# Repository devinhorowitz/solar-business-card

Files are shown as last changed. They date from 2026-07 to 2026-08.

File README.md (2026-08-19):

# SOLAR-GLOW · DRH

A business card that runs on light. An AVR microcontroller breathes four amber LEDs
*through* the board — a monogram cut into the front copper that glows when the rear LEDs
backlight it through the bare fiberglass — while a pair of indoor solar cells trickle-charge
a supercapacitor bank that holds the charge.

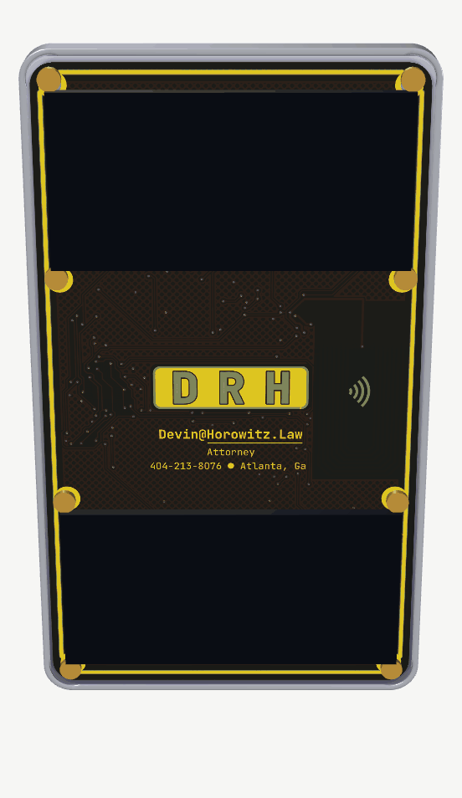
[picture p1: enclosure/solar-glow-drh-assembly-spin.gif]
SOLAR-GLOW · DRH — the assembled card turned over: titanium back-shell, resin brace, PCB, 8× M2 brass


<sub>The assembled card — Ti back-shell, resin diffuser brace, 0.60 mm PCB and eight M2 brass screws.
Not an artist's impression: every surface is the committed STEP-derived STL, the outline and the
eight mount positions come straight out of the `.kicad_pcb`, the Z stack is the one
`enclosure/fit_rules.py` enforces, and the show face is the **raytraced board itself** — the
monogram window, the ENIG, the contactless mark and the contact line are the real artwork, not a stand-in.
Re-route the front and this picture follows. Stills, the exploded and reverse views, and the full
respin are in [`enclosure/README.md`](enclosure/README.md).</sub>

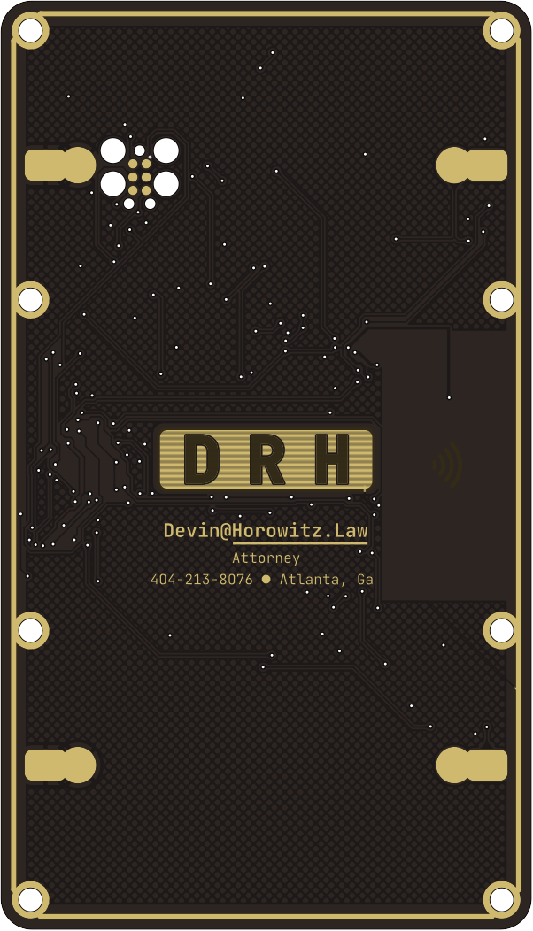
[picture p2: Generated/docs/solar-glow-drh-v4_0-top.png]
SOLAR-GLOW · DRH — front and back, gold ENIG on black soldermask


> **Status: v4.0 (managed-solar redesign) in progress** -- working files are `v4_0`, currently the v3.0
> baseline being reworked to the AEM10300 active-harvest architecture (see the design-notes v4 addendum +
> `v4-aem10300-prewiring.md`). **v3.0 -- fully routed, audit-clean, not yet fabbed -- is frozen as the final
> unmanaged-solar revision.**
> Two-layer, 0.6 mm FR4, bound for PCBWay; the 4-layer **v2.3** is the fallback design, kept in git history (not the working tree).
> The one thing standing between here and a build is the **energy budget** — harvest vs. draw under
> real indoor light has never been measured. See *“The open question.”*

### Current revision — the one canonical summary

| What | Current | Notes / fallback |
|---|---|---|
| **PCB** | **v4.0 - 2-layer** (F / B) | GND = full-board B.Cu pour; VS = routed B mesh. **v2.3 (4-layer: F / In1 GND / In2 VS / B) is the fallback design, in git history.** v2.1 was 6-layer (history). |
| Board | 50.80 × 88.90 mm, r3.0 corners, **0.60 mm** FR4, ENIG, matte-black mask | 0.6 mm — committed in the board stackup (frees the shell floor to 1.0 mm) |
| Mounting holes | **8× M2, GND** -- 4 corner (MH1-4) at **(2.87, 2.87) / (47.93, 2.87) / (2.87, 86.03) / (47.93, 86.03)** (pitch **45.06 × 83.16 mm**) + 4 panel-corner (MP1-4) at **(2.87, 28.63) / (47.93, 28.63) / (2.87, 60.27) / (47.93, 60.27)** | corners concentric with the r3.0 fillets; MP1-4 at the E/W mid-edges for the shell clamp |
| **Enclosure** | **Ti back-shell** - 1.00 floor, 1.80 cavity, overall **3.55 mm**; center support via the single-piece resin diffuser brace. **Respun 2026-07-29 against the real board** — the brace had 593 mm³ of resin inside three supercaps and the shell lip sat on 4.17 mm² of live pad; both geometries are now computed from the board and gated by `check_consistency` **[8]**. | 8-hole pattern (4 corner + 4 panel-corner); see [`enclosure/README.md`](enclosure/README.md) |
| BOM | **generated from the design** — there is no hand-authored master; most passives 0402 with the precision/bulk set on **0603** (C4/C13/C25/C22/C23/R5/R6/R15/R16) and **0805** (C26/C27); **SJ1 removed outright 2026-07-30** (lineage row only); Q2 + R18 added by the cold-start-deadlock fix | line items come from `scripts/bom_split.py` (schematic + the board's own `exclude_from_bom`/`dnp` flags); the buy documents are written into `Generated/fabdocs/` every CI run; live availability + pricing in `BOM/README.md` (`python3 BOM/check_stock.py`). Both `*-BOM.xlsx` masters were culled 2026-08-02 and live in git history |
| Firmware | AVR64EA28 C, register-verified **and compile-verified in CI**; not yet on hardware | LED pin map re-mapped in v3.0 (see `firmware/README.md`) |

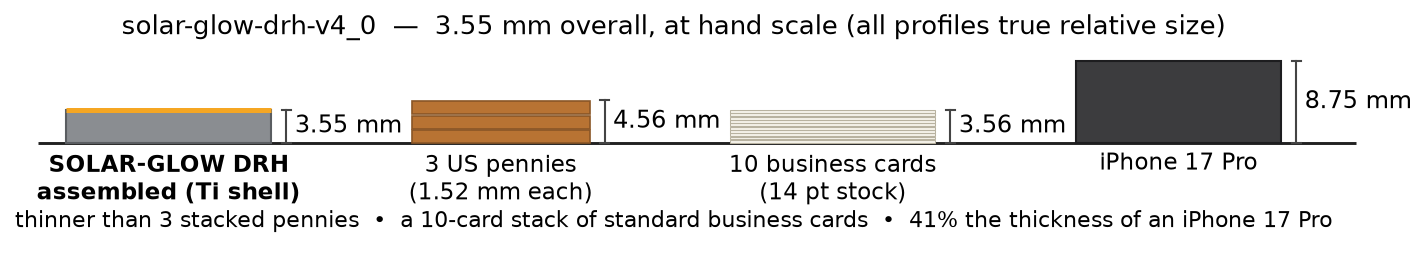
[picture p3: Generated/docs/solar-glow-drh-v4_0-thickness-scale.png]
3.55 mm at hand scale: thinner than 3 stacked pennies, a 10-card stack of business cards, 41% of an iPhone 17 Pro


*How thin 3.55 mm is, in things a hand already knows — thinner than three stacked pennies, almost exactly a ten-card stack of standard business cards, 41% of an iPhone 17 Pro. True relative scale; the card's number is measured from the committed back-shell STL by `scripts/ref_figures.py`, so the figure follows the artifact.*

### Where the truth lives — how these docs stay from drifting

Each fact has exactly one home; everything else points at it rather than restating it.

| Domain | Source of truth |
|---|---|
| Board copper / geometry / holes | `PCB/solar-glow-drh-v4_0.kicad_pcb` + `.kicad_sch` |
| Back-shell medallion (ring text, monogram, serial №) | `enclosure/medallion.py` — the shell generator and its drawing both import it; bump `SERIAL` there and CI regenerates the STEP/STL/drawing (a kibot trigger since 2026-07-31) |
| Fabrication panel (PCBWay) | `scripts/panelize.py` — derived from the board on every CI run into `Generated/panel/`; never hand-maintained |
| README renders | `scripts/render.py` — raytraced from the board/panel on every CI run into `Generated/docs/`; add a target there rather than committing a hand-made image |
| Enclosure **fit rules** | `enclosure/fit_rules.py` — one home for the brace footprint, the lip bands and the boss scallops; both generators import it and check [8] asserts it |
| Enclosure part positions | `enclosure/board_parts.py` — true body ∪ pads, read from the committed `.kicad_pcb` |
| Enclosure geometry | `enclosure/solar-glow-drh-v4_0-backshell-0p6b-brace-cad.py` (prints the Z-stack; regenerates the STEP) |
| Assembly views | `enclosure/assembly_render.py` — regenerated from the STLs + the board; not hand-made |
| Firmware pin map + knobs | `firmware/board.h` (+ `firmware/README.md`; both match the schematic) |
| BOM | **the design itself** — `scripts/bom_split.py` derives every line from the schematic plus the board's `exclude_from_bom`/`dnp` flags, and writes the two buy documents into `Generated/fabdocs/` on each CI run. `BOM/README.md` is **derived too**: a live stock/lifecycle/price table regenerated by `BOM/check_stock.py` (needs distributor API keys, so manual-apply like the mask art). _(There is no spreadsheet master; both `*-BOM.xlsx` files were culled 2026-08-02 — git history only.)_ |
| Design *reasoning* / lineage | `solar-glow-drh-design-notes.md` |
| Open work / cross-domain to-dos | `TODO.md` (an index of what's left; each item points back at the files above) |

When a number here disagrees with a source-of-truth file, the source file wins and this table is the
thing to correct. The `solar-glow-drh-v2-*` docs are v2-era history (banner-marked at the top of
each); read them for lineage, not for current values.

---

## What it is

A business-card-sized PCB — **50.8 × 88.9 mm, 0.6 mm FR4, ENIG, rounded corners** — that:

- **Harvests** indoor light with **two** ANYSOLAR solar cells merged into a single solar node (SRC) that feeds the AEM10300 harvester (U8),
  which runs the MPPT and handles reverse-blocking so neither panel back-feeds the
  other - the v3 per-panel blocking diodes are removed.
- **Stores** energy in **four** series-parallel supercapacitors -- a **hybrid tank** (two larger
  SS17 cells + two WS17), **1.40 F at 5.5 V** — two EQUAL 2.8 F stages (SC1∥SC2 above MID, SC3∥SC4
  below), **≈ 21 J nameplate but 15.1 J stored and 9.8 J spendable** once the AEM's strapped 4.65 V
  `VOVCH` ceiling and the 2.75 V glow floor are applied — with the AEM10300 harvester (U8) balancing
  the series midpoint (MID) against leakage mismatch between those two identical stages; the safe 3.3 V VS rail
  is set by the U9 TPS7A0233 LDO, not a shunt clamp.
- **Glows** by back-lighting a **“DRH” monogram** that’s cut into the front copper: a gold
  ENIG field with the three letters opened to bare FR4. Four reverse-mounted amber LEDs on the
  back fire up through the translucent substrate, so the letters themselves light up — and PWM
  on the LED drives makes them breathe.
- **Wakes** to a **tap.** A 3-axis accelerometer feels you pick the card up (or the enclosure
  being tapped) and interrupts the MCU out of sleep — no button, no moving parts.

The front face stays naked — solar cells and the glowing monogram exposed — and the dense work
all lives on the back, ready for an optional machined-metal back-shell.

> **A note on lineage:** earlier revisions (REV J and before) were *generated from Python* —
> geometry and Gerbers emitted by script, no layout tool in the loop. **v2.1 is a full KiCad
> design** (schematic + board), continued through v4.0. The old generators are kept only as
> history; the KiCad files are the source of truth.

---

## How it works

| Block | Part | Notes |
|---|---|---|
| MCU | **AVR64EA28** (28-VQFN) | TCA0 hardware PWM, I²C to the accel, charge/sleep logic; 2026-07 family swap from the AVR64DD28 (12-bit diff ADC + PGA; no MVIO on the EA, so the DD-era SJ1 strap was deleted outright, 2026-07-30) |
| Solar | **2× ANYSOLAR SM141K06TF** | monocrystalline indoor cells (Voc 4.15 V), in parallel — two panels ≈ 2× the harvest |
| Harvest PMIC | **e-peas AEM10300** (U8, QFN-28 4×4) | MPPT buck-boost that merges both panels at SRC and charges the supercap tank (STO) - replaces the v3 per-panel blocking diodes |
| Storage | **2× SCHURTER 3-153-440** (SS17, 1.8 F) + **2× 3-153-438** (WS17, 1.0 F) | hybrid tank, 2.75 V/cell, wired 2S2P as **two EQUAL 2.8 F stages** (SC1∥SC2 `STO`→`MID`, SC3∥SC4 `MID`→`GND`) → **1.40 F @ 5.5 V**; ≈ 21 J nameplate, **15.1 J stored** at the AEM's strapped 4.65 V ceiling, **9.8 J spendable** above the 2.75 V glow floor. AEM holds MID against *leakage* mismatch between the two identical stages — not a capacitance imbalance; there isn't one |
| Midpoint balance | **AEM10300 (U8) BAL** | the harvester balances the 2S supercap midpoint (MID net) - replaces the v3 ALD910025 dual SAB MOSFET |
| Rail regulator | **TI TPS7A0233PDQNR** (U9, X2SON-4 since 2026-08-05) | nanopower LDO (~25 nA Iq) regulates STO down to the fixed **3.3 V VS rail** the MCU + accel run on - replaces the v3 TLV3011 + PNP shunt clamp |
| LEDs | **4× ams OSRAM LA P47F** (amber) | reverse-mount; glow through the FR4 window, **150 Ω** ballast each |
| LED master switch | **SW2** (solder-bridge) | OFF / ON — bridged feeds `ANODE` straight from `STO`, open is a true hardware off _(the TINY dim position and its R12 shared ballast were deleted 2026-08-05; PWM duty owns dimming)_ |
| Motion | **ADI ADXL367** | 3-axis accel; tap / double-tap wakes the MCU via interrupts; 0.89 µA (swapped from LIS2DH12 on backorder) |
| Light sense | **R5 / R6 divider → PD2** | SRC ÷ 2 off the *merged solar input* (not the rail) - tracks light directly; doubles as wake-on-light |
| NFC | **NXP NT3H2211** (NTAG I²C plus 2K) | present from v3.0 - a contact **vCard** a phone taps to save; field-detect (FD, PA6) also wakes the glow - I²C `0x55`, shares the accel's bus; VCC **power-gated by `U6`** (`NFC_EN`/PA7, off by default); the **U7 MB85RC512TY FRAM** (I²C 0x50, C28) rides always-on VS parked in its 0.2 µA I²C Sleep mode (the 2026-07-23 back-power fix - see design notes) |

**Breakouts and features:** a **TC2030** Tag-Connect pad (`TC1`) for hands-free UPDI
programming, a backup UPDI header (`J1`), a **5-pad bench strip** on the back east edge
(`TP1` SRC + `JP1` GND/STO/SCL/SDA - bare SMD probe pads for bench power injection and an I²C
tap; pinout in `solar-glow-drh-v2-hardware.md`), and **eight grounded M2 mounting holes** (four corners + four panel-corner at the E/W mid-edges). (The `SB1–4`
bridges — per-LED **force-on**, not "disable" as this line long said — were deleted with TINY mode on 2026-08-05. The DD-era
VDDIO2 tie jumper `SJ1` is gone — DNP'd at the AVR-EA swap, deleted from the schematic and board outright on 2026-07-30. The v2-era
`JP1`/`JP2` 2.54 mm breakout headers are gone; the `JP1` name is reused for the strip.)

Full part numbers, pricing, and per-part datasheet links are in
**[`BOM/README.md`](BOM/README.md)** - the live availability table (generated; there is no spreadsheet
master, both `*-BOM.xlsx` files were culled 2026-08-02 into git history): every orderable line carries a
live-verified distributor P/N, stock and price, re-checked by `BOM/check_stock.py` rather than typed. **U6 is moving to
TPS22916CYFPR** (DSBGA-4 YFP, 0.5 mm max — the 2026-08-06 ultrathin swap; schematic done, board sync pending — see
`PCB/README.md`'s BOM table. It succeeds the TPS22919 SC-70 that landed 2026-08-05 — itself the leakage upgrade over
the `TPS22917DBVT` — trading +8 nA typical OFF-state leakage for 0.6 mm of height and a 16× better ON-state IQ,
so every component clears 1.1 mm for the ultrathin-card option) with **R14 (1 M `NFC_EN` pulldown)**; the stale
JP1/JP2 rows are dropped (the `JP1` designator is reused in v3.0 for the bench pad strip - bare pads,
no BOM part). Passives are X7R / AEC-Q200 / precision grade: most on **0402** lands, with the
stability upsizes on 0603 (C22/C23, R5/R6, R15/R16, plus the bulk caps C4/C13/C25) and 0805
(C26/C27, and C9's NFC tank cap — fitted 47 pF, derived not trimmed). SJ1 is culled. Lineage: v2.2 added the NFC parts (U5 / C8 / C9 / R13); the `v2 2` and older
BOM files stay in the repo as history.

---

## The board

- **Two copper layers** on 0.6 mm FR4 (v3.0): **F.Cu** signal/parts and **B.Cu**. **GND is a
  full-board B.Cu pour** (`GND_B` zone) with stitch straps, and **VS is a routed mesh on B** — the
  4→2-layer conversion of v2.3, whose internal GND/VS *planes* moved onto the back copper. The
  4-layer **v2.3** (F · In1 GND · In2 VS · B) is the fallback (recoverable from git history) if the
  back-side trace texture showing faintly on the naked front reads wrong.
- **The glow window is a keepout on every layer.** The monogram cutout and the four LED
  light-paths are voided through both layers so nothing — copper pour, trace, or via —
  shadows the light between the rear LEDs and the front face. The rear soldermask is left
  *open* over the window on purpose: bare ENIG reflects the LEDs’ light forward instead of
  absorbing it.
- **Rail discipline.** The supercap stack can sit near 5.5 V, but the accelerometer tops out at
  3.6 V - so the **U9 TPS7A0233 LDO** regulates the supercap tank (STO) down to the fixed
  **3.3 V VS rail**, directly bounding what the accelerometer sees. Its ~25 nA quiescent
  draw is negligible against the other always-on loads, and it regulates VS itself rather
  than the solar input. (v3's TLV3011 + PNP shunt clamp and the per-panel blocking diodes
  are gone - the AEM10300 now owns the harvest path.)
- **Power planes** carry the supercap charge/discharge currents; the four cells eat the better
  part of the back, so the layout is geometry-bound and the planes earn their layers.

---

## The open question — read this before building a batch

The board is well-verified; the **energy budget is not.** A solar cell’s headline rating is a
full-sun number, and indoor light delivers a small fraction of it, while four breathing LEDs
average several milliamps. The two-panel harvest and the tank — **9.8 J spendable**, not the 21 J
nameplate — are sized to **harvest
slowly and glow in bursts** — but that bet has never been put on a meter.

What changed the math since the early notes: the LED string is fed from the **STO supercap tank** (through the
SW2 anode switch), which the AEM10300 holds at up to **4.65 V** (VOVCH), and the ballasts are **150 Ω** -- so each
LED peaks near **~16 mA** at a full tank ((4.65 V - amber Vf ≈ 2.25 V)/150 Ω, the figure `firmware/README.md`
quotes), sagging toward zero as STO discharges. (VS, the regulated 3.3 V LDO output, powers the MCU and accel,
not the LEDs.) Four on at once is a real load against an indoor harvest measured in fractions of a milliamp.

**First move when boards arrive:** put the cells under your actual target lighting and measure
**harvest current against LED draw** before you populate a full stack. That single number sizes
the duty cycle, the feature set, and whether the always-on accelerometer earns its microamps.

---

## Repository layout

```
solar-business-card/
├── README.md                       # this file (canonical current-revision summary)
├── PCB/                            # KiCad projects
│   ├── solar-glow-drh-v4_0.kicad_pcb   # the board: v4.0 managed-solar rework (AEM10300), 2-layer (source of truth)
│   ├── solar-glow-drh-v4_0.kicad_sch   # schematic: synced to the v4.0 board netlist
│   └── README.md                       # order & build guide
├── BOM/                            # bill of materials (moved from PCB/ 2026-08-01)
│   ├── README.md                       # GENERATED live availability/price table (check_stock.py)
│   ├── check_stock.py                  # live DigiKey/Mouser availability check -> README.md
│   └── README.md                       # DERIVED: stock/lifecycle/price table with red-X dead lines (regenerate, don't edit)
├── solar-glow-drh-design-notes.md  # design rationale, energy model, lineage (incl. the v3.0 chapter) — the one prose file that stays at root, beside this README
├── docs/                           # project notes & records (moved from root 2026-08-01) + the LED sweep tuner
│   ├── solar-glow-drh-v2-hardware.md    # as-built wiring & pin map (v2-era lineage; banner at top)
│   ├── solar-glow-drh-v2-mechanical.md  # board mechanics, keepouts, access (v2-era lineage; banner at top)
│   ├── v4-aem10300-prewiring.md         # the v4 net/pin plan — applied 2026-07-30, kept as the record
│   ├── v4-schematic-sync-checklist.md   # the sch→board sync procedure — DONE, kept as the record
│   ├── harvest-bench-fixture-handoff.md # the energy-budget bench fixture (the #1 open gate's rig)
│   ├── harvest-budget-test-board.md     # the harvest test-board concept
│   ├── eink-display-variant-notes.md    # e-ink variant study (concept, not adopted)
│   ├── firmware-to-pcb-open-items.md    # v3-era cross-team memo (SUPERSEDED; record only)
│   ├── mcp-setup.md                     # sourcing MCP servers setup (DigiKey/Mouser)
│   ├── kicad-happy.md                   # the external second-opinion analyzer: pinned run recipe + the 2026-08-01 baseline triage
│   ├── thomsonlint.md                   # the ontology-guided second reviewer: pinned run recipe + the 2026-08-01 review record
│   └── led-sweep-tuner.html             # interactive LED-constant sandbox (firmware/README links it)
├── firmware/                       # bare-metal C (AVR64EA28); compile-verified, see firmware/README.md
├── bench/                          # pogo-plate bench monitor: Pico firmware + host dashboard (see bench/monitor)
├── datasheets/                     # fitted parts + documented substitutes, named "REF  MPN  $price.pdf"
│                                   #   (survey sheets and replaced-part docs culled 2026-08-01 — git history)
├── enclosure/                      # Ti back-shell + resin brace: CAD / STEP / STL / drawings / assembly views
│                                   #   fit_rules.py + board_parts.py = the geometry both generators derive from
└── (v0-prototype/ and enclosure/engraving-studies/ culled 2026-08-02 — concluded history, kept in git history; the medallion the studies produced ships in enclosure/medallion.py)
```

---

## Building the board

The board is a KiCad project — open it, run DRC, and export the fab set:

1. Open `solar-glow-drh-v4_0.kicad_pro` in **KiCad** (2026 file format).
2. **Run DRC.** It comes back clean apart from the intentional exceptions catalogued in
   `PCB/README.md` and `solar-glow-drh-design-notes.md` (the NFC coil `LA`↔`LB` short, the eight
   GND-tie mounting-hole/gold-frame contacts, the two plating-bus stubs crossing Edge.Cuts at
   x=25.4, the illumination copper inside the glow window, and the benign `lib_footprint_issues`
   plus the **intentional** `BTN` global label on PA5 — the documented future-button pin
   (a deliberate no-fit; recipe in `firmware/README.md`), not a loose end). Fill zones (press **B**) before checking.
3. **Plot Gerbers + drill** from KiCad's own Fabrication Outputs and order from **PCBWay**
   (**2-layer**, 0.6 mm; selective hard gold + plating bus + resin-fill/cap per `PCB/README.md`).

> The supercap land is the one thing to never get wrong. **Both** SCPC cells — the 39 mm
> **SS17** (SC1/SC3) and the 28.5 mm **WS17** (SC2/SC4) — solder to **flat pads under the body**
> (the asymmetric P/N widths are the polarity key), **not** to the folded end tabs, which are
> non-solderable mechanical locators. The footprints here are built to the correct under-body
> land; don't substitute an end-tab land.
>
> Mind the two lengths. Assuming every cell was the 28.5 mm WS17 is exactly what put 593 mm³ of
> brace inside SC1 and SC3 — see [`enclosure/README.md`](enclosure/README.md).

---

## Assembly order (when boards arrive)

1. **Validate the energy budget first** — harvest vs. LED draw under real lighting (above).
2. **Reflow the SMD parts** — the QFN MCU and the LGA accelerometer need hot air / a hotplate;
   the EP and the accel pad reflow to their planes.
3. **Flash firmware** over UPDI — the Tag-Connect pad (`TC1`) is the no-header path; `J1` is the
   backup header. **This step moved ahead of the cells on 2026-07-30**, when TC1 was deliberately
   moved to `F.Cu`: PV1's body covers the pad cluster, so a pogo cable cannot reach it once the
   cell is on. The trade is a good one — the old position was under `SC1`, which is *reflowed*, so
   the window used to close before the board was even finished. See the warning box in
   [`PCB/README.md`](PCB/README.md).
4. **Hand-solder last** — the solar cells (heat-sensitive: ≤ 260 °C / 2 s, no IPA), and set the
   **SW2** bridge: bridged = ON, open = OFF.

---

## Firmware

A first implementation now lives in **`firmware/`** — bare-metal C, **verified at the register
level** against the AVR64EA28 and ADXL367 datasheets and **compile-verified in CI** (warning-free
against the AVR-Ex DFP; not yet run on hardware). Its knobs, wake model, and power notes are in
**`firmware/README.md`** (authoritative); the wiring it targets is **`firmware/board.h`**, which
`check_consistency` **[1]** holds against the schematic netlist pin by pin. (The complete v2-era
pin map in **`solar-glow-drh-v2-hardware.md`** is lineage, not a current source — see the truth
table above.) Final
duty-cycle and feature tuning stay **gated on the energy-budget measurement** below. In short,
the board gives it:

- **LED breathing** — the four LEDs sink into **PA0–PA3 = TCA0 WO0–WO3**, so split-mode PWM
  drives all four as independent 8-bit channels (the 150 Ω ballast sets the peak; PWM sets the
  average, so you trim brightness *below* that ceiling).
- **Tap-to-wake** — the accelerometer’s two interrupts land on **PF1 / PF0**; configure
  tap / double-tap and let it pull the MCU out of sleep.
- **NFC contact tag** — `U5` (NXP NT3H2211, on the board from v3.0) carries a **vCard** a phone reads on a
  tap to save the contact (RF-powered, so it reads with the cap flat), and its **field-detect**
  line wakes the same glow. The tag has no sleep state and would draw **~195 µA** continuously — the
  card's largest idle load — so firmware **power-gates** its VCC through a load switch (`U6`) on
  **NFC_EN (PA7)**, held **off by default** and raised only around an I²C access; the vCard read and
  the FD-wake both run on the phone's field power, so they still work with the tag's VCC off. Shares
  the I²C bus with the accel (`0x55` vs `0x1D`). See `firmware/README.md` → *NFC contact card*.
- **Light sensing** - the divider taps the **merged solar node SRC** (SRC ÷ 2) into **PD2** (AIN2), so it
  reads light directly — ~0 V dark, rising under light; firmware adapts the glow to available
  light and can also read **VDD/10** and the internal temp sensor.
- **Wake-on-light** — the card can also wake when light appears, with no tap. The implemented
  path is an **RTC-timed ADC poll** in deep Power-Down (sample PD2/AIN2 every ~1–2 s, glow on a
  dark→light rise). The tempting *instant* AC0-comparator version was checked against the
  datasheet and found **non-viable on this part** — the AC interrupt doesn't update with the
  peripheral clock stopped, and the AC isn't a Standby/Power-Down wake source, so it would never
  fire. Instant response isn't lost: the accelerometer interrupt wakes from Power-Down, and
  picking the card up to carry it into the light *is* that motion. (Standing current: **≥ ~2.7 µA — a
  2.0 V-referenced lower bound, not a measurement** (the 2026-08-01 pressure test found the NFC tag's
  FD-pin leakage, 1.5 µA typ / 10 µA max, unbudgeted in that sum) — the always-on accelerometer
  (ADXL367, 0.89 µA typ *at 2.0 V*) no longer dominates it, and neither the poll nor the NFC tag do,
  the latter being power-gated off by default — see `firmware/README.md` "Power notes" for the honest
  ledger and the bench item.)
- **Low-power housekeeping** — `VREGCTRL.PMODE = AUTO` for sub-µA power-down; RTC/PIT off the
  internal ULP oscillator (no crystal); an EEPROM “times-activated” counter that survives a
  full supercap drain; and the core **IDLE-sleeps through the breathing glow** while TCA0 keeps
  the PWM running, rather than busy-waiting. (An autonomous CCL + EVSYS light-wake is a possible
  v-next, but isn't what the current firmware does.)

Still open (what the bench measurement unlocks): final breathing-curve and tap-gesture tuning,
charge / brown-out management around the supercap bank, and the duty-cycle adaptation the
harvest number sizes.

---

## Enclosure

A back-only **machined-titanium** shell hugs the populated rear; the front stays naked. A
single-piece **resin diffuser brace** fills the cavity, carries centre support, backs the
monogram window and holds the ferrite over the NFC coil. CAD, STEP, STL, fab notes and
dimensioned drawings are in `enclosure/` — full detail in
[`enclosure/README.md`](enclosure/README.md).

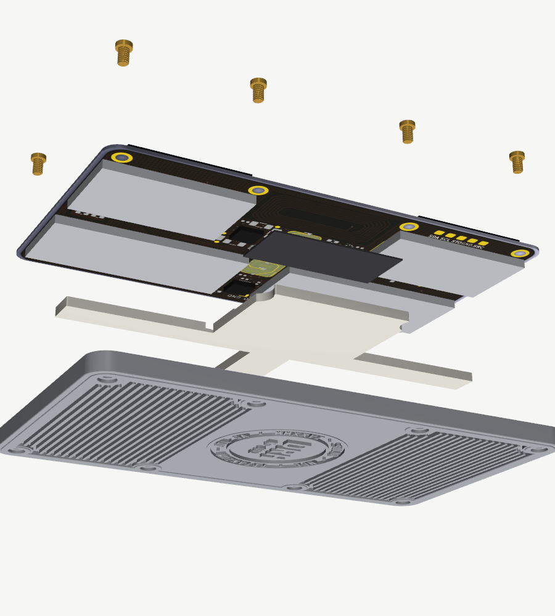
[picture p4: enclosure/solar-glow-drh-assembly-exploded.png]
Exploded: titanium shell, resin brace, PCB, 8× M2 brass


**Respun 2026-07-29 against the real board, because neither part would have assembled.** The
brace's middle band was sized for supercap bays ending at y31.15 / y57.75 — the 28.5 mm WS17
length — while SC1/SC3 are 39 mm SS17 cells, so it put **593 mm³ of solid resin inside three
1.70 mm cans**. The shell's support lip landed on nine B-side parts including **4.17 mm² of
live pad** (`STO`, `STO_LDO`, `VS`, `NFC_EN`) under grounded titanium — fitting it shorted the
storage rail — and five of the eight M2 bosses fouled a part, two on live nets.

Both geometries are now **computed from the board** (`enclosure/fit_rules.py`, reading part
positions from `enclosure/board_parts.py`) rather than hand-placed, and gated by
`check_consistency` **[8]**. Interference is structurally impossible: a part the brace cannot
span is *subtracted* from its footprint rather than pocketed. No board change was required.

The decisions that matter once it's cut: **titanium (Ti-6Al-4V Grade 5)**, **3-axis CNC-milled**
by PCBWay, **bead-blast** finish. The cavity is **cap-limited to 1.80 mm** by the four 1.70 mm
supercaps; the floor is a **true uniform 1.00 mm** (the old 0.05 mm U7 relief pocket was deleted
2026-07-28 — U7 is the 0.90 mm DFN-8, not the 1.75 mm SOIC it was sized for); overall height
**3.55 mm**. **Eight** bosses on the v4 8-hole pattern (four corner, concentric with the r3.0
fillets, plus four panel-corner), each **scalloped** clear of whatever fouls it while keeping
≥ 92.3 % of its M2 thread annulus. Retention is **eight M2×3 slotted brass screws**, not a press
fit; the head is Ø3.0 and the tip lands **flush** in a Ø3.0 back spotface.

The electrical gotchas: the screws tie the metal body to board GND, so the enclosed variant
**drops the edge castellations** (or adds a die-cut Kapton layer) so nothing shorts to the
grounded shell; the **accelerometer tap is the actuator** (cap-touch dies behind a grounded
plate); and the east lip is held **1.00 mm clear of NFC coil copper measured at x48.550** — a
grounded feature over the antenna detunes it, and the constant it used to be sized against
(48.40) was optimistic enough to overhang.

---

## Cost

- **Per-board parts cost: see [`BOM/README.md`](BOM/README.md)**, the live table — and the **four supercaps are the dominant line** —
  well over half the BOM. This is a showpiece, not a hand-out-by-the-hundred card.
- The energy tank is where the money goes; everything else is comparatively cheap.

---

*© 2026 Devin R. Horowitz. Released under the [MIT License](LICENSE).*

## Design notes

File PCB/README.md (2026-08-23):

# SOLAR-GLOW · DRH - PCB (v4.0): Order & Build Guide

<table>
<tr>
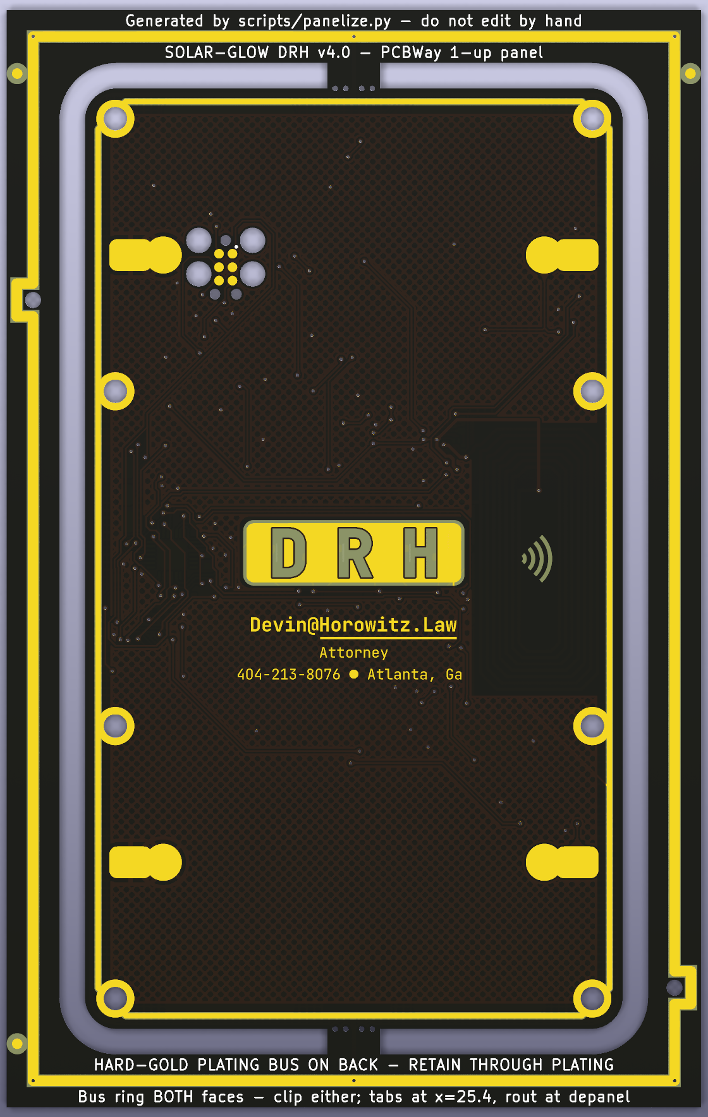
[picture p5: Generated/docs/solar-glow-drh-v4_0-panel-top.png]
Panel, front — the card face, gold monogram on matte black, still in its frame
<td width="50%"></td>
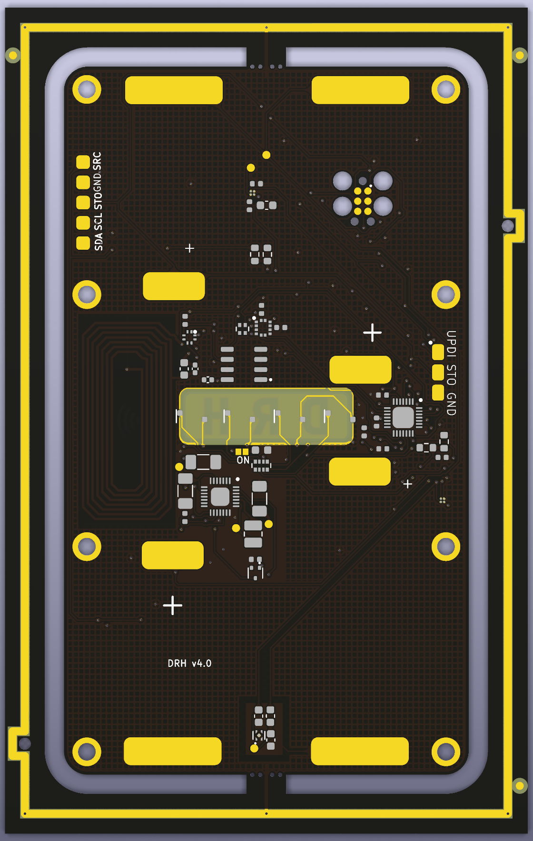
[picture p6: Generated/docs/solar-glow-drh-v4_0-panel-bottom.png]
Panel, back — the component side, NFC coil and LED window, still in its frame
<td width="50%"></td>
</tr>
<tr>
<td align="center"><b>Front</b> — the card face</td>
<td align="center"><b>Back</b> — the component side</td>
</tr>
</table>

**This is what PCBWay ships**: the 1-up card still attached to its 65.6 × 103.7 mm frame, before
you snap the two tabs. The gold ring inset in the frame is the hard-gold plating bus, mask-opened
so the plating rack has bare copper to clip, with a spur crossing each break tab into the card at
x = 25.4. Both faces are raytraced from the panel CI actually generates — see
`scripts/render.py`, and "The PCBWay panel" below. No components are shown because none are
fitted at this stage; that is the fab's deliverable, not an omission.

## Assembled

<table>
<tr>
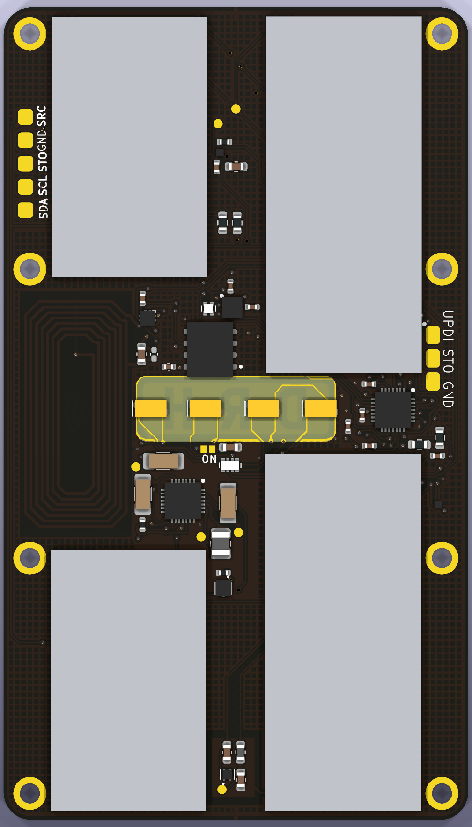
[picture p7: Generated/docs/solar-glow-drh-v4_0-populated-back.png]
Assembled card, back — supercaps, MCU, harvest PMIC, NFC coil and passives fitted
<td width="50%"></td>
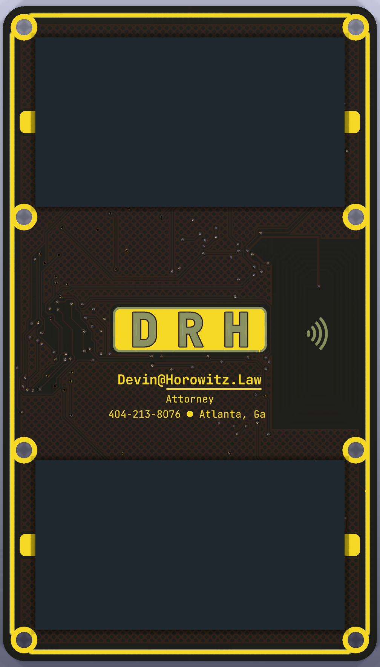
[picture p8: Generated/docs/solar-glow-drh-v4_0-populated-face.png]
Assembled card, front — the two indoor solar cells over the monogram window
<td width="50%"></td>
</tr>
<tr>
<td align="center"><b>Back</b> — 53 fitted parts</td>
<td align="center"><b>Front</b> — the two solar cells</td>
</tr>
</table>

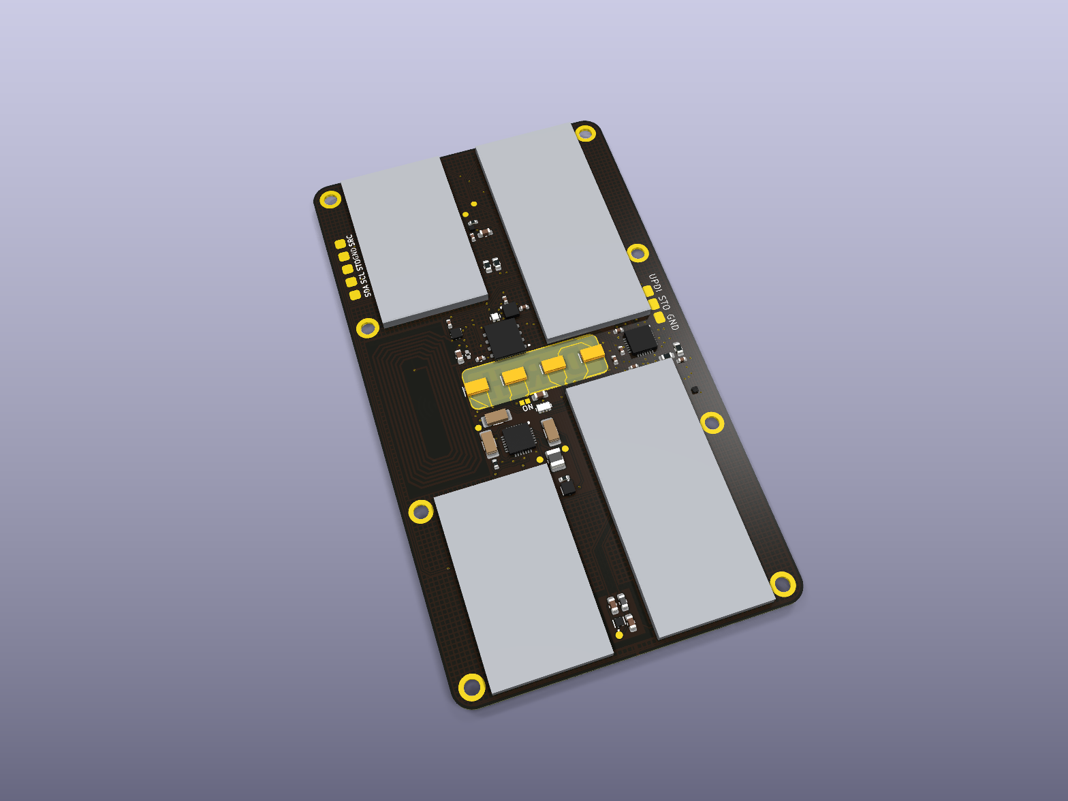
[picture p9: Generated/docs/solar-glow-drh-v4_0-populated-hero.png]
Assembled card, hero angle


The same board with its components on: 52 of the 73 footprints carry a 3D body, which is every part
that actually gets populated (recounted 2026-08-05 after SB1–4 and R12 left with TINY mode; the
2026-08-01 count was "53 of 78"). The other 21 are the drill/mount set (MH1–4, MP1–4, `NPTH_mech`),
the SW2 solder bridge, the bare programming and probe lands (TC1, `TC1/b`, TP1–TP7, JP1),
and **J1**, which is DNP.

> **Read the big grey slabs as ENVELOPES, not as photographs.** The four supercaps, the two solar
> cells, the LEDs, both QFNs, the FRAM, the accelerometer and the NFC tag are **clearance solids**
> generated by `scripts/make_3d_models.py` — each is its part's maximum outline at its **maximum**
> height, because the question they exist to answer is "does the brace clear it?" and a pretty model
> at the wrong height would be worse than useless. They are not appearance references. The chip
> passives and SOT-23s are stock KiCad models and do look roughly like the real parts.
>
> The supercap **locator tabs are deliberately absent** — see `TODO.md`; their real folded geometry
> has never been measured, so the envelope near the two short edges is unverified.
>
> **Every body you see is rendered from this repo, not from a KiCad install.** The nine stock models
> live in `PCB/kicad-3dmodels/` because the image CI renders in carries no 3D library at all — that
> was measured, not assumed (`models: 15/53 resolve ... NO stock 3D library found`), and it is why an
> earlier version of this render was missing every chip passive and both SOT-23s. `render.py` points
> `${KICAD10_3DMODEL_DIR}` at the vendored copy when the host has none, and consistency check [5]
> fails if a new part references a stock model nobody vendored.

---

This folder holds the **board** for SOLAR-GLOW · DRH — the KiCad project, the bill of
materials, and the artwork reference for the SW2 selector. It is the thing you fab and
populate. This README is the procedure: **how to order the bare PCB, how to order the
parts, and how to build the assembly.**

> **One revision lives here.** As of 2026-07-28 that is **v4.0**; the seven `*-v3_0.*` files
> (board, schematic, project, prl, dru, and both BOMs) were removed, the same way v2_1–v2_3 were
> before them. Superseded revisions are kept by git, not by this folder — carrying a second 1.6 MB
> board around only invites someone to open the wrong one. To get one back:
> ```sh
> git log --diff-filter=D -- PCB/solar-glow-drh-v3_0.kicad_pcb   # the commit that removed it
> git show <sha>^:PCB/solar-glow-drh-v3_0.kicad_pcb > /tmp/v3.kicad_pcb
> ```
> **`enclosure/solar-glow-drh-v4_0-backshell-*` is unaffected.** Those files are current and
> fab-ready. _(They carried `v3_0` names until 2026-08-19 — the revision the shell was first cut
> against — and this note used to explain why that was fine. It stopped being fine when the
> DRAWING generator was found stamping **`REV v3.0`** into the title block of the sheet a
> machinist cuts to; a stale revision on a fab document is not a naming preference. Renamed and
> re-stamped to v4.0 in one commit. The v4 board carries the identical 8-hole pattern, so the
> geometry never moved.)_

```
PCB/
├── solar-glow-drh-v4_0.kicad_pro     # KiCad project (open this)
├── solar-glow-drh-v4_0.kicad_sch     # schematic
├── solar-glow-drh-v4_0.kicad_pcb     # board — 2-layer, routed, teardropped (source of truth)
├── solar-glow-drh-v4_0.kicad_prl     # local project state — versioned DELIBERATELY (the GUI layer setup travels with the project; unlike Generated/'s prl side-effect, which was culled 2026-08-01)
├── solar-glow-drh-v4_0.kicad_dru     # two-tier design rules (PCBWay floor + marginal band)
├── solar-glow-drh.kibot.yaml         # CI recipe — regenerates ../Generated/ on every push
│                                     # (the BOM masters moved to ../BOM/ on 2026-08-01, beside the live
│                                     #   stock checker; the tree line here that called the assembly xlsx
│                                     #   "stale at its 36-row era" was itself stale — the file was rebuilt
│                                     #   2026-07-30 at the 47-part placed set, see ../BOM/)
├── kicad-3dmodels/                   # the 9 stock KiCad .step bodies this board uses, mirroring the
│                                     #   library layout (CC-BY-SA 4.0, licence bundled). CI's render
│                                     #   image ships NO 3D library, so without these the assembled
│                                     #   render silently loses 38 of 53 component bodies.
└── DRC.rpt                           # last GUI DRC export (user-refreshed at board edits; CI keeps the live
                                      #   reports in ../Generated/. ERC.rpt was culled 2026-08-01 — its 07-27
                                      #   export had outlived two schematic generations; read Generated/…-erc.html)
                                      # (v2_1 / v2_2 / v2_3 / v3_0 revisions live in git history, not this folder)
```

> **The board is the source of truth.** `solar-glow-drh-v4_0.kicad_pcb` / `.kicad_sch`
> govern. The design *reasoning* lives one level up:
> - `../firmware/board.h` + `../firmware/README.md` - as-built pin map and net list (the firmware target); `../docs/solar-glow-drh-v2-hardware.md` is frozen v2 lineage only.
> - `../docs/solar-glow-drh-v2-mechanical.md` — board envelope, heights, mount holes, keepouts.
> - `../solar-glow-drh-design-notes.md` — why each decision was made; the landmines.
> - `../README.md` — the project overview and the standing open question (energy budget).
>
> Where a number here and a number in those files ever disagree, re-read the `.kicad_pcb`.

> **Read this before committing money: the energy budget has never been measured.** Harvest
> under real indoor light versus four breathing LEDs at the current 150 Ω ballast is an
> unproven bet. It does not stop you fabbing one board — it stops you populating a *batch*.
> See **First power & bring-up** below and `../solar-glow-drh-design-notes.md` §2.

---

## Board at a glance

| Parameter | Value |
|---|---|
| Outline | 50.80 × 88.90 mm rounded rectangle, **3.0 mm corner radius** |
| Layers | **2 copper**: F.Cu (cells, plating ties, monogram art) · B.Cu (everything else) |
| Power architecture | **GND = full-board B.Cu pour** (~3000 mm²); **VS = routed B.Cu mesh** |
| Finished thickness | **0.6 mm** FR4 |
| Surface finish | **ENIG** + **selective hard (electrolytic) gold** on the F.Cu gold set — the plating bus exists to feed it (see the order special request; the area itself is drawn on `User.1` by `scripts/mask_art.py` and plots into both fab sets) |
| Soldermask | **Matte black**, both sides |
| Silkscreen | White (back-side identifiers / logos); front face is intentionally bare |
| Components | **52 on the back**; the front carries only the two solar cells (PV1/PV2) |
| Teardrops | **Enabled** — **280** curved teardrop zones (pads, vias, and track-ends). _(Was documented as 243, then 298; recounted 2026-08-06 after DRH's Q2/C9/TC1 rework and the U6 DSBGA round — redrawn tracks shed their teardrops, and the U6 VNFC reroute retired a via and its pair.)_ R14 has none, and **the U6 DSBGA has none BY DESIGN — never add them there**: the 0.23 mm balls' pad-to-pad air gap is 0.17 against the 0.152 floor, and a teardrop's flare spends exactly that margin. **Run Tools → Add Teardrops before plotting** to regenerate the rest (the tool's own scope settings leave the BGA alone at its defaults; check it did). |
| NFC | NT3H2211 tag (U5) + **PCB-etched 7-turn coil** on B.Cu, power-gated by U6. Coil stays **under soldermask** — see the note below. A contactless mark on F.Mask over the antenna says the card is NFC-enabled |
| Front ornament | **Generated, not drawn** — `scripts/mask_art.py` opens F.Mask only where the copper beneath is GND, so the routing itself becomes the pattern (gold mesh, dark rivers). 216 mm², narrowest gold aperture 0.122 mm. Re-run `--apply` after any front re-route; consistency check [6] fails if you don't |
| Indicative parts cost | **see `../BOM/README.md`** — the live table, regenerated by `BOM/check_stock.py`, is the only current figure; supercaps + solar cells are ~60 % of it. _(This cell said "≈ $93/board" until 2026-08-04; the generated table summed to $136.60/board, so the prose was 32 % low. A hand-typed price goes stale the moment a distributor moves, which is exactly why the table is generated — do not put a number back here.)_ |

**Glow window — the one feature a fab must not "clean up."** A rectangle at
**x 14.95–35.85, y 40.8–47.0** (≈ 20.9 × 6.2 mm, board center) is a **keepout on both
copper layers** and has the **soldermask opened over it on both faces**. The rear LEDs fire
*through* the bare FR4 to light the front monogram; the open rear mask lets the gold ENIG
reflect that light forward instead of absorbing it. Tracks are allowed inside the window;
**vias, copper pour, and footprints are not.** Do not let a DFM auto-edit flood mask back
over it.

**NFC coil region — the second feature a fab must not "improve."** The east band at
**x 36.8–49.0, y 31.6–57.4** carries the etched antenna: the B.Cu GND pour is kept out of
it, and F.Cu is a keepout over it. The **LA↔LB track crossing at (41.0, 38.0) is the coil's
electrical junction — intentional, not a short.** Any DFM note offering to "fix" the
crossing or to flood the region gets declined.

---

## Step 1 — Open the project and run DRC

1. Open `solar-glow-drh-v4_0.kicad_pro` in **KiCad** (designed in the 2026 file format).
2. Register the footprint library: the board uses a local `solarglow` library that is not
   registered on a fresh machine. Add it under **Preferences → Manage Footprint Libraries**
   (or accept KiCad's prompt) so the footprints resolve.
3. **Run DRC.** The project carries a two-tier rule file (`solar-glow-drh-v4_0.kicad_dru`):
   - **error tier** = the do-not-ship floor (clearance/track ≥ 0.126 mm, annular ≥ 0.125,
     drill ≥ 0.2) — sized against PCBWay's stated 2-layer capability;
   - **warning tier** = the *marginal band* [0.126, 0.1524): PCBWay-legal geometry that is
     tighter than 6 mil, flagged on purpose so the ledger stays visible.

   **Expected result: 0 errors, 11 exclusions** (verify the exclusion count against
   `Generated/solar-glow-drh-v4_0-drc.html`, which CI writes — the catalogue's history lives in
   `CLAUDE.md`). The warning count depends on which severities the run reports: the fresh GUI
   export (`DRC.rpt`, 2026-08-01) reads **3** (the silk-over-copper trio), while CI's
   severity-all html carries the full marginal-band ledger (~61 at last count — the 0.127 mm
   west-bus corridors plus fourteen 0.15 mm track notes). This line used to promise "~61
   warnings" flatly, which only a severity-all run reproduces. The excluded set is the two gold-plating tie stubs crossing the outline, the
   LA↔LB coil junction, the seven supercap NPTHs inside courtyards, and the `TC1/b`↔SC1 courtyard
   overlap — all intentional.
   The footprints that shipped without a courtyard (U1, U8, U5, U3, D2-D5, J1, TC1) now carry
   courtyards + pin-1/cathode markers. The one accepted courtyard overlap is the **`TC1/b`
   Tag-Connect mirror under the SC1 supercap** (its ancestor — the pre-2026-07-30 B-side TC1 over
   the same can — died with the side flip and KiCad pruned the exclusion; the 2026-08-01 mirror
   recreates it deliberately: bare pads under a part body, used only before SC1 is fitted);
   courtyard-overlap is otherwise a hard CI gate. The two proximities this exposed (U8/L2, U1/J1) were resolved in the layout.
   The warnings are the marginal-band ledger (mostly the 0.127 mm parallel corridors of the
   west-side bus) plus fourteen 0.15 mm track-width notes. **Do not "fix" warnings blindly**,
   and do not be alarmed if the warning *count* differs slightly between runs — KiCad's
   row enumeration jitters on long parallel runs (see the design notes, "row-count jitter"). After any board edit — including the R14 patch — **refill zones (B.Cu) before running DRC**; the committed fills predate the patch.
4. CI runs the same DRC (plus ERC and the full fab plot) on every push and commits the
   results to `../Generated/`. If your local run and `Generated/` disagree on *substance*
   (not row counts), stop and investigate.

---

## Step 2 — Generate the fab outputs (do this in KiCad, not from a script)

There are **no Gerbers committed in this folder** — generate them fresh (or take the
CI-built set from `../Generated/gerbers/`, which comes from the same exporter).

> **Use KiCad's own Fabrication Outputs exporter.** Older revisions of this project emitted
> geometry-derived Gerbers from a Python preview script; **do not fab from those.** A preview
> emitter lacks real thermal-relief spokes, exact mask expansion, and teardrop fills. Plot
> from **File → Fabrication Outputs → Gerbers…** so the production set carries what the
> board actually specifies.

**Plot (Gerbers):**
- Layers: **F.Cu, B.Cu**, **F.Mask, B.Mask**, **F.SilkS, B.SilkS**, **Edge.Cuts**, and
  **F.Paste / B.Paste** (for the stencil — Step 5).
- Format **Gerber X2** (or whatever PCBWay's order page asks for), millimeters, 4.6 resolution.
- Leave KiCad's mask and via-tenting settings as-is. **Vias are tented** on this board (clean
  card face); confirm the plot keeps them tented and keeps the glow-window mask openings.

**Drill (Excellon):**
- **File → Fabrication Outputs → Drill Files…** Generate Excellon + a drill map.
- Plated holes: the **109** vias (uniform 0.30 mm) and the eight M2 mount holes (Ø 2.2 mm; 4 corner MH1-4 + 4 panel-corner MP1-4).
  _(Said 79 until 2026-07-30; the board had 108 and now has 109. Count it, don't quote it: `grep -c '^\t(via$'`.)_
  Non-plated: the TC2030 latch/alignment holes. Export PTH and NPTH per PCBWay's preference.

**Bundle** the Gerbers + drill into one zip for upload.

---

## Step 3 — Order the bare board (PCBWay)

Order parameters, from the committed board:

| PCBWay field | Set to |
|---|---|
| Layers | **2** |
| Material / thickness | FR4, **0.6 mm** finished |
| Surface finish | **ENIG** (**ENEPIG accepted alternate** — decide at quote; either satisfies the rule below), plus **selective hard gold** per the special request below |
| Soldermask color | **Matte black** |
| Silkscreen | White |
| Min track / spacing used | **0.15 mm track / 0.127 mm spacing** (the marginal-band corridors) |
| Vias | **Uniform: 0.30 mm drill / 0.60 mm pad** (0.15 mm annular), 79 total, tented (resin-fill + cap ordered board-wide) |
| Non-plated holes | TC2030: Ø **2.3749 mm** (4× leg-latch) and Ø **0.9906 mm** (3× alignment) |
| Plated mount holes | Ø **2.2 mm** ×8 (M2 — 4 corner MH1–4 + 4 panel-corner MP1–4, tied to GND) |
| Castellations | **None** (verified — only the corner mount holes sit within 1.5 mm of the rim) |

**Run PCBWay's DFM check against these.** The binding features are the **0.152 mm clearance
and track floors** (the OSH-governed envelope minimum, which the routing reaches in hundreds
of places) — inside PCBWay's stated 0.1 mm/4 mil 2-layer capability, but worth a glance at
their sheet. There are no fine vias on this board (the whole board runs the one **0.254/0.554**
via — since 2026-08-08 the smallest the three-fab envelope permits, OSH Park's drill floor
wearing PCBWay's 0.150 ring), and no controlled-impedance nets to declare.

> ### Three fabs, one board file (2026-07-27; JLCPCB added 2026-08-08)
>
> The design rules in `solar-glow-drh-v4_0.kicad_dru` are the **per-parameter intersection of
> PCBWay, OSH Park and JLCPCB**, so this board can be ordered from any of the three without
> re-checking anything: PCBWay for fast local prototypes and the hard-gold production panel,
> OSH Park **After Dark** (black FR4 + clear soldermask, ENIG, 1.6 mm) for the naked "midnight"
> variant, and JLCPCB as the volume alternate — the one ENIG-only fab that stocks the
> **production 0.6 mm thickness**, so it is the cheapest way to prototype the real stack
> (After Dark is 1.6 mm only).
>
> | | PCBWay | OSH Park | JLCPCB | governs |
> |---|---|---|---|---|
> | trace / space | 0.100 mm | **0.1524 mm** | 0.100 mm | OSH Park |
> | drill (plated) | 0.200 mm | **0.254 mm** | 0.150 mm | OSH Park |
> | via annular ring | **0.150 mm** | 0.127 mm | 0.050 mm | **PCBWay** |
> | copper → board edge | not stated | **0.381 mm** | 0.200 mm | OSH Park |
> | PTH pad annular ring | 0.150 mm | 0.127 mm | **0.180 mm** | **JLCPCB** |
> | PTH hole → other copper | not stated | not stated | **0.280 mm** | **JLCPCB** |
> | hole → hole, pad involved | not stated | not stated | **0.450 mm** | **JLCPCB** |
> | NPTH drill | not stated | not stated | **0.500 mm** | **JLCPCB** |
>
> Two inversions now, not one. OSH Park is the *looser* fab on via annular ring (do not relax it
> to 0.127 on the strength of their spec page; that breaks PCBWay), and JLCPCB — looser than
> everyone on trace/space/drill — is the *tightest* on every hole-adjacency number: 1 oz PTH pads
> need 0.18 mm of ring where its vias need only 0.05, plated holes want 0.28 mm to foreign copper,
> any hole pair involving a pad wants 0.45 mm wall-to-wall, and it drills no NPTH under 0.50 mm.
> Those four axes had no gate before because neither earlier fab published a limit the board could
> get near; they are now **conditioned rules** in the `.kicad_dru` (the via fleet keeps its
> PCBWay-governed 0.1499 ring, untouched by the pad rule). The board clears all four with room —
> measured 2026-08-08: mount-pad annular 0.700, worst PTH-hole-to-copper 0.894 (MP4), worst
> pad-involved hole pair 0.530 (NPTH↔via), smallest NPTH 0.991 — so the rules are insurance
> against future edits, not corrections.
>
> **The single thing that cannot satisfy all three fabs** is the pair of 0.4 mm plating-bus stubs
> crossing the outline at x = 25.4. They are *required* at PCBWay to feed electrolytic hard gold
> and *prohibited* at both ENIG-only fabs — OSH Park by its 0.381 mm edge pullback, JLCPCB by its
> 0.2 mm one, and neither offers selective hard gold at all (JLCPCB finishes are HASL/ENIG/OSP),
> so the monogram table is ENIG there and the bus has no job regardless. **The OSH Park and JLCPCB
> uploads are the SAME artifact: the plain 1-up set with the two stubs deleted, and nothing else**
> — one deletion procedure covers both ENIG fabs, and everything else in the board is common to
> all three.
>
> Since 2026-07-28 that difference is a **build step, not an edit**: PCBWay gets the panel
> (`Generated/panel/`, see below), whose frame carries the bus the stubs were always drawn for;
> the ENIG fabs get the plain 1-up set from `Generated/gerbers/` with the two stubs deleted. All
> orders come out of the same committed board.
>
> Two JLC-specific soft notes, neither of which gates. **Silk text height:** six back-silk labels
> (`ON`, `DRH v4.0`, `SDA`, `SCL`, `STO`, `SRC`) are set at 0.8 mm against JLCPCB's recommended
> 1.0 mm minimum — they will print, but JLC's DFM will flag legibility; cosmetic, and the labels
> live under the shell anyway. **PTH drill tolerance:** JLC's finished-hole tolerance is
> +0.13/−0.08 mm, so a Ø2.20 mount hole can finish at 2.12 and the radial slack against the M2
> screw drops from 0.100 to 0.060 mm — the screws still fit, but a JLC batch has less of the slack
> the 2026-08-03 mount-shift story was measured against. (JLC's V-cut minimum of 0.6 mm sits
> exactly at the production thickness, but it is moot: JLC gets the 1-up, not the panel.)
>
> Variant differences are otherwise fab *order options*, not artwork: soldermask colour, substrate
> colour, board thickness, and whether the Ti back-shell is fitted.

#### The midnight variant, rendered

<table>
<tr>
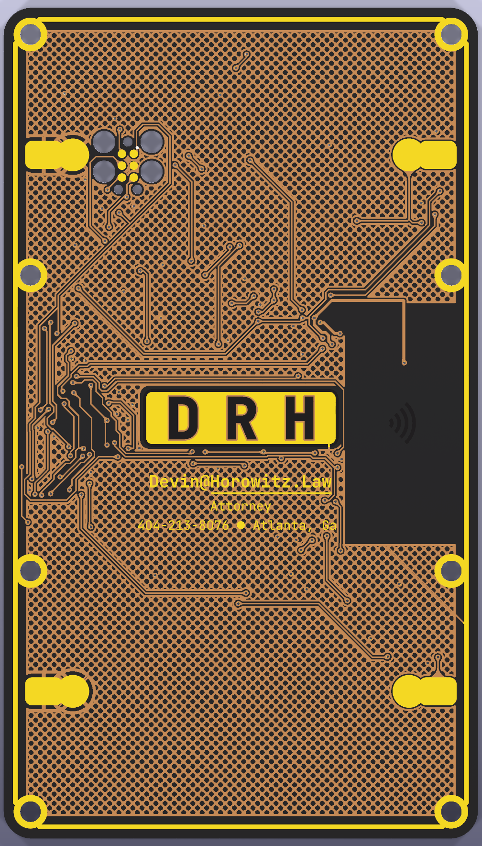
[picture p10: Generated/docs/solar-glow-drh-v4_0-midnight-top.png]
Midnight variant, front — clear mask over black substrate, copper crosshatch fully visible
<td width="50%"></td>
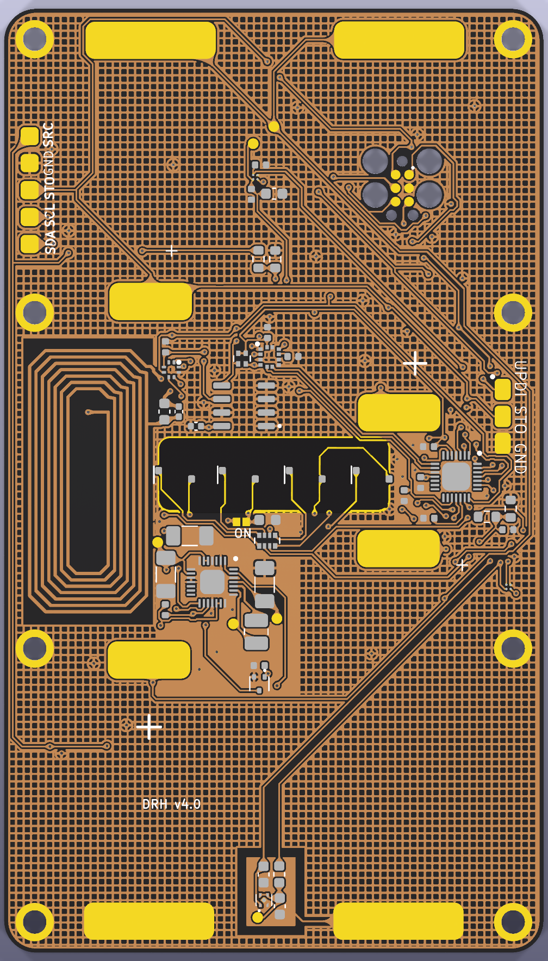
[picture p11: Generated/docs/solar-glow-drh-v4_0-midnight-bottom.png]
Midnight variant, back — clear mask over black substrate, NFC coil and routing visible
<td width="50%"></td>
</tr>
<tr>
<td align="center"><b>Front</b></td>
<td align="center"><b>Back</b></td>
</tr>
</table>

**OSH Park After Dark: black substrate, clear soldermask, ENIG, 1.6 mm, no components.** Not
panelised — OSH Park panelises for you, and the plating bus has no job there, so the render drops
the two stubs exactly as the upload does.

The important thing this render shows is that **midnight is not just production-in-a-different-colour.**
Under a clear mask you see *all* the copper, so the crosshatch stops being a sub-mask texture and
becomes the dominant graphic — a copper field with the black core showing through its gaps. And
because surface finish only lands on mask-opened copper, the hatch stays bare copper while the
monogram table, frame and ornaments come back gold. Production hides the hatch and shows the gold;
midnight shows both, and the contrast between them *is* the design.

### The PCBWay panel (`scripts/panelize.py` → `Generated/panel/`)

**Order the panel, not the bare board.** The plating stubs are only half a circuit on a 1-up
board — they end 0.4 mm outside the outline and connect to nothing, so an ENIG-only run would
leave them as dead copper and the face with no wear surface. The panel is the other half: a
frame the plating rack can clip, with a copper bus ring joined to both stubs across the break
tabs.

| | |
|---|---|
| Panel | **65.6 × 103.7 mm**, 1-up, card at (0, 0)–(50.8, 88.9) |
| Routed slot (moat) | **2.4 mm**, follows the card's rounded outline |
| Frame rail | **5.0 mm** all four sides |
| Break tabs | **2**, one per short edge, 5.0 mm wide, centred on **x = 25.4** |
| Mouse bites | **8** total: Ø0.5 mm NPTH, 4 per tab, on the card outline (y = 0 / 88.9) |
| Plating bus | 0.4 mm spur across each tab → 1.0 mm ring inset 2.5 mm from the panel edge, GND. **Ring on BOTH faces**; spur on whichever face the board's own stubs use |
| Bus mask | Ring is **mask-opened along its whole length, on both faces** — a plating rack needs bare copper to clip |
| Ring stitching | **6 × Ø0.6/0.3 vias** — 2 at the spur junctions, 4 at the ring corners |

The mask opening matters more than it looks: a bus ring buried under soldermask is decoration, not
a plating path, because the rack has nothing bare to grip. Exposing the whole ring does put ~319 mm²
of copper per face in reach of the gold bath — **~638 mm² now that the ring is double-sided, so
~12 mg of gold rather than ~6.** Still well under a dollar, on material that gets routed away, so
it stays priced in rather than engineered around. The special request above tells the fab the rail
is hardware and not artwork.

**The ring runs on both faces (2026-08-04), and the spur follows the board.** Two reasons. The
first is operational: with a single-sided ring the rack has to be clipped to the *right* face, and
a clip on the blank one plates nothing — a failure that shows up as a card with no gold on it,
after the bath. The second is what the double ring is *for*: it lets the **stubs move to B.Cu**, so
the 0.4 mm nub left at each short-edge midpoint after depanel lands on the back, under the titanium
shell, instead of on the card face. The two rings are one node only because of the six stitching
vias — the spur lands on **one** face, so without them a rack clipped to the other is connected to
nothing at all.

**The spur's layer is read from the board, never set here.** `stub_layer()` in
`scripts/panelize.py` finds the two net-GND copper `gr_line`s that cross the outline at x = 25.4
and emits the tab spur on *their* layer, failing loudly if there are not exactly two, if they
disagree on layer, or if their width is not `BUS_W_SPUR`. That is deliberate: the stubs live in
the board file and the spur is a constant in a script, they get edited months apart in different
tools, and a bus in two disconnected pieces is invisible until the gold does not take. It also
means there is no flag day — the panel is correct before *and* after the board-side move.

The tab sits at x = 25.4 because that is where the stubs already crossed the outline — the
board was drawn expecting this panel long before it existed. Each tab keeps a **1.0 mm
hole-free web** at its centre so the bus crosses without a mouse bite eating into it
(0.30 mm drill-to-copper either side); the remaining 4.0 mm of tab is perforated.

**Getting it:** CI rebuilds the panel on every `PCB/**` push and plots its fab set. As with the rest
of `Generated/`, the result is **committed only on `main`** — on a feature branch the panel build is
a gate, not a commit. The panel `.kicad_pcb` itself is gitignored everywhere (a ~9.7 MB regenerated
blob), so rebuild it locally if you want to look at it:

```sh
python3 -m pip install shapely
python3 scripts/panelize.py          # -> Generated/panel/solar-glow-drh-v4_0-panel.kicad_pcb
python3 scripts/panelize.py --check  # geometry report only, writes nothing
```

The panel is **derived, never hand-maintained** — it is the committed board plus a frame, and the
script asserts that (it re-reads Edge.Cuts and fails loudly if the outline stops being one closed
region). Change the board; the panel follows. Never edit the panel and expect it to survive.

**On the order form:** upload `Generated/panel/solar-glow-drh-v4_0-panel-fab_zip.zip` and set
**panel = "panel by customer"**. Quantity is counted in *panels*, so 5 cards = 5 panels. Everything else (2-layer,
0.6 mm, ENIG + the hard-gold special request above, matte black, white silk) is unchanged.

**Depanel:** snap the two tabs, then file the edge flat at x ≈ 25.4 on both short edges. The
filing is not optional and not a defect — a gold-plated bus nub is left behind by design, and
dressing it flush is the last step of the plating scheme. Expect to touch up the mask/edge there.
**The nub is on whichever face the stubs run on** — **B.Cu since 2026-08-05** (DRH moved both
stubs in KiCad), which puts it on the back, under the titanium shell, at both short-edge
midpoints. Check [19] holds the fab request's stated side to the board so the two cannot drift
apart; its every-run warning retired with the move.

**Why 1-up and not 2-up (costed 2026-08-04, for a 10-card / 2-assembled order).** Two cards
side by side — sharing a moat, long edges adjacent — would be **118.8 × 103.7 mm**: half the
pieces (5 instead of 10) and **9.5% less laminate** (616.0 vs 680.3 cm² for ten cards), and
5 panels lands exactly on PCBWay's 5-piece minimum. It still lost. **PCBWay quoted the 2-up
about $3 MORE**, which ends the fab argument, and assembly cannot rescue it: setup, stencil,
**25 feeder lines and 94 placements** (47 × 2) are identical whether the two assembled cards
arrive on one panel or two. Only per-panel handling could differ, and it would have to beat $3
*and* pay for the rework — the panel is built by *appending* a frame to the board's own
s-expressions, so a second card means cloning every coordinate-bearing item in a ~9.7 MB file
(footprints, tracks, zones **and their stored fills**, 605 mask-art polys) with fresh UUIDs and
an x-offset. Mechanical, but one missed nested `(xy …)` corrupts artwork silently instead of
failing. Revisit only if a future order is large enough for the per-card area saving to compound.
_(Stacking short-edge-to-short-edge is worse on both counts: 6.0% area, and it points each
card's bus tabs at the other card across the moat instead of at a rail.)_

**Deliberately not on this panel:** fiducials, tooling holes and copper thieving. The first two
want a wider rail than the bus leaves room for, and this board is hand-finished rather than
machine-placed (see the hand-assembly notes below), so none of them buy anything today. Say so if
a PCBWay DFM reviewer asks — their absence is a decision, not an oversight.

**Add to the order notes / gerber review:**
- "**Leave soldermask open over the central window per the mask layers — do not tent or
  flood.**" (The bare-FR4 + open-ENIG window is the whole optical trick.)
- "**Keep vias tented.**"
- **Selective hard gold (the reason the plating bus exists):** paste this verbatim into the
  special-request box —

  > *"Selective hard gold plating on top side, defined **by net**: gold **every top-side copper
  > surface exposed by an F.Mask opening that belongs to the GND net**, with one exception — the
  > four solar-cell N-side solder lands (PV1/PV2 pads N and Nt) stay with the base finish, because
  > they are soldered and thick electrolytic gold embrittles solder joints. **The `User_1` gerber
  > in this upload draws exactly this area — treat it as the plating drawing.** Concretely the gold
  > set is: the DRH monogram field and letter rims, the perimeter frame, the six edge ornament
  > shapes, the eight M2 mounting-hole annuli (four corners, four mid-edge), and the TC2030 GND pad.
  > **The small contactless-mark arcs right of the monogram are NOT in the gold set and need no
  > attention: there is no copper under them at all** (they sit inside the antenna keepout, so the
  > pour cannot enter — measured 2026-08-02, 4.26 mm² of opening, 0.00 mm² of copper). They are a
  > mask opening over bare laminate, deliberately; expect bare FR4 there, not a missing plate.
  > Where the crosshatched ground pour shows inside one
  > of those openings, plate it with them; that is intended, not a defect. All other exposed top-side
  > copper stays with the base finish: the eight solar-cell lands PV1/PV2 (four SRC + the four
  > excepted GND solder lands) and TC2030 pads 1/2/4/5/6 (not on GND, so they have no electrical
  > path to the plating bus and cannot be electrolytically plated; they are spring-contact
  > programming pads and the base finish is acceptable there). The crosshatched pour
  > itself is under solder mask across ~90% of its area and is not a plating surface — it is a
  > decorative texture meant to be read THROUGH the mask, so please do not open mask over it or add
  > extra mask thickness to 'even it out'. The two 0.4 mm traces crossing the board outline at
  > x=25.4 (top and bottom edges) are plating-bus connections and run on the **BOTTOM side (B.Cu)**;
  > they cross the break tabs onto the panel frame's bus ring, which is where the plating rack
  > should clip. Please retain them through plating and rout at depanel. **The frame's bus ring is
  > on BOTH faces, mask-opened on both, and stitched together with six vias — clip either face.**
  > The ring is plating hardware, NOT part of the gold set: it is mask-opened so you have bare
  > copper to contact, and it is routed away at depanel; no need to plate it. The gold set is GND-referenced by design (the eight M2 mounting-hole pads overlap the
  > frame at the corners and mid-edges); not floating copper, not a defect. All in-pad vias: resin-filled and
  > copper-capped (POFV, IPC-4761 Type VII)."*

  **Since 2026-08-02 the request also ships as artwork:** `scripts/mask_art.py` draws the net
  rule's result on **`User.1`**, and both fab sets plot it as its own gerber (`…-User_1.gbr`,
  1-up and panel). The drawing is generated from the board — every F.Mask graphic opening, the
  NFC arcs, and every GND pad with a front opening minus the excepted PV lands — so it re-derives
  on `--apply` and cannot drift when a pour outline or an opening moves.
  **Read it as the OPENING set, not the plated set.** It draws **394.2 mm² of opening**, of which
  **~296 mm² is copper** that will actually take gold; the remaining ~98 mm² is bare laminate
  inside those openings — overwhelmingly the monogram window, which is bare FR4 *on purpose*
  because that is the backlight, plus the 4.26 mm² contactless mark. That is not a discrepancy to
  reconcile: the net rule already says "plate the copper surface an opening exposes", so laminate
  inside an opening is simply nothing to plate. (Split measured 2026-08-02 against the refilled
  board; re-measure it if the routing or the pour outline moves.)
  **The enumeration above is now GATED** by consistency check [14], which re-derives it from the
  board: every opening in the drawing must have copper under it or be one of two reasoned
  exceptions (the mask-only contactless mark, and the D/R/H letter apertures, where bare FR4 *is*
  the backlight), and the stated M2-annulus count must match the pads. That gate exists because
  this paragraph was wrong twice in a week — *four* annuli when the board has eight, and the
  contactless arcs listed as gold when they have none — and a fab acts on this text. Editing the
  enumeration without the board agreeing now fails CI. Drift is not
  hypothetical: the enumeration above said "four" mounting annuli while the board carried eight
  (MP1–4, the mid-edge shell points, are GND annuli with front openings too — the net rule always
  covered them; the prose didn't). Consistency check [6] gates the drawing like the rest of the
  generator's output, and the generator refuses to draw an area that overlaps an excepted PV
  solder land, so the exception cannot silently erode either.

  A DFM reviewer will flag copper-to-edge = 0 at the two stubs; that is by design. (Net inventory
  re-verified against the committed board 2026-07-31, when the request moved from an enumerated
  area list to the **net rule** above: the front's F.Mask-opened pads are exactly PV1/PV2 ×8
  (4 SRC + the 4 GND solder lands the rule excepts) and TC2030 ×6 (1 GND, in the gold set; 2
  signal + 3 unconnected, unplateable — no bus path); beyond the SMD set, the eight M2
  mounting annuli are GND with front openings (in the set) and the TC2030 locating apertures
  are netless holes with no copper to plate (2026-08-02 re-verification, when the `User.1`
  drawing was born from the same inventory); every graphic opening exposes GND pour or
  bare laminate only, which `scripts/mask_art.py`'s guard enforces for its own art. (`TC1/b`,
  the 2026-08-01 B-side mirror, opens **B.Mask** only — it is outside the front gold set by
  construction and takes the board-wide base finish like every other back pad.) The gold set
  stays a single connected F.Cu group fed by the pour — the net rule *adds* the TC2030 GND pad
  (a spring-contact surface, which is what hard gold is for) relative to the old enumeration;
  same look, better wear, one sentence of spec. _(It was also read as adding the contactless-mark
  arcs. It does not: the net rule plates copper an opening exposes, and those arcs expose no
  copper — corrected 2026-08-02 when the question "does the gold NFC symbol attenuate the
  antenna?" was answered by measuring it. There is no gold there to attenuate anything.)_)
  Ordering plain
  ENIG without this request leaves the bus as dead copper and no wear surface on the face — do
  not ship without it.

  > **Superseded 2026-08-02 — the pour was pulled back.** `GND_A`'s outline is now the rectangle
  > (2.4, 2.4)–(48.4, 86.5), leaving a **0.8 mm dark reveal** between the frame's inner edge and the
  > mesh, so the frame reads as a clean unbroken line instead of a serrated one (front only; `GND_B`
  > is inside the shell and unchanged). That removes most of the overlap this note is about — front
  > fill 2046 → 1778 mm² — but the note stays, because the *reason* the request is a NET RULE rather
  > than a connectivity rule is unchanged, and because the overlap is smaller now, not gone. The
  > gold chain was re-verified after the pullback: the frame, the eight M2 annuli and the
  > plating-bus stub are still one connected group on F.Cu, which is what the electrolytic bath
  > needs.
  >
  > _(2026-08-04 — **"one connected group on F.Cu" was never the whole path, and it matters now.**
  > Measured: F.Cu GND is **5 islands**, not one. Both stubs land on the same island — the 1939 mm²
  > one holding the gold set and 4 M2 mounts — so the other four have **always** been fed through
  > vias, never by the stubs. That island carries **19 GND vias** into B.Cu. Which is why moving the
  > stubs to B.Cu costs the bath nothing: it swaps a direct F.Cu entry for 19 parallel via paths
  > into a mechanism the design already depended on. See the TODO item for the board-side move.)_
  >
  > **Why the wording changed (2026-07-27, the crosshatch upload).** The request used to say the
  > gold set was "**all connected copper on F.Cu**." The crosshatch rework enlarged the F.Cu pour
  > outline to 0.5 mm from the board edge, so the pour then overlapped the gold artwork by **157.3 mm²**
  > — 52% of the frame + ornament copper — where it used to graze it over 0.069 mm². Connectivity
  > therefore stopped being a usable way to name the gold area.
  >
  > **How big a problem that actually was: smaller than it first looked.** A fab can only plate
  > copper the mask leaves exposed, and the crosshatch is a *sub-mask* ornament — **89.6% of it
  > (1816.9 of 2028.1 mm²) sits under solder mask** and is not a plating surface at all. Only
  > **211.2 mm²** of hatch is exposed, and that is hatch falling inside the monogram / frame /
  > ornament mask windows, where plating it with them is the correct outcome anyway. So the old
  > wording was ambiguous rather than expensive. (An earlier draft of this note claimed it would have
  > gold-plated ~2,400 mm² of pour. That was wrong — it ignored the mask.) **The monogram field is
  > untouched** regardless: it sits inside the `optical_window` keepout, which the pour cannot enter,
  > so its overlap is exactly 0.00 mm².
  >
  > The new wording names the gold area by **F.Mask opening** instead, which is what physically
  > governs it: top-side mask openings total 562.2 mm² (473.0 graphics + 89.2 pad apertures), and
  > 97% of the 387.5 mm² artwork sits inside one. It also tells the fab the pour is decorative and
  > must stay masked — the texture only reads if the mask telegraphs the 35 µm copper step, so extra
  > mask thickness would flatten the effect the hatch exists for. **Durable fix, if you want one:**
  > draw the gold area on a dedicated user layer (`User.1`, empty today) and plot it as its own
  > gerber, so the region is artwork rather than prose. Not done here.
- "**The LA/LB track crossing at (41.0, 38.0) is the NFC coil junction — intentional.**"
- **Bench pad strip (`TP1` + `JP1`, back east edge, x 48.4):** five bare 1.7 mm SMD probe pads
  (SRC / GND / STO / SCL / SDA at 2.54 pitch) - no component; they are in the mark-as-DNP list
  above. Pinout and the bench-power ritual live in `solar-glow-drh-v2-hardware.md` (note: that frozen doc predates the v3->v4 VS->STO change, so JP1.2 is now the STO tank node, not the VS rail).
- **Via-in-pad -- several vias land inside pads** on this board: the soldered pads (`TC1.1`, `U1.EP`,
  `U5.1`, `SW2.1`, `J1.2`, `PV1.N`, `PV2.N`, `PV2.Nt`)  [D1.K and R13.2 removed - D1 and R13 are not on the v4 board; re-verify the full via-in-pad set against the v4 layout, since v4 added U7/U8/U9/L2/FB1] plus 2 in the bench-strip
  probe pads (`JP1.3`, `JP1.4` — bare pads, hand-solder optional). The clean answer is
  the same as always: **order resin-fill + cap (via-in-pad process) board-wide.** The one
  that *must* be flat and hole-free is **TC1.1** (a Tag-Connect pogo contact); the rest
  are large or hand-soldered pads where a plugged via is merely tidy.

> **Resolved in the R14 patch:** the previously undocumented Ø 0.89 mm NPTH at (37.9, 75.4)
> (under SC4's body) was **deleted from the board** — nothing in the repo claimed it. If it had a
> purpose, it's one git revert away. *(Lineage re-checked 2026-07-02: absent from the v0
> prototype; entered at v2.1 inside an anonymous `NPTH_mech` footprint; never appeared in the fab
> hole table; the enclosure generator places nothing there. Orphan confirmed — deletion stands.)*

**No stencil to order (2026-08-01):** PCBWay's assembly service makes and owns its own paste
tooling from the B.Paste plot — window-paning the U1/U8 exposed pads per their process is
their standard DFM, with the board's 1:1 apertures as the input. A separate frameless stencil
is only worth adding to the order if you ever plan to re-run reflow yourself (rework or a
spare-board build); the hand-soldered parts (supercaps, cells) never need one.

> **What the stencil deliberately does NOT open (2026-07-26).** Paste has been removed from the
> pads of every part that is not reflowed, so the stencil only opens where paste is wanted:
>
> | | pads | why |
> |---|---|---|
> | **PV1, PV2** (solar cells) | 8 | hand-soldered, consigned; **4 pads each** — a Ø3.5 mm terminal plus a 4 × 3 mm tab 3.1 mm outboard |
> | **SC1–SC4** (supercaps) | 8 | hand-soldered to the under-body P/N pads |
> | 11 DNP parts (incl. **TC1/b**, the B-side mirror, 2026-08-01) + **TC1** | 35 | not placed / pogo contacts must stay bare |
>
> The PV and SC pads alone are **≈ 366 mm² of aperture** — the largest on the board by a wide
> margin, equivalent to about 1,200 0402 pads. Reflowing that much paste under parts meant to be
> hand-soldered is not a small waste: it is enough solder volume to float the part.
> **Copper and mask are untouched** — only the paste layer was removed, so every pad solders by
> hand exactly as before.

> **HAND-SOLDER CAUTION — what a nudged supercap can break.** SC1–SC4 are 17 × 39 mm and
> 17 × 28.5 mm bodies placed by hand, and several machine-placed parts sit close enough to be
> sheared if a cap is slid or rotated into them. Measured from the board (travel to contact,
> nominal position):
>
> | cap | direction | reaches | at |
> |---|---|---|---|
> | **SC4** | −X | **L2** — the harvester inductor | **0.50 mm** |
> | **SC3** | −Y | **R15** — STO sense divider, upper leg | **0.57 mm** |
> | **SC3** | −X | **C24** — STO sense divider cap | **1.01 mm** |
> | SC1 | +X / +Y | C11 / C1 | 0.70 / 0.92 mm |
> | SC2 | −X / +Y | C6 / C8 | 0.65 / 1.53 mm |
>
> Rotation about the cap centre is the other failure mode, and it is tighter than it looks:
> **SC4 contacts L2 at 2.02°**, **SC3 contacts C24 at 3.00°**, **SC1 contacts C11 at 3.13°**.
> Only SC2 has real room — 6.71° to R5. For scale, 1° of tweezer rotation swings the corner
> of a 39 mm cap by 0.34 mm, so these are angles a steady hand can produce.
>
> **The 13 DNP footprints are not stops.** C30, J1, JP1, SW2, TC1, TC1/b1 and TP1–TP7 are
> bare pads on a standard build, so nothing there resists a cap. J1 in particular sits
> 0.49 mm off SC1's −X edge and reads like a hard stop on the plot; it is not one unless
> you have deliberately loaded it (see the debug-header note below). SC1's −X is open.
>
> **C24 and R15 are the two that matter most.** They are the STO sense divider — the circuit
> every rail decision reads (`VS_GLOW_FLOOR_MV`, the ballast guard, dormancy). Shearing or
> cold-jointing either corrupts the voltage the firmware thinks it has, silently, and C24 is
> also the thinnest supply line in the BOM. Seat the caps deliberately rather than sliding them
> into place, and inspect L2, C24 and R15 after fitting SC3 and SC4.
>
> These clearances are **not** design datums — a 0402 will shear before it indexes a supercap.
> The brace's own allowance for this slop is separate and lives in `fit_rules` as `CLR_DATUM` /
> `CLR_FREE` — directional since 2026-08-23, because the reflow shim indexes two edges of each
> cap. Note the brace therefore only fits a cap the shim seated; see `enclosure/shim/README.md`.
>
> Every number in this block is **measured from the board and gated** — `scripts/cap_clearance.py`
> owns both the measurement and the ledger, and consistency check [21] fails if this table, the
> ledger and the board stop agreeing. Do not hand-edit the figures; re-run the script.

---

## Step 4 — Order the parts

**BOM state.** There is **no spreadsheet master.** Both `*-BOM.xlsx` files were **culled
2026-08-02** and live in git history; every line is derived from the schematic plus the board's own
`exclude_from_bom`/`dnp` flags by `../scripts/bom_split.py`, and written into
`../Generated/fabdocs/` on each CI run. `../BOM/README.md` shows current stock/lifecycle/price per
line, regenerated by `python3 BOM/check_stock.py`. _(This paragraph opened "The masters are now
…xlsx" until 2026-08-04 — pre-cull text that contradicted the boxed note twenty lines below it, in
the one step where somebody actually buys parts.)_ The design was reworked for the v4.0 managed-solar redesign - the passive diode/shunt/comparator parts (U2, U4, Q1, D1, D9–D11, R7–R9) are removed and the AEM10300 harvest chain (U7, U8, U9, L2, FB1, C22–C28, R15–R17) is added, on top of the earlier fixes:
**U6 (TPS22917DBVT since the 2026-07-23 dark-current swap) and R14 (1 M `NFC_EN` pulldown) added**, the stale **JP1/JP2 rows dropped** (the `JP1` designator is reused for the v3.0 bench pad strip — bare pads, not a BOM part)
(those headers left the board in v3.0), and **most passives converted to 0402** to match the board's placed lands — the v2.2 file still
listed 0805 MPNs for most R/C. _(Updated 2026-07-25: the 2026-07-23 longevity/precision passes moved
several off 0402 — **0603**: C4, C13, C22, C23, R5, R6, R15, R16, **FB1**; **0805**: C9. (This
size census has moved twice since it was written: 2026-07-30 took C25 0603→0805 and C9 0402→0805,
and **2026-08-06 took C25, C26 and C27 to the low-profile 1206** — Murata GRM319, 0.95 mm max —
for the enclosure height wall. The table below is the current truth.)
(FB1's 0402-land lag is **resolved** — BOM, schematic and board all carry the 0603 land now,
verified against the committed board 2026-08-01; the TODO item this note used to point at is gone.)
SJ1 is **gone
outright** — DNP'd 2026-07-23 with the AVR-EA swap, then symbol, land and strap deleted from the
schematic and board on 2026-07-30 (PR #114 sch cull + the board sync); the BOM master keeps its
row as lineage. New parts since: **Q2** (SOT-23) + **R18** (0402). The table below is the
current truth.)_ Converted and added
lines had their prices blanked at the time; **that is no longer true — every ordered line is now
live-priced** (full DigiKey/Mouser sourcing pass, 2026-07-23, subtotal ≈ $140). The `v2 2` and older
BOM files remain in git history as lineage.

Summary of the **orderable** lines:

> **Derived snapshot. DO NOT ORDER FROM IT.** As of 2026-08-02 there is no hand-authored BOM at
> all: both `*-BOM.xlsx` masters were culled (they are in git history) and every line is derived
> from the schematic plus the board's own flags. Order from the generated documents —
> `../Generated/fabdocs/solar-glow-drh-v4_0-pcbway-assembly.csv` for the machine-placed set and
> `…-handbuy-*.csv` / `…-handbuy.md` for what you buy yourself — or from `../BOM/README.md` for
> live availability. This copy had drifted badly (it still listed the pre-swap
> `AVR64DD28-I/STX`, `TPS22918DBVR`, the SOIC-8 FRAM and the pre-longevity-pass passives), so
> treat any disagreement as this table being wrong.

| Ref(s) | Qty | Value | Package | MPN |
|---|---:|---|---|---|
| U1 | 1 | AVR64EA28, 64 KB, 20 MHz | VQFN-28 (4×4×1.0 mm, w/ EP) | `AVR64EA28-E/STX` |
| PV1, PV2 | 2 | Voc 4.15 V, 184 mW, mono, 1.2 mm thick | 42×23×1.2 mm, custom land | `SM141K06TF` |
| SC1, SC3 | 2 | 1.8 F, 2.75 V (SS17) | SS17 (diagonal under-body P/N pads, 39 mm) | `3-153-440` |
| SC2, SC4 | 2 | 1.0 F, 2.75 V (WS17) | WS17 (diagonal under-body P/N pads, 28.5 mm) | `3-153-438` |
| D2–D5 | 4 | Amber 617 nm, Vf≈2.25 V | SMD, 3.4x1.9 mm | `LA P47F-V2BB-24-3B5A-30-R18-Z` |
| RN1 | 1 | 4×150 Ω isolated array, ±5% (J is the buyable ceiling; matching rides the shared substrate) | 0804 convex (`R_Array_Convex_4x0402`, inner pads slimmed to 0.294 — see the re-link warning below) | `EXB-28V151JX` |
| R5, R6 | 2 | 2 MΩ, ±0.1%, 25 ppm **guaranteed at 2M** (the 2026-08-08 bump: halves the divider's permanent SRC bleed; Yageo's 2M variant is 50 ppm and stockless, so the MPN moved to the MCT family R15 already uses) | 0603 (R_0603_1608Metric) | `MCT0603MD2004BP500` |
| C5 | 1 | 100 nF, X7R, 50 V | 0402 | `GRT155R71H104KE01D` |
| U3 | 1 | I²C 0x1D, ±2–8 g | LGA-12 CC-12-4 (2.2×2.3×0.87 mm) | `ADXL367BCCZ-RL7` |
| RN2 | 1 | 2×4.7 kΩ isolated array, ±5% (I²C pull-ups need no matching — placement consolidation, 2026-08-08) | 0404 convex (`R_Array_Convex_2x0402`, stock land — see the re-link warning below) | `EXB-24V472JX` |
| C1 | 1 | 100 nF, X7R, 50 V | 0402 | `GRT155R71H104KE01D` |
| C3 | 1 | 100 nF, X7R, 50 V | 0402 | `GRT155R71H104KE01D` |
| C4 | 1 | 10 µF, X5R, 16 V | 0603 | `GRT188R61C106KE13D` |
| C6 | 1 | 100 nF, X7R, 50 V | 0402 | `GRT155R71H104KE01D` |
| C11 | 1 | 0.22 µF (220 nF), X7R, 16 V | 0402 | `GRT155R71C224KE01D` |
| C12 | 1 | 100 nF, X7R, 50 V | 0402 | `GRT155R71H104KE01D` |
| SW2 | 1 | 2-pad bridge (was 3-pad until TINY left, 2026-08-05) | solder-bridge | **(none — PCB bridge)** |
| TC1 | 1 | TC2030-MCP-FP | TC2030 legged land | **(no part — pogo interface)** |
| J1 | 1 | 1×3, 0.1″ | 0.1″ THT pads | **(unpopulated / 0.1″ header)** |
| JP1 | 1 | 4× bare SMD pads | 1.7 mm sq, 2.54 mm pitch, B side | **(bare pads — no component)** |
| TP1 | 1 | 1× bare SMD pad | 1.7 mm sq, B side | **(bare pad — no component)** |
| MH1–MH4 | 4 | M2 | 2.2 mm plated | **(no part — drill)** |
| U5 | 1 | NTAG I²C plus, 2 KB, I²C 0x55 | XQFN8 (SOT902-3, 1.6×1.6×0.5 mm) | `NT3H2211W0FHKH` |
| C8 | 1 | 100 nF, X7R, 50 V | 0402 | `GRT155R71H104KE01D` |
| C9 | 1 | 47 pF, C0G/NP0, ±2 %, 250 V, High-Q (S-series) | 0603 (`Capacitor_SMD:C_0603_1608Metric`, 0.89 max) — **was 0805 High-Q `QSCT251Q470G1GV001E` (1.17) until the 2026-08-06 low-profile respin; same purpose-built family one case down (no flat RF 1206 exists); board sync pending** | `QSCP251Q470G1GV001T` |
| C13 | 1 | 10 µF, X5R, 16 V | 0603 | `GRT188R61C106KE13D` |
| L1 | 1 | 2.76 µH design value | PCB copper — no package | **(no part — PCB feature)** |
| U6 | 1 | Ultra-low-leakage load switch (ISD 10 nA typ, IQ 0.5 µA, QOD, RCB) | DSBGA-4 (`solarglow:TPS22916_YFP0004`, 0.4 mm pitch, 0.5 max) — **was SC-70-6 `TPS22919DCKR` until the 2026-08-06 ultrathin swap; on the board since the same day's rework round** | `TPS22916CYFPR` |
| U10 | 1 | Ultra-low-leakage load switch — **the STO sense-divider gate** (2026-08-09). Second instance of U6's part. Feeds R15 from STO only while a conversion is in flight, so the 3 MΩ divider stops drawing **1.55 µA from the tank** around the clock. **High-side by necessity**: gating the low leg would let C24 float `STO_SNS` to STO, above VDD, forward-biasing PD1's ESD clamp — still ~0.4 µA *and* injecting into an ADC pin. Needs **no external pulldown** (cf. R14 on U6): the TPS22916 has a smart 750 kΩ ON pulldown that auto-disconnects once driven high. | DSBGA-4 (`solarglow:TPS22916_YFP0004`, 0.4 mm pitch, 0.5 max) | `TPS22916CYFPR` |
| R14 | 1 | 1 MΩ, ±1% | 0402 | `AC0402FR-071ML` |
| U8 | 1 | AEM10300 | QFN-28 (4x4 mm, EP land 2.30) | `10AEM10300C0000` |
| U9 | 1 | TPS7A0233, 3.3 V, ~25 nA Iq | X2SON-4 (DQN, 1×1 mm, 0.4 max) — was SOT-23-5 (DBV) until the 2026-08-05 swap | `TPS7A0233PDQNR` |
| U7 | 1 | MB85RC512TY | DFN-8 LCC-8P-M05 (5.0×6.0×0.90 mm MAX, 1.27 mm pitch) | `MB85RC512TYPN-GS-AWEWE1` |
| L2 | 1 | 10 uH | 1008/2520 (L_1008_2520Metric), 2.5x2.0 mm | `DFE252010F-100M=P2` |
| FB1 | 1 | 0603 bead | 0603 (`L_0603_1608Metric` — the true 0603 land since DRH's 2026-08-08 island round; the 0402-land debt is paid) | `BLM18PG221SN1D` |
| C22 | 1 | 1 uF, 25 V, 0603, X7R | 0603 (C_0603_1608Metric) | `GRT188R71E105KE13D` |
| C23 | 1 | 2.2 µF, 25 V, 0603, X7R | 0603 (C_0603_1608Metric) | `GRM188Z71E225ME43D` |
| C24 | 1 | **10 nF**, 0402, X7R — ADC reservoir on `STO_SNS`, shrunk from 100 nF on 2026-08-09 so the **gated** divider settles in ~33 ms instead of ~335 ms (still ~2000× the ADC sample cap). **±10%, and X7R adds ±15% over −55…+125 °C** — the worst-case-high 12.65 nF stretches τ from 6.68 to 8.45 ms, which is why `STO_SNS_SETTLE_MS` is 53 and not the nominal-cap 33; `firmware/board.h` owns that arithmetic. **Second source `GRT155R71C103KE01J`** — see the sourcing note below | 0402 | `GRT155R71H103KE01D` |
| C25 | 1 | 22 uF, 16 V, 1206 low-profile (0.95 max), X5R | 1206 (`solarglow:C_1206_3216Metric_HS_LP085`) | `GRM319R61C226KE15D` |
| C26, C27 | 2 | 10 µF, 25 V, 1206 low-profile (0.95 max), X5R | 1206 (`solarglow:C_1206_3216Metric_HS_LP085`) | `GRM319R61E106KA12D` |
| C28 | 1 | 100 nF, 0402, X7R | 0402 | `GRT155R71H104KE01D` |
| R15 | 1 | 2 M, 0603, ±0.1%, 25 ppm | 0603 (R_0603_1608Metric) | `MCT0603MD2004BP500` |
| R16 | 1 | 1 M, 0603, ±0.1%, 25 ppm — **same Vishay MC AT film system as R15** (2026-08-09; was Yageo `RT0603BRD071ML`) | 0603 (R_0603_1608Metric) | `MCT0603MD1004BP500` |
| R17, R18 | 2 | 1 M, 0402, ±1% | 0402 | `AC0402FR-071ML` |
| Q2 | 1 | N-ch MOSFET, 20 V, logic-level (Vth 1.0 max) | SOT-523 (0.90 max) — **was SOT-23 `BSS138LT1G` until the 2026-08-06 low-profile respin; board sync pending** | `DMG1012T-7` |

**The 100 nF census (2026-08-08, DRH's ask — "I think we have at least one too many"):** nine
decouplers after the round, and each one now has a named pin. Per-pin: **C1 → U1.24 VS**
(2.62 mm) and **C29 → U1.18 VS** (1.46 mm) — the AVR has TWO VS pins, so these are NOT
redundant; **C3 → U1.10 VDDIO2** (2.86); **C12 → U3.12 VS** (1.39); **C28 → U7.8 VS** (2.43);
**C6 → U6.A2 VS** (2.01); **C8 → U5.6 VNFC**. C5 (VSENSE) and C24 (STO_SNS) share the MPN but
are divider FILTERS, not decoupling — distance rules don't apply to them. The one-too-many was
**C7**: both C6 and C7 sat nearest the same U6.A2 pin — a leftover from U6's SC-70 era that
survived two package swaps — deleted 2026-08-08. C8 flagged the same day at 5.25 mm from its
pin, parked by Claude at (33.1, 34.5) pads-unrouted, then **finished by DRH at (35.6, 31.86)**
— north of U5, 1.4 mm pad-to-pin, fully routed. The census is closed: every decoupler within
2.9 mm of its pin except C3 (VDDIO2, 3.5 mm — a µA rail, accepted).

**The AVR sits on a solid island too (`GND_B_AVR_ISLAND`, 2026-08-09).** Third and last of the
solid B-side patches, and unlike the other two it is *not* moated — it is a plain solid pour at
priority 1 over the hatch, net GND, outline **x 5.2–14.0, y 39.8–49.0 with the southwest corner
notched back to y 46.9 below x 8.0**. It covers U1 and all four of its decouplers (C1, C29 = VS;
C3 = VDDIO2; C5 = VSENSE), and **all 7 of their GND pads land on island copper** — U1's two GND
pins, U1's exposed pad, and the four cap returns — so the MCU's EP and every decoupling return
share one contiguous plane instead of a 49 % mesh.

Measured, `--refill-zones`, custom `.kicad_dru` loaded on both sides: inside that 75.08 mm²
outline the island converts **21.64 mm² of `GND_B` hatch into 30.27 mm² of solid**, a net
**+8.63 mm²** and ~**1.40×** the ground copper — with `GND_B_DCDC_SOLID` and `GND_B_LDO_ISLAND`
reading **+0.00** as the control that the measurement is sound. (An earlier pass of this number
was wrong by 10×: the scratch copy had the `.kicad_pcb` and `.kicad_pro` but **not** the
`.kicad_dru`, so the "before" board filled against default clearances. If you re-measure this,
copy all three files or you will compare two different rule sets.)

**Why here and nowhere else.** The area is MCU fanout — 114 B.Cu segments across 20 nets — so the
island fills **40.3 %** of its outline, the sparsest of the three patches (DC-DC 55.5 %, LDO
62.9 %). The gain is contiguity, not copper mass. _(These three percentages were first published
as 27.9 / 46.8 / 37.2 — measured, on 2026-08-09, with the very `.kicad_dru` omission described in
the paragraph above, in the same commit that documented the trap. Looser default clearances make
a solid pour fill **less**, not more, because it must back further off every trace. Corrected the
same day, from a run inside the repo directory where the rules load. If you quote a fill
percentage, say which rule set produced it.)_ The southwest notch is deliberate: it keeps the
island off **R15 (2 MΩ) / R16 (1 MΩ) / C24**, the STO sense divider. Wrapping a megohm node in
extra ground buys nothing and adds adjacent-edge surface-leakage path on a board whose dark
budget is single-digit nA. The other six ICs were considered and rejected — see the hatch note
below.

**Committed outline-only — and that was two-thirds safe, not safe.** The zone carries no
`filled_polygon`. KiBot's `check_zone_fills` preflight fills before DRC *and* before plotting and
then **restores** the board, so gerbers and DRC both see real copper and the fab output is right.
The imagery was not: `scripts/render.py` shells out to `kicad-cli pcb render`, which has **no
refill option** and draws the fills as *stored*, so the first regen after the island landed
produced correct gerbers, a correct DRC report, and **renders of the previous board** — max pixel
delta in the island window 12/255, indistinguishable from two control regions that had not
changed. Nothing failed. Check [9] cannot see this: it asserts an image came from a generator CI
runs, never that the generator saw current copper.

Fixed at the generator, 2026-08-09: `render.py` now refills zones on the temp copy it already
makes (`refill_zones()`), so imagery is a function of the routing rather than of whether someone
remembered to save a fill. Proven with the renderer itself — same file, same command, before and
after a refill: 3.5 % of pixels change in the island window while a control region is
**bit-identical** (max delta 0, which also establishes that `kicad-cli pcb render` is
deterministic and the earlier whole-board churn was CI-to-CI environment noise). The `.kicad_dru`
is copied beside that temp board before the refill, for the reason in the measurement note above.
The file's own fills still refresh on the next GUI save; nothing downstream depends on it now.

_(The same pass found `strip_plating_stubs()` in that file hardcoding `(layer "F.Cu")` while the
stubs had moved to B.Cu — matching nothing, removing nothing, and logging "removed 0 plating
stubs" while the OSH Park midnight render kept a bus that variant must not show. It now reads the
layer through `panelize.stub_layer()`, the same reader check [19] and the panel's tab spur use, so
a future stub move cannot leave one consumer behind. Reads "removed 2" now.)_

**Why the B-side pour is HATCHED — reconstructed 2026-08-09, intent never recorded.** Read this
as reasoning with its evidence, not as the original decision; if the real reason differs, correct
it *here*. Both pours are hatch 0.2 mm line / 0.5 mm gap = 0.7 mm pitch, **49 % copper**, `GND_A`
at 45° and `GND_B` at 0°. For `GND_A` the reason is written down elsewhere in this file and it is
cosmetic: the texture only reads because the mask telegraphs the 35 µm copper step. **That reason
cannot apply to `GND_B`** — the back of the card lives inside the titanium shell and is never
seen — so the back hatch is a functional choice, and nothing in `PCB/README.md`,
`solar-glow-drh-design-notes.md` or `scripts/nfc_coil.py` says what it is.

The mechanism that fits the evidence is the coil. The spiral is on B.Cu, the reader's field
crosses the whole card, and a continuous plane in that field carries circulating eddy currents
that load the antenna; breaking the plane into 0.7 mm cells cuts the area enclosed per loop and
so the induced loss. Meshing or clearing ground near an NFC antenna is standard practice, and the
board already spends real estate on the stronger form of it — `NFC_COIL_POUR_KEEPOUT` (B.Cu,
12.2 × 27.0 mm) and `NFC_COIL_KEEPOUT` (F.Cu) hold *all* pour off the coil, on both faces. The
hatch reads as the same intent applied to the rest of the card. The 45°/0° offset between layers
also stops the two meshes from registering into a more continuous composite, though that may
equally be aesthetic on the front.

**This is a hypothesis with a falsifiable test, and it has not been run.** Nothing here is a
measured Q or read-range figure, and `nfc_coil.py --check` measures geometry and inductance, not
plane loss. The bench settles it: read range and tank Q with the board as built versus a solid
B-side pour. Until then, treat "the back hatch is for the coil" as the best available
explanation, and note that the three solid islands are each small, local, and — except the AVR
one at 28 mm — kept well clear of the coil keepout, which is the conservative reading either way.

**The STO_LDO island is MOATED (2026-08-08, DRH's build + Claude's plumbing).** The LDO block —
FB1, C22, U9, C23, TP7 — lives at the foot of the SC3/SC4 bay (x 23.4–28, y 79.9–86.4) on its
own B-side ground patch, the zone **`GND_B_LDO_ISLAND`**, separated from the main `GND_B` pour
by four pour-keepout rule areas (**`MOAT_N/S/E/W`**, 0.85 mm band: pours blocked, tracks
allowed, vias blocked). The island touches system ground at **exactly one point**: the drawn
GND tie from **SC3.N — the supercap bank's own ground foot at (14.12, 85.95)** — landing on
C22.2. Why: the AEM's ≥10 MHz buck-boost hash rides raw STO, FB1 blocks it on the hot side at
the moat boundary, and the isolated patch keeps the same hash from re-entering around the bead
through shared ground copper — the LDO's reference wiggles with nothing, and VS (which the
AVR's ADC measures against) stays clean above where the TPS7A02's PSRR has rolled off. The
crossings are exactly two: STO in through FB1, VS out beside the tie so trace and return run
together. **The audit that must stay true** (run it after any rework here): delete the tie
trace, refill, and the island must fall OFF the net — 2026-08-08 baseline: with the tie cut,
`GND_B_LDO_ISLAND` and all four island ground pads go unconnected, proving no pour leaks
across the ring. If they ever stay connected with the tie cut, something bridged the moat.
Do NOT add a second tie (a bridge turns the island into a through-route for LED-pulse return
current), and do NOT drop GND stitching vias inside the ring. Cost/benefit as ledgered in
`fit_rules`: the max brace paid 58 mm² of field (coverage floor re-ledgered 0.33 → 0.32); the
lite brace — the variant the consolidation campaign optimizes — GAINED, 26.5% → 27.2%.

**No ordered part — these are board features, not BOM line items:**
- **SW2** (LED OFF/ON) is a **solder bridge** on the PCB. _(SB1–SB4, the per-LED force-on
  bridges, and the TINY dim position with its R12 ballast were deleted 2026-08-05.)_
- **The NFC antenna is etched copper** — no wound coil to buy, and it stays **under soldermask**.
  Opening the mask over it was tried on 2026-07-29 and reverted the same day: exposed copper gets
  ENIG, and nickel in an RF conductor costs Q (~7× copper's resistivity, ferromagnetic, and at
  13.56 MHz its skin depth is thinner than the plated layer, so the surface current runs in the
  nickel). It also bought nothing to look at — the shell is back-only, so the whole rear of the
  board is inside titanium. Soldermask is non-magnetic, so removing it never helped the ferrite
  either; that shielding scales with µ′ × ferrite thickness.
- **A contactless mark sits on the show face**, over the antenna at x[41.3,44.1] y[42.2,46.7] —
  generated by `scripts/mask_art.py` under its `(glyph − live copper)` rule, so it can only ever
  lay GND or bare laminate bare. It is the ONLY thing that generator writes now — the left-field
  cartouche was switched off on 2026-07-29 (see that file's `CARTOUCHE`). It falls inside the coil keepout
  where there is no front pour, so it reads as **bare laminate like the monogram window**, not
  gold. Generic waves, not the NFC Forum N-Mark, which is licensed.
- **TC1** is the **TC2030 footprint** — no soldered part; it mates with a TC2030-MCP pogo
  cable. **Do not load.** Since 2026-08-01 the land is **double-sided**: `TC1/b` mirrors the
  same nets onto `B.Cu` at the same XY, so the plug works from either side of a board that
  does not yet carry SC1 (the back land sits under the supercap's can). **Since 2026-08-06
  all six pads are live** — the three spares became a debug face: **4 = `BTN`** (PA5, the
  documented future-button net — active-low wake; it sits beside **3 = `GND`**, so shorting
  the two middle pads is the manual wake gesture), **5 = `SCL`**, **6 = `SDA`** (same pad →
  same net on both sides, the mirror rule). One cable now programs (UPDI), powers (STO),
  talks I²C, and wakes the card. Two cautions: an external I²C master must be **open-drain
  against `VS`** (RN2 pulls there — never push-pull from 3.3/5 V) and should hold the AVR
  in UPDI reset while it owns the bus; `BTN` has **no external pull-up by design** — the
  line floats until firmware enables PA5's internal pull-up with the pin-change interrupt.
- **J1** is an **optional** 0.1″ UPDI header — TC1 is the primary programming path.
- **MH1–MH4** are plated drills — supply your own **M2 screws** if enclosing.

**Flags to clear before you buy:**
- **R1–R4 value (150 Ω) is `SIZED`, not locked.** It sets per-LED peak current and is
  **bench-pending** — the energy-budget test may re-tune it. Buy a small 0402 range
  (e.g. 100 / 150 / 220 / 330 Ω) so you can swap after the measurement.
  *(Corrected 2026-07-26 PCB audit: this used to read "~9 mA on the clamped rail", a stale
  v3 figure — v3 fed the LED anodes from a rail the TLV3011B held near 3.5 V, giving
  (3.5−2.25)/150 ≈ 8.3 mA. v4 deleted that clamp: SW2 now feeds ANODE straight from STO, so
  the peak is (STO−Vf)/150 ≈ **14–18 mA** near the 4.65 V VOVCH ceiling — the LA P47F's Vf
  is itself unbinned across the 3B–5A groups, 1.95–2.55 V at 30 mA. The firmware
  (board.h/led.h) already assumes the v4 number; this line did not.)*
- **C9 is placed, at 47 pF** (changed 2026-07-30 — it was DNP pending a bench trim). The value
  is derived rather than measured: coil L = 0.958 µH by Greenhouse on the board's own rails,
  ferrite-loaded +10–36 %, NT3H2211 Ci = 50 pF, antenna Cc = 6 pF, targeting AN11276 §4.2.1's
  **14.5 MHz** single-tag nominal rather than 13.56. Full derivation in
  `PCB-side-notes-brace-direction.md` §5. **Measure enclosed, not bare** — bare reads ~16.7 MHz
  and the ferrite is what brings it down.
- **SC1–SC4 are the dominant cost** (well over half the BOM). Confirm live pricing.

---

## Step 5 — Assembly (as ordered: PCBWay turnkey)

Ordered as **single-sided turnkey assembly**: PCBWay sources the parts and machine-places
them on the **back**; the front stays naked until you fit the cells. You finish two part
types by hand afterward.

**The split**
- **The board carries ONE footprint with an EMPTY reference, and that is correct.** `solarglow:NPTH_mech` sits at (0.00, 0.00) on F.Cu with 7 pads: it is the mechanical NPTH carrier, not a part. It is flagged **both** `exclude_from_bom` and `exclude_from_pos`, which is why check [15] (nothing reaches the pick-and-place without a BOM line) and check [2] pass with it present — the two flags are what keep an un-buyable, un-placeable feature out of both fab documents. Written down 2026-08-18 because a blank refdes reads as a defect on sight and had already cost one investigation; if you are looking at it again, the flags above are the answer.

- **PCBWay machine-places** (reflow, bottom) — **41 parts** (46 until 2026-08-08: R1–R4 → RN1
  landed with DRH's ballast-array copper, then R10/R11 → RN2 and the C7 deletion in the same
  consolidation round — 7 parts out, 2 arrays in)
  (smd, not DNP, not bare-land): U1, U3, U5–U9, Q2, D2–D5, RN1, RN2, R5, R6, R14–R18, L2, FB1,
  C1, C3–C6, C8, C9, C11–C13, C22–C29. (The old list said "recompute from the v4 board" — done: it gained
  **C9**, placed 2026-07-30, and **C29**, the 100 nF at (11.575, 44.625) from the 2026-08-01 board
  sync. The v3 clamp/comparator parts - U2, U4, Q1, D1, D9–D11, R7–R9, C2, C10 - remain gone.)
  *(Corrected 2026-07-26: **SJ1 removed** from this list — it was then DNP/not-ordered and never
  placed. Since 2026-07-30 the question is moot: SJ1's symbol, land and strap were deleted from the
  schematic and board outright (PR #114 sch cull + the board sync). **Q2 and
  R18 added** — the charge-disable buffer from the cold-start-deadlock fix. **U7 is correctly in this
  list**: it carried a stray DNP attribute in the .kicad_pcb, now cleared so the board agrees with the
  schematic. That flag did not affect this project's fab output — the CI pick+place CSV is informational
  and already listed U7 — but the two files must agree, since a schematic sync overwrites the board.)* `../BOM/solar-glow-drh-v4_0-BOM-assembly.xlsx` was
  that trimmed file — rebuilt 2026-07-30 and verified 2026-08-01 to carry exactly the then-47-part
  set (37 line items) before both xlsx masters were culled 2026-08-02; the generated
  `Generated/fabdocs/` CSVs own the split now and pick up R12's departure automatically.
- **You hand-solder afterward:** SC1–SC4 supercaps and PV1–PV2 solar cells. They are kept
  **off** the PCBA BOM on purpose — the supercaps are manual-solder only (SCHURTER SCPC),
  and the cells are heat-sensitive.
- **Not placed:** SW2 (solder bridge you set; SB1–SB4 deleted 2026-08-05), TC1 (Tag-Connect pad), J1
  (optional header), MH1–MH4 **and MP1–MP4** (all eight mounting holes). *(C9 was on this list
  until 2026-07-30; it is now a placed 47 pF part. This line said "MH1–MH4" until 2026-08-04 —
  the four-versus-eight miscount again, in the list that tells the assembler what NOT to
  populate.)*

**Sourcing:** turnkey, with the standing instruction that anything PCBWay can't source they
flag and you consign from DigiKey — **no substitutes without approval**. The likeliest to
need consigning are **U1** (AVR64EA28-E/STX), **U8** (AEM10300 - e-peas harvest PMIC, source early), **U5** (NT3H2211 - going
end-of-life in places; check stock early), and **D2–D5** (the ams OSRAM amber bin — confirm
the exact reverse-mount P/N, OSRAM sells top-emit lookalikes).

**Files handed to PCBWay:** the trimmed assembly BOM, the **centroid / pick-and-place**
(KiCad → Fabrication Outputs → Component Placement; **CSV, mm, exclude-DNP** after marking
SC1–SC4 / PV1–PV2 / J1 / JP1 / TP1 as DNP — **not C9 any more**; **Absolute origin** to match
the drills), and
`../Generated/docs/solar-glow-drh-v4_0-led-orientation.png` (CI draws it from the board —
`scripts/ref_figures.py` — so it cannot lag a re-route; it replaced the hand-made
`led-orientation-D2-D5.png` on 2026-08-01).

**Order-form settings that matter:** bottom side, qty 5, ENIG (or ENEPIG, whichever quotes cleaner) **+ selective hard gold (special request above)** / matte-black / white silk,
**resin-fill + via-in-pad** (cleans the 10 via-in-pad joints and keeps the TC1 pogo pad
flat), **moisture-sensitive = U1 / U3 / U5** (U3 is a MEMS part - observe peak reflow
temp, no ultrasonic clean), no China substitutes. **Black-FR4 core stays OFF** — the glow
needs translucent FR4, the black look comes from the soldermask.

> **LED polarity (reverse-mount `LA P47F`):** anode **A** on the left, cathode **K** on the
> right, all four at **rotation 0** (see `../Generated/docs/solar-glow-drh-v4_0-led-orientation.png`).
> They emit *down* through the FR4 to the front. A flipped LED will not glow — this is the
> single most common PCBA defect on this board.
>
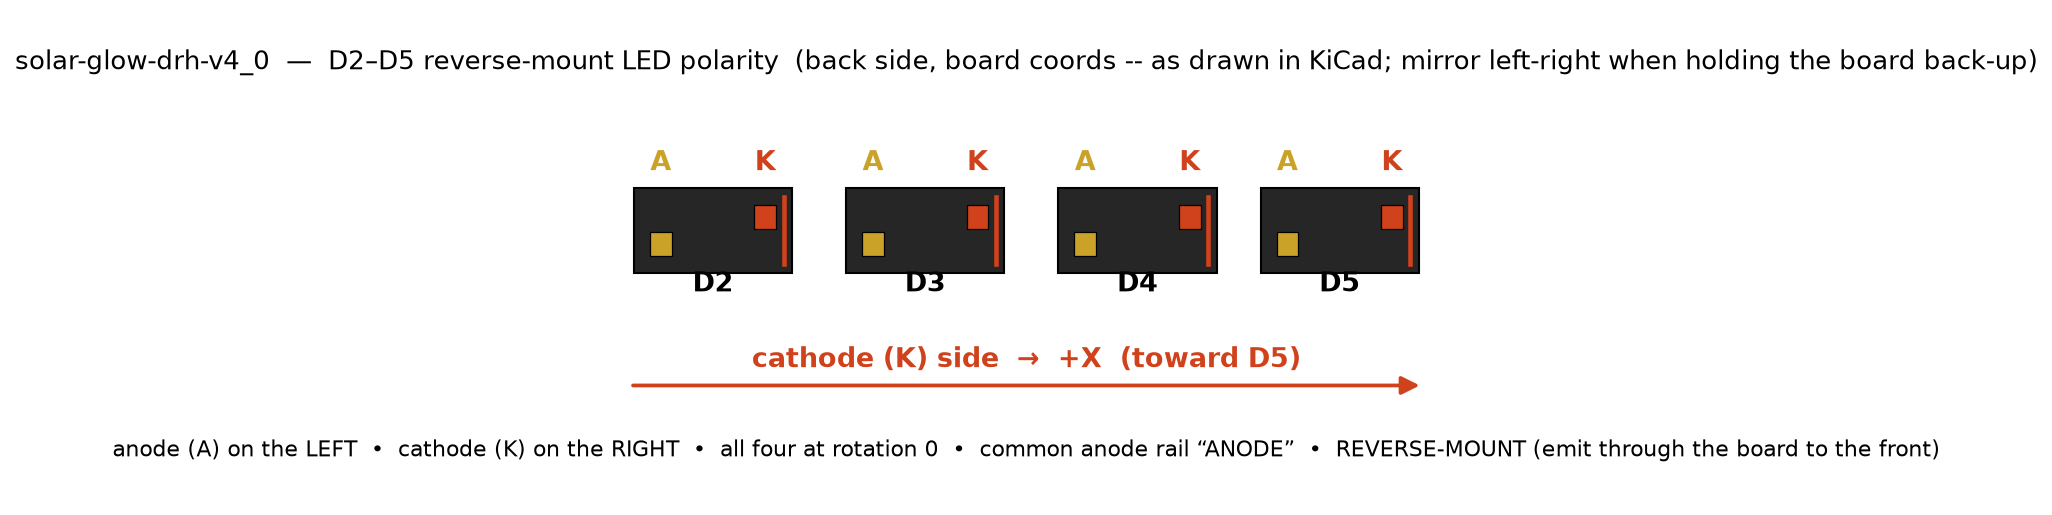
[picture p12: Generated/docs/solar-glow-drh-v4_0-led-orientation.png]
D2–D5 reverse-mount LED polarity, drawn from the board by scripts/ref_figures.py
> 

### Finishing the board by hand (after PCBWay returns it)

> ### ⚠ Program the MCU BEFORE fitting the SOLAR CELLS
>
> **TC1 moved to the FRONT in the 2026-07-30 board sync** (`5934b7d`), deliberately: the footprint
> went `B.Cu` → `F.Cu`, pads and mask with it, plus a 180° rotation. XY did not move (13.3, 16.9).
> The point of it is the programming window — see below.
>
> Worth knowing regardless: **nothing in CI catches a footprint changing sides.** DRC has no
> opinion, schematic parity has no layer concept, and `check_consistency` compares refdes and
> footprint assignment, not side. This one surfaced only because `board_parts("B")` stopped
> returning TC1 and the brace's pocket list changed with it. A side flip that *isn't* intended
> would arrive just as quietly.
>
> What it changes: **SC1 no longer blocks TC1.** The supercap is on `B.Cu` and the Tag-Connect
> pads are now on `F.Cu`, so a TC2030-MCP pogo cable reaches them with SC1 fitted. What blocks
> them now is **PV1**: the cell's body spans (2.3, 4.25)–(48.5, 27.25) and the pad cluster
> (12.219, 15.184)–(14.381, 18.616) sits well inside it. PV1's *solder pads* do not touch TC1's
> — the overlap is 0.0% — so this is a mechanical obstruction, not an electrical one.
>
> **2026-08-01: the land went double-sided.** `TC1/b` mirrors UPDI/STO/GND onto `B.Cu` at the
> same XY, so on a board fresh from PCBWay (no supercaps, no cells) the plug seats from
> **either side** — face-up or face-down on the bench, it does not care. The sequencing rule is
> unchanged, it just gains a symmetric clock: **SC1 covers the back land** (that is the accepted
> `TC1/b`↔SC1 courtyard exclusion), **PV1 covers the front land** — so hand-solder the supercaps
> and cells only after firmware is flashed and verified, same as before. `TC1/b` is bare copper
> on the B side: no paste, no part, nothing to place.
>
> So: **flash and verify the firmware first, then hand-solder the cells.** If you need to
> re-program after PV1 is on, your options are the optional **J1** UPDI header or lifting the
> cell — and the cell is the heat-sensitive part (≤ 260 °C / 2 s), which makes removing it a
> worse trade than removing a supercap was. Worth loading J1 on any board you expect to iterate
> firmware on.
>
> **The window got LATER, and that is the point of the move.** SC1 is reflowed with the rest of
> the SMD parts, so the old rule closed the programming window at reflow — you had to flash a
> board with no energy storage on it. The cells are hand-soldered last, so now you can reflow
> everything, flash a board that is otherwise complete, and only then fit PV1/PV2. The root
> README's assembly order was reordered to match: **flash is step 3, the cells are step 4.**
>
> _(Until 2026-07-30 this box read "before fitting SC1" and said both parts were on B.Cu, which
> was true of the board it was written against. TC1's XY position did not move — 100% of its pads
> are still inside SC1's outline, 5.464 mm in — only its side did, and that is the whole
> difference.)_
>
> This is the assembly consequence of the 7 × `npth_inside_courtyard` DRC exclusions. Those were
> accepted as a *geometry* decision; the ordering constraint they imply was never written down
> until the 2026-07-28 exclusion audit.
> _(This also named a `courtyards_overlap` exclusion until 2026-07-30. That violation stopped
> firing in the 2026-07-30 board sync and KiCad pruned the dead exclusion — 14 → 13. **The
> geometry did not change and neither does this warning:** TC1 is still 100% under SC1, which is
> a measurement of the two footprints, not a DRC finding. Nothing here was relaxed.)_

Work outside-in by heat sensitivity:

1. **Supercaps SC1–SC4 — hot air / hotplate, not an iron.** They solder to **flat pads under
   the body**; the **asymmetric P/N widths (P = 7.75 mm, N = 12.25 mm) are the polarity key**,
   and so is their **lateral offset** — N sits 1.50 mm in from one long edge, P 1.50 mm in from
   the other, so the two run diagonally rather than down the centreline.
   The folded end tabs are coated, non-solderable locators — never solder to those. The cells
   sit at the board ends, so localized hot air will not disturb the reflowed parts.

   > **⚠ SC1's can lands 0.090 mm from C1 — check C1 before the can goes down.**
   > _(Measured 2026-08-04: SC1 body south edge y 40.800, C1's pads start y 40.890.)_ The other
   > three have room — **SC2 0.350, SC3 0.385, SC4 0.420 mm** to their nearest neighbour — so SC1
   > is the only one where hand placement can foul a reflowed part. **The can registers to its
   > P/N pads, not to the board edge**, so a can that looks square to the outline can still be
   > sitting on C1.
   >
   > C1 cannot simply be moved out of the way, which is why this is an instruction rather than a
   > fix: it is boxed in, 0.090 mm below SC1's body and **0.154 mm above a UPDI run**
   > ((9.935, 41.780)→(10.580, 41.780)), and that UPDI run is itself only 0.153 mm from its own
   > nearest neighbour. The best translation available to C1 in ANY direction buys 0.110 mm
   > against today's 0.090 — not worth the re-route. _(The 2026-08-05 land correction below moved
   > SC1's pads ±1.30 mm **symmetrically about the body centre**, so where the can registers did
   > not move and the 0.090 stands unchanged. Re-measured on the corrected board.)_
   >
   > Nothing in CI sees this. `missing_courtyard` is `ignore` in the project file and 44 of 78
   > footprints (20 of them machine-placed) carry no courtyard at all, so the courtyard gate is
   > blind to it — the *goes quiet instead of loud* pattern this repo has been bitten by before.

   > **The lands are at datasheet pitch since 2026-08-05** — centres at **±12.30** (WS17) and
   > **±17.55** (SS17), pads on the centreline (`x = 0`, deliberately — see below). History of
   > how they got there, kept because every number in it still explains the geometry:
   >
   > **The land was wrong, and knowingly so (2026-08-03).** Measured off the SCPC
   > datasheet's Case WS10/WS13/WS17 and SS17 bottom views, the terminals are 3.50 mm long with
   > their **outer edge 0.20 mm inside the body end** — centres at **±12.30** (WS) and **±17.55**
   > (SS) — and laterally opposed as above. The board's embedded lands put both pads on the
   > centreline at ±11.00 / ±16.25: **1.30 mm per side too far in, 2.60 mm on the pitch.** The
   > cause was reading the datasheet's `1.5 ±0.5` as an inset from the *end*; it is an inset from
   > a long *edge*. A cap still soldered — about 63 % of each terminal's length landed on copper —
   > but P also overhung its 7.75 mm terminal by ~3.1 mm onto the bare can.
   >
   > `PCB/solarglow.pretty/SCHURTER_SCPC_WS17.kicad_mod` and `…_SS17.kicad_mod` **carry the
   > corrected geometry**, but the board's pads are EMBEDDED in the `.kicad_pcb` and do not read
   > from the library — so fixing the library never touched the board.
   >
   > **The four `lib_id`s now point at that library (2026-08-04).** They named `Downloads:` — a
   > path that exists on no machine here and is in no `fp-lib-table`, so KiCad could not resolve
   > them and *"Update Footprints from Library"* had nothing to update from. They are
   > `solarglow:SCHURTER_SCPC_SS17` / `…_WS17` now, and the two library footprints were brought to
   > board parity in the same pass (paste layer dropped — these are hand-soldered;
   > `exclude_from_pos_files exclude_from_bom` set, matching the flags the board already carried;
   > 3D model block added). That relink is what makes the KiCad-side fix possible — **and it also
   > arms it**, per the hand-work warning below: the update pulls the FULL datasheet geometry,
   > offset included.
   >
   > **Re-measured 2026-08-04, and the old numbers here were wrong.** They came from a sweep that
   > modelled the pad as 3.50 × 12.25 when the pad carries its own 90° rotation and is really
   > **12.25 wide × 3.50 tall** — wrong shape, wrong axis, wrong overlap set. Measured properly
   > (edit a scratch board, reload it in KiCad, test real pad polygons):
   >
   > | variant | conflicts |
   > |---|---:|
   > | pitch only (±1.30, pads stay on centreline) | **7 segments / 4 nets** |
   > | full datasheet (pitch **+** lateral offset) | **25 segments / 8 nets** |
   >
   > **⚠ A pad move invalidates the stored zone fills, and a naive text edit cannot regenerate
   > them.** `SC4` was corrected by text surgery on 2026-08-04 and **reverted the same day**: the
   > pads moved, the pours did not, and `SC4.P` (net `MID`) ended up with **6.97 mm² of GND pour
   > sitting on it** — a short. The 2026-08-05 correction landed by text surgery anyway, but only
   > because the stale-fill hazard was closed head-on: refill the zones on a scratch copy (double
   > fill, with the `.kicad_pro`/`.kicad_dru` beside the board, or the fill uses default rules)
   > and splice the changed `(filled_polygon)` payloads back by zone uuid. A pad move without
   > that step — or a KiCad session, which refills on save — re-creates the SC4 short.
   >
   > **And `--refill-zones` HIDES IT.** `kicad-cli pcb drc --refill-zones …` — the invocation
   > CLAUDE.md documents — refills in memory first, so it reported the exact ledger and 0
   > clearance errors on a shorted board. Drop the flag to see what a plotter sees: without it,
   > that board gave **2 clearance errors at 0.0000 mm** against `GND_B` and `GND_B_DCDC_SOLID`,
   > where main gave 0. **After any pad move, run DRC BOTH ways.**
   >
   > So *"the pitch is what costs, not the offset"* — which this box used to say — is **backwards**:
   > the lateral offset costs 3.5× the pitch. The offset moves P sideways by 3.125 mm into a live
   > channel; the pitch only reaches 1.30 mm further out. **So do the pitch, keep `x = 0`.**
   >
   > **All four lands were corrected 2026-08-05** — pitch only, pads kept at `x = 0` — and every
   > blocker above was re-routed rather than waived:
   >
   > - **`SC4`** — the one land with room; moved clean, as the 2026-08-04 attempt already showed.
   > - **`SC2.N`** — the `STO` run at y 3.175 dropped south into the empty channel.
   > - **`SC3.P`** — the one that could not be nudged. Its pocket was congested by the `ANODE`
   >   *feed* passing through; the fix was topological, not incremental: the ANODE tree is now fed
   >   from the D3 branch, and the old feed — segments, both vias, and their teardrops — came out
   >   whole as dead copper. (Its last link hid from the no-refill DRC behind a stored teardrop
   >   fill and only showed as a dangler under `--refill-zones` — the both-ways rule cuts both
   >   ways.)
   > - **`SC1.P`** — the 6-conflict `INT1`/`INT2`/`VSENSE` fan out of U1 re-routed within its
   >   pocket; C1 did not move (see the can-clearance note above — the 0.090 stands).
   >
   > Verified on the corrected board, both DRC modes: 0 unconnected, 0 clearance, 0 dangling,
   > exact exclusion ledger, 0 parity issues; mask art MATCH; glow-window gaps re-measured
   > teardrop-inclusive, **IN-APERTURE** (both nets clipped to the window rectangle — the metric
   > the no-mask-dam hazard actually gates on): **D2 0.3740, D3 1.2033, D4 1.8112, D5 0.7580 mm**
   > (2026-08-05, post SB/R12 deletion and DRH's R3 move). D2's pinch is the one genuinely inside
   > the aperture; the others' closest approaches all sit OUTSIDE it, under mask — e.g. R3's K4
   > copper passes 0.1780 from the ANODE tree at (27.9, 48.0), y > the window's 47.0 edge, legal
   > and dammed. _(The 2026-08-05 morning numbers — D3 0.4249 / D4 0.3634 / D5 0.5116 — were
   > region measurements with a +2 mm pickup margin; they conflated masked, DRC-legal gaps with
   > the in-window hazard. Both metrics come from the same teardrop-inclusive sweep; gate on the
   > in-aperture one.)_ **Teardrops in the re-routed pockets were deleted
   > with the copper they hugged and are NOT re-added** — run *Tools → Add Teardrops* in the next
   > GUI session; the refill on save will keep the fills honest.
   >
   > **Watch out if a cap is ever re-linked by hand:** *Update Footprints from Library* pulls the
   > FULL datasheet geometry — the lateral offset too, i.e. the 25-conflict variant. The board
   > deliberately keeps `x = 0`. And check CLEARANCE, not just overlap — `SC3.P` overlapped
   > nothing and still broke the hard floor.
   >
   > **Same warning for RN1** (Panasonic **EXB-28V151JX**, the 4×150R ballast array,
   > 2026-08-07 — AEC-Q200 Grade 1, 0.45 max, the buyable ceiling in this land; the sourcing
   > record lives in RN1's own Description field): its land is KiCad's
   > `R_Array_Convex_4x0402` with the four INNER pads slimmed 0.300 → **0.294** along-row —
   > the stock land's own inter-pad gap is 0.150, 2 µm under the 0.152 hard floor, and the
   > slim opens it to 0.153 legally instead of carrying four exclusions. *Update Footprints
   > from Library* would silently restore 0.300 and re-break DRC. Element pairing is
   > 1↔8 / 2↔7 / 3↔6 / 4↔5 (IC-style numbering) — the schematic and board both encode it;
   > a replacement part with a different pairing convention PERMUTES the LED channels.
   >
   > **RN2** (Panasonic **EXB-24V472JX**, the 2×4.7k I²C pull-up array replacing R10/R11,
   > 2026-08-08 — same EXB family and tape as RN1; second source Yageo YC122-JR-074K7L, and
   > note Yageo's YC1 prefix is convex / TC1 is concave): its land is the STOCK KiCad
   > `R_Array_Convex_2x0402` — with only two pads per row the along-row gap is 0.300, no
   > slimming needed. Element pairing is **1↔4 / 2↔3**; on the board pins 1/2 are the VS row
   > and 4/3 the signal row (SDA east, SCL west), and the schematic's labels match that order
   > — a re-annotation that "fixes" the pin numbers to put signals on pins 1/2 permutes
   > nothing electrically but breaks parity against this copper. **Pad-angle trap** (cost one
   > DRC round here): in the board file a pad's stored angle is the TOTAL rotation, so a pad
   > written without an angle on this −90° footprint sits axis-aligned — 0.5 mm wide where
   > the land wants 0.4 — and shaved the SDA-trunk gap to 0.124. All four pads carry `270`
   > now; anything that regenerates them must keep it.
   >
   > **C24 sourcing, and why its "low stock" is not a risk (2026-08-17).** The 2026-08-17
   > availability regen showed `GRT155R71H103KE01D` at **50 in stock** — the thinnest real line
   > in the BOM, and easy to misread as a part at risk. It is not. **The shortage is in the
   > VOLTAGE RATING, not the part.** The whole GRT 10 nF 0402 family is the same
   > soft-termination X7R ±10% and differs only in rating: `GRT155R71C103KE01J` (16 V) had
   > **23,548**, `GRT155R71E103KE01J` (25 V) **8,165**, against our 50 V part's 50.
   > `STO_SNS` sits at STO/3 — **1.55 V** at the AEM's 4.65 V VOVCH ceiling, 1.83 V even at the
   > 5.5 V bench-abuse corner — so 50 V is **32× over-specified**. The 16 V sibling still
   > carries ~9× margin, and its slightly larger DC-bias derating moves capacitance DOWN, which
   > SHORTENS τ: the safe direction, and already bounded by the +10%/+15% high corner that
   > `firmware/board.h` sizes the settle against. **Second source is therefore
   > `GRT155R71C103KE01J`** — same family, footprint, dielectric, tolerance, soft termination
   > and AEC-Q200, so a swap needs no board change, no firmware change, and nothing re-derived.
   >
   > **The C0G option, deliberately NOT taken.** 10 nF C0G/NP0 *does* exist in 0402 and is
   > abundant (`GRM1555C1E103GE01D`, ±2 %, 25 V, 1.3 M in stock). Being Class 1 it is ±2 % with
   > ~30 ppm/°C, no DC-bias effect and no aging, which collapses the worst-case corner from
   > 12.65 nF to **10.23 nF** — τ 8.45 → **6.83 ms**, 19 % shorter, and `STO_SNS_SETTLE_MS`
   > could come back from 53 to **43**. It is rejected because **no soft-termination C0G exists
   > at this size and value**: every GRT 10 nF 0402 is X7R, every C0G candidate is GRM standard
   > termination and not AEC-Q200. Soft termination is flex-crack protection, and this is a
   > **0.6 mm** board that lives in a wallet and gets handled — which is presumably why the
   > entire 0402 family here is GRT. What the swap would buy is 20 ms off the two-read event
   > path (106 → 86 ms) and ~36 µC against a ~0.4 J glow, i.e. charge that is noise and latency
   > this file already calls imperceptible. Trading mechanical robustness on a flexing card for
   > that is the wrong direction. Revisit ONLY if C24 has to change for real availability
   > reasons; then the settle constant comes down with it, in the same commit.
   >
   > **Both arrays' 3D models are house bodies since 2026-08-08** —
   > `solarglow.3dshapes/EXB28V_4x0402.step` / `EXB24V_2x0402.step`, single-colour 6-face,
   > gated by `part_colors` check [10]. The KiCad-library models they replaced were
   > "pre-coloured" (and so lived outside the table) with near-black bodies that rendered
   > indistinguishable from bare mask at README scale — both arrays READ AS EMPTY LANDS in
   > every populated view while resolving perfectly. The LA_P47F lesson, one ring out: a
   > model can carry colour and still be illegible; only a table entry gives it a gate.
   > `PCB/kicad-3dmodels/` is back to being purely the stock-library mirror.
   >
   > **2026-08-06 re-verification (DRH's Q2/C9/TC1 rework + the U6 DSBGA round):** same sweep,
   > same metric — in-aperture gaps **bit-identical**: D2 0.3740, D3 1.2033, D4 1.8112,
   > D5 0.7580 mm. Neither the C9 0603 land (2.4 mm north of the window) nor the TC1 wiring
   > moved anything the window gates on. The full-pairs sweep this round also put a number on
   > **`INT1`↔`INT2`: 0.1520 mm inside the aperture** — the accel interrupt pair crossing the
   > window at exactly the clearance floor. Mid-track copper, no pads, no paste: not the
   > no-mask-dam hazard class (nothing can solder there), recorded so the next sweep knows
   > the floor-exact reading is the standing state, not a regression.
   >
   > **2026-08-07 re-verification (DRH's center consolidation + cap scoot rewire):** the window
   > interior was re-routed (new teardrop set, D2/D3/D4 silk clips), so the per-LED numbers
   > moved — and all still clear the 0.3740 precedent: **ANODE↔K2 1.4337, ↔K3 0.4375,
   > ↔K4 0.6582, ↔K5 0.6496, ↔LDRV2 0.4018 mm**, teardrop-inclusive, in-aperture. The
   > floor-exact mid-track pair is now **`INT1`↔`VSENSE` at 0.1520** (the rewire re-partnered
   > it; same recorded class as the INT1↔INT2 reading above — no pads, no paste, no dam
   > needed). Nine nets cross the aperture this round (was six); GND touches at zero area.
   >
   > **2026-08-07 late (the SC1 flush-to-1.00 nudge):** moving SC1 outboard 0.026 consumed the
   > last slack in the interrupt-fan corridor NE of `SC1.P` — the corridor between the pad
   > corner and `INT1` is sized for exactly one floor-legal track. `INT2`'s approach was
   > re-bent (steeper final leg, floor-exact per the pinned KiCad's own DRC; the fan's
   > established idiom — `INT1`↔`VSENSE` sit at 0.152 exactly). **The corridor is now
   > SATURATED**: any future move of SC1, the interrupt fan, or `VSENSE` in this region
   > requires re-fanning the corridor, not nudging it.
   >
   > **2026-08-08 re-verification (the island/moat round: RN1 −6 mm west, SW2 flip, SC3
   > nudge):** full-pairs, teardrop-inclusive, in-aperture. Improved: **K2 1.5010, K3 0.5136,
   > K4 2.0740, LDRV2 >1 mm** (off the table). Held exactly: **`INT1`↔`VSENSE` 0.1520** — the
   > fan's recorded idiom survived the rework untouched. `INT2` left the window entirely.
   > **The one give-back: `ANODE`↔`K5` 0.6496 → 0.3052 mm**, below the 0.3740 precedent — a
   > boundary-entry pinch at (33.76, 47.50), both runs crossing the south rim side by side;
   > 2× the copper floor, no pad and no paste at the pinch, but it is the window's new worst
   > and the only number this round moved the wrong way. A ~0.1 mm spread of K5's entry at
   > the rim restores the precedent — flagged for DRH's next GUI pass, not blocking. Also new
   > this round: **GND now enters the aperture with real area** (the refilled pour reaches the
   > rim; four pour-clearance kisses at 0.1525 against ANODE/K2/K3/K5, all at the window
   > edges, mid-copper, no paste — the recorded INT-pair class, not the no-dam hazard class).
   > Nine nets cross (INT2 out, GND in).

   > **2026-08-08 later (the via-fleet shrink, 0.6/0.3 → 0.554/0.254):** same sweep, same
   > metric — **bit-identical to the entry above**: K2 1.5010, K3 0.5136, K4 2.0740,
   > K5 0.3052, `INT1`↔`VSENSE` 0.1520. Six via pads touch the aperture rim, but no via is a
   > binding item on any gated pair, so nothing the window gates on moved. One thing the next
   > sweep must know: **the 136 via teardrops still carry outlines built for the 0.6 pad.**
   > KiCad's zone filler refills teardrop zones but does not re-derive their outlines, and the
   > repo will not hand-roll a second implementation of KiCad's teardrop geometry (the
   > mask_art `emit(build())` lesson). So teardrop-inclusive measurements near via junctions
   > read as 0.6-era copper — honest for the artifact, conservative for the design — and the
   > shrink's clearance gain near teardropped junctions is unrealized until the next GUI
   > session runs *Edit → Edit Teardrops* over the whole board. Fold that into the same
   > teardrop pass the pocket re-route above already queued; the refill on save keeps the
   > fills honest.

   > **2026-08-08 latest (DRH's post-shrink compaction re-route):** the teardrop debt is
   > PAID — 238 → 328 teardrop zones (the moat round's deleted pocket teardrops came back
   > with the pass), and every via teardrop re-anchors at the 0.277 pad circle; the two
   > stale-outline caveats above are history. Only SC3 (−0.457 west, restoring the
   > cap-scoot 0.755 courtyard standoff the island round's nudge had broken) and TP7
   > (+0.61) moved; everything else is re-route (894 → 887 segments). Same sweep, same
   > metric: **`ANODE`↔`K5` 0.3052 → 0.3285** — the rebuilt via teardrop giving back its
   > radius at the rim, still 0.045 short of the 0.3740 precedent, so the ~0.1 mm rim
   > spread stays queued. K3 0.5058, everything else ≥ 0.57 or off the table;
   > **`INT1`↔`VSENSE` 0.1520 held exactly** through a third consecutive rework. And the
   > shrink did its job where it was aimed: floor-tight pinches involving a via fell
   > **44 → 8** (segment-level, both layers) and at-floor vias **14 → 3**, while
   > track-track floor pinches rose 140 → 152 — the freed room was spent on legal
   > compaction, which is the point.

   > **C30 (2026-08-07): a DNP 0402 trim pad in parallel with C9**, 1.36 mm west, stubbed to
   > C9's own pads across `LA`/`LB`. Two jobs: finer bench granularity than swapping C9
   > outright, and the AIR variant's retune — the open frame drops the ferrite, L falls
   > toward the bare 0.958 µH, f0 rises, and the correction is MORE parallel C, exactly what
   > this pad adds. Fit a High-Q C0G 0402 chosen at the bench (same S-series family note as
   > C9). It is dnp + excluded from BOM and CPL: no buy document mentions it until a value
   > exists, and it carries NO 3D model deliberately — the dnp-with-a-model render blind spot
   > stays an empty class.
2. **Solar cells PV1 / PV2 last (most fragile).** Iron **≤ 260 °C, ≤ 2 s per joint**, and
   **do not clean with IPA**. Mind cell polarity to the custom land.

   > **The two ground lands carry thermal relief, deliberately (2026-08-04).** `PV1.N`, `PV1.Nt`,
   > `PV2.N` and `PV2.Nt` used to be `zone_connect 2` — flooded straight into the **1744 mm²**
   > F.Cu GND pour — on the one part specced at ≤ 260 °C for ≤ 2 s. That is the same mechanism
   > this project already diagnosed and fixed for C9: *"a pad tied straight into a pour is why an
   > iron feels like it never wets."* They are now `zone_connect 1` with **four 0.4 mm spokes,
   > 0.4 mm gap**, matching C9.
   >
   > **The asymmetry was the tell.** Each cell's `P`/`Pt` mates sit on `SRC`, which has no pour —
   > only 2.1–2.7 mm² of local copper. So one terminal was heat-sunk into a 1744 mm² plane and the
   > other was not, and the two joints on the same cell behaved differently under the same 2 s
   > iron. Both ends now present a comparable thermal load.
   >
   > Electrically free: at the cell's ~**44 mA** max-power current, four 0.4 mm spokes give
   > **0.79 A/mm²**, an order of magnitude inside anything that matters.
3. **Set the LED master switch SW2** (2-pad bridge): bridged = **ON** (`ANODE` straight
   to `STO`), unbridged = **OFF** (a true hardware off — supercap-safe for storage).
   _(Until 2026-08-05 SW2 had a third pad — **TINY**, `ANODE` → R12 220 Ω → `STO`, a shared-
   ballast dim mode. Deleted with R12: one shared ballast made per-LED brightness depend on
   how many channels were lit, firmware cannot sense SW2 to compensate, and PWM duty does
   the dim job linearly.)_

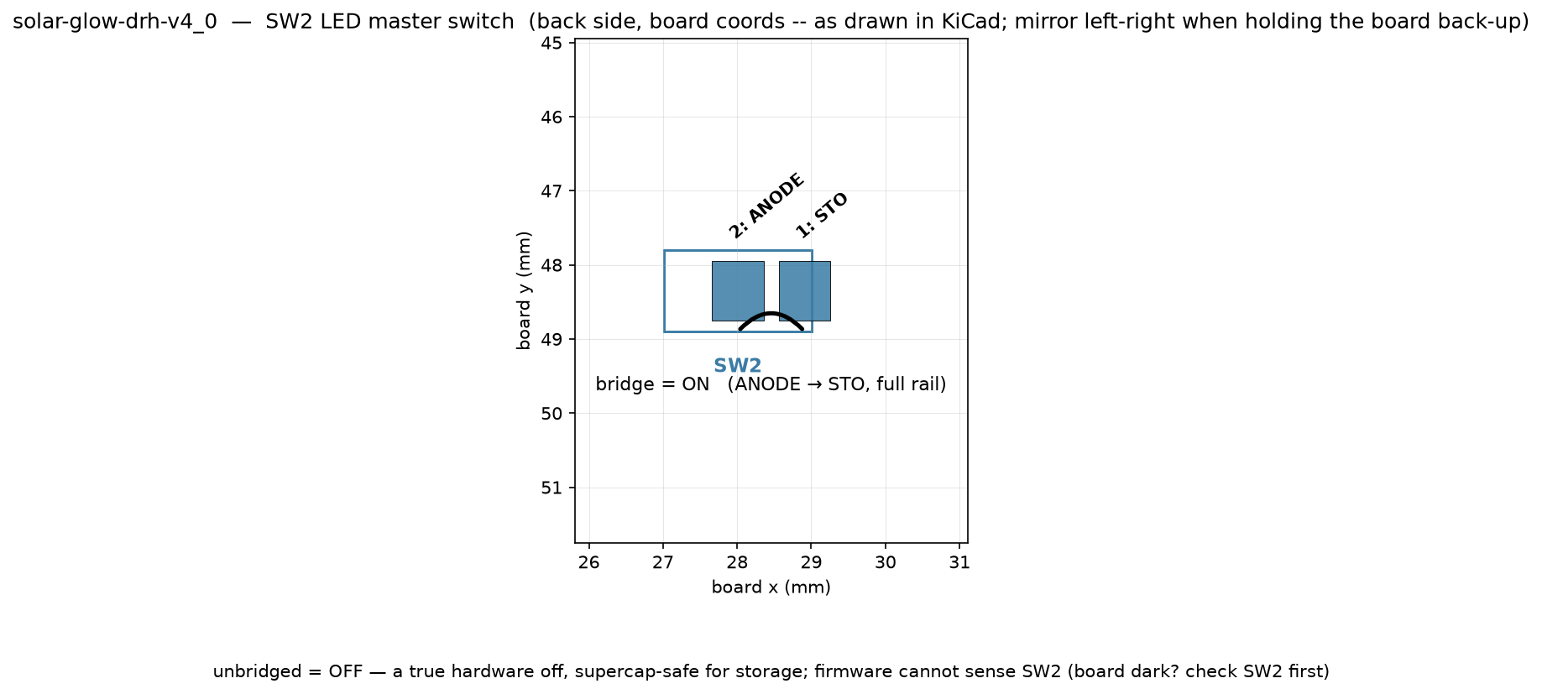
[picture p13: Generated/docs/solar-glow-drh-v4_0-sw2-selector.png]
SW2 LED master selector, drawn from the board by scripts/ref_figures.py
   
4. **SB1–SB4 no longer exist — nothing to set.** (Historical: per-LED *force-on* bridges
   shorting that LED's drive node LDRVn to GND, deleted 2026-08-05. SW2 already provides the
   master enable where one belongs, and the 150 Ω cathode ballast is sized for MCU drive, so
   force-on mode was never usable for more than a smoke test. If you find SB lands, you are
   holding a pre-2026-08-05 board — leave them open.)
5. **SJ1 no longer exists — nothing to set.** (Historical: SJ1 was the DD-era VDDIO2→VS tie.
   On the **AVR64EA28 pin 10 is plain `PD0`**, not VDDIO2 — no MVIO, no I/O-supply pin to feed —
   so bridging it would have tied a GPIO to VS. It was DNP'd with the 2026-07 EA swap and the
   symbol, land and strap were deleted from the schematic and board on 2026-07-30; U1's schematic
   note records the removal. If you find an SJ1 land, you are holding a pre-v4 board — leave it
   open.)

**Critical, do-not-get-wrong** (full rationale in `../solar-glow-drh-design-notes.md`): the
supercap under-body land and its asymmetric-width polarity key; reverse-mount LED orientation;
and the glow-window mask staying open (Step 3) — a tented window kills the optics.

---
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

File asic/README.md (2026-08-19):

# DRH-1 — the companion-ASIC experiment

**The question this directory answers** (asked 2026-08-12): *if the card's green-set silicon
— the absorb map from the custom-ASIC investigation — were taken all the way to a
wafer.space GF180MCU quarter slot, can the work be done directly, in this repo, by the
agent?*

**The answer: the digital half, yes — designed, simulated, adversarially reviewed, fixed,
and sized, in one session, with tools that install in the CI container (`apt-get install
iverilog yosys`). The analog half and everything after GDS, no — and the boundary is
sharp enough to write down.**

## What exists

| file | mirrors | what it is |
|---|---|---|
| `rtl/clkdiv.v` | main.c's PIT | 1 MHz → 128 Hz env + 1 Hz poll strobes |
| `rtl/gamma_pwm.v` | led.c | 4-ch 8-bit PWM, gamma-2, breathe/sweep/dim + the ballast duty ceiling |
| `rtl/i2c_master.v` | twi.h usage | byte-transaction master, open-drain SDA |
| `rtl/init_seq.v` | adxl367.c | ROM-driven ADXL367 config with one-retry policy |
| `rtl/sar_ctrl.v` | — | 8-bit SAR controller for the analog comparator/DAC pair |
| `rtl/sense_seq.v` | sense.c | **the deferred-read rule, in gates**: arm → settle → convert → gate off; vlow/vcrit/vclamp |
| `rtl/wake_fsm.v` | main.c | tap → glow → sweep; vcrit → dormant + brownout; NFC hold |
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

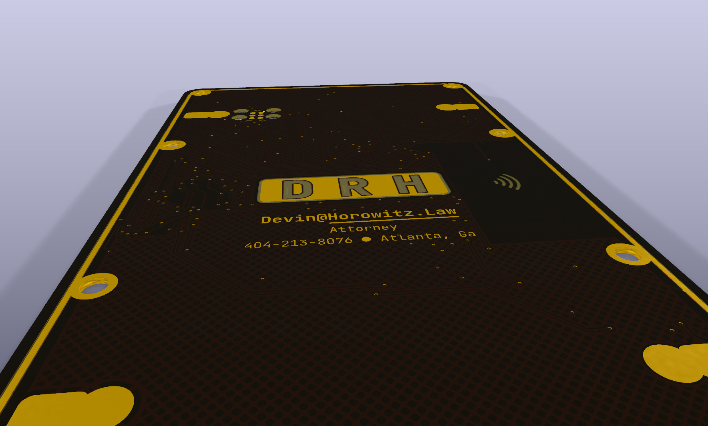
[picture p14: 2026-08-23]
Generated/docs/solar-glow-drh-v4_0-card-macro.png

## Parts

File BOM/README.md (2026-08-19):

# BOM — live availability

> **GENERATED — do not edit.** Written by [`BOM/check_stock.py`](check_stock.py)
> from the DESIGN (`scripts/bom_split.py` — the schematic plus the board's own
> flags) plus live DigiKey/Mouser data. There is no hand-authored BOM: the board
> is the source of truth for what to buy, and this file is the source of nothing —
> regenerate it, never hand-edit it.
>
> Refresh: `python3 BOM/check_stock.py` (needs `DIGIKEY_CLIENT_ID`,
> `DIGIKEY_CLIENT_SECRET`, `MOUSER_PART_API_KEY` in the environment; ~1 min).

**Checked: 2026-08-19 20:37 UTC** · DigiKey Product Information v4 + Mouser Search API, queried by MPN (stored distributor P/Ns are shown as found live, not trusted from the sheet).

**30 of 30 lines fully available** · 0 on substitute only · **0 dead (❌)** · 0 unverifiable this run · 0 manual-order.

| | Ref(s) | Qty | Mfr | MPN | Distributor P/N | Src | Lifecycle | Stock | $ @1 live |
|---|---|---|---|---|---|---|---|---|---|
| ✅ | R14, R17, R18 | 3 | Yageo | `AC0402FR-071ML` | `YAG3450CT-ND` | DigiKey | Active | 880 | $0.10 |
| ✅ | U3 | 1 | Analog Devices | `ADXL367BCCZ-RL7` | `505-ADXL367BCCZ-RL7CT-ND` | DigiKey | Active | 19,282 | $7.80 |
| ✅ | U1 | 1 | Microchip Technology | `AVR64EA28-E/STX` | `150-AVR64EA28-E/STX-ND` | DigiKey | Active | 1,365 | $1.23 |
| ✅ | FB1 | 1 | Murata | `BLM18PG221SN1D` | `490-5221-1-ND` | DigiKey | Active | 321,369 | $0.10 |
| ✅ | L2 | 1 | Murata | `DFE252010F-100M` | `490-13039-1-ND` | DigiKey | Active | 21,031 | $0.25 |
| ✅ | Q2 | 1 | Diodes Incorporated | `DMG1012T-7` | `DMG1012T-7DICT-ND` | DigiKey | Active | 164,673 | $1.17 |
| ✅ | RN2 | 1 | Panasonic | `EXB-24V472JX` | `Y5472CT-ND` | DigiKey | Active | 43,239 | $0.10 |
| ✅ | RN1 | 1 | Panasonic | `EXB-28V151JX` | `Y7151CT-ND` | DigiKey | Active | 135,736 | $0.10 |
| ✅ | C23 | 1 | Murata | `GRM188Z71E225ME43D` | `490-GRM188Z71E225ME43DCT-ND` | DigiKey | Active | 446,438 | $0.17 |
| ✅ | C25 | 1 | Murata | `GRM319R61C226KE15D` | `490-GRM319R61C226KE15DCT-ND` | DigiKey | Active | 1,538 | $0.41 |
| ✅ | C26, C27 | 2 | Murata | `GRM319R61E106KA12D` | `490-5525-1-ND` | DigiKey | Active | 330,151 | $0.46 |
| ✅ | C11 | 1 | Murata | `GRT155R71C224KE01D` | `490-GRT155R71C224KE01DCT-ND` | DigiKey | Active | 21,777 | $0.10 |
| ✅ | C24 | 1 | Murata | `GRT155R71H103KE01D` | `490-GRT155R71H103KE01DCT-ND` | DigiKey | Active | 50 | $0.10 |
| ✅ | C1, C3, C5, C6, C8, C12, C28, C29 | 8 | Murata | `GRT155R71H104KE01D` | `490-GRT155R71H104KE01DCT-ND` | DigiKey | Active | 335,673 | $0.11 |
| ✅ | C4, C13 | 2 | Murata | `GRT188R61C106KE13D` | `490-12317-1-ND` | DigiKey | Active | 764,592 | $0.29 |
| ✅ | C22 | 1 | Murata | `GRT188R71E105KE13D` | `490-GRT188R71E105KE13DCT-ND` | DigiKey | Active | 70,723 | $0.14 |
| ✅ | D2, D3, D4, D5 | 4 | ams-OSRAM | `LA P47F-V2BB-24-3B5A-30-R18-Z` | `475-LAP47F-V2BB-24-3B5A-30-R18-ZCT-ND` | DigiKey | Active | 11,153 | $0.43 |
| ✅ | U7 | 1 | RAMXEED | `MB85RC512TYPN-GS-AWEWE1` | `865-MB85RC512TYPN-GS-AWEWE1CT-ND` | DigiKey | Active | 1,500 | $10.19 |
| ✅ | R16 | 1 | Vishay | `MCT0603MD1004BP500` | `541-MCT0603MD1004BP500CT-ND` | DigiKey | Active | 28,611 | $0.23 |
| ✅ | R5, R6, R15 | 3 | Vishay | `MCT0603MD2004BP500` | `541-MCT0603MD2004BP500CT-ND` | DigiKey | Active | 60,222 | $0.22 |
| ✅ | U5 | 1 | NXP Semiconductors | `NT3H2211W0FHKH` | `568-12901-1-ND` | DigiKey | Active | 15,027 | $1.56 |
| ✅ | C9 | 1 | Johanson Technology | `QSCP251Q470G1GV001T` | `712-QSCP251Q470G1GV001TCT-ND` | DigiKey | Active | 31,425 | $0.37 |
| ✅ | U6 | 1 | Texas Instruments | `TPS22916CYFPR` | `296-50065-1-ND` | DigiKey | Active | 42,336 | $0.55 |
| ✅ | U9 | 1 | Texas Instruments | `TPS7A0233PDQNR` | `296-TPS7A0233PDQNRCT-ND` | DigiKey | Active | 1,926 | $0.89 |
| ✅ | U8 | 1 | e-peas | `10AEM10300C0000` | `120-AEM10300-QFN` | Mouser | Active (listed) | 533 | $3.77 |
| ✅ | PV1, PV2 | 2 | ANYSOLAR | `SM141K06TF` | `2994-SM141K06TF-ND` | DigiKey | Active | 421 | $7.61 |
| ✅ | SC2, SC4 | 2 | SCHURTER | `3-153-438` | `693-3-153-438` | Mouser | New Product | 198 | $16.69 |
| ✅ | SC1, SC3 | 2 | SCHURTER | `3-153-440` | `693-3-153-440` | Mouser | New Product | 200 | $16.50 |
| ✅ | FER1 | 1 | Würth Elektronik | `364006` | `710-364006` | Mouser | Active (listed) | 119 | $13.18 |
| ✅ | PRG1 | 1 | Adafruit | `5879` | `485-5879` | Mouser | Active (listed) | 31 | $6.95 |

**Verdicts** — ✅ primary MPN in stock and in production · ⚠️ primary unavailable, a documented substitute (below) is available · ❌ **primary unavailable and every documented substitute unavailable too** · ❓ the distributor query itself failed (re-run before concluding anything) · — not a distributor line.

## Documented substitutes

Hand-kept sourcing knowledge — availability shown live. Older entries were transcribed from the retired xlsx master; anything added since cites its own source in the note. These are the master's named fallbacks (C9's are its enclosed-tuning ladder, U6's an explicit last resort), not re-engineering suggestions.

| For | Substitute MPN | Lifecycle | Stock | $ @1 | Note |
|---|---|---|---|---|---|
| U1 | `AVR64EA28T-E/STX` | Active (DigiKey) | 3,300 | $1.25 | tape-reel variant, same die (U1 row note) |
| C23 | `GRT188R61E225KE13D` | Active (DigiKey) | 19,155 | $0.31 | AEC-Q200 alternate; X5R, the dielectric trade the master documents (C23 row note) |
| U7 | `MB85RC512TYPNGA1` | Restricted Availability (Mouser) | 0 | -- | same die, Mouser listing (U7 row note) |
| C9 | `QSCT251Q390G1GV001E` | Active (DigiKey) | 808 | $1.20 | 39 pF same-series ladder -- raises the enclosed resonance if the first card tunes low (C9 row note) |
| C9 | `QSCT251Q560G1GV001E` | Active (DigiKey) | 11,258 | $1.40 | 56 pF same-series ladder -- lowers it if the first card tunes high (C9 row note) |
| U6 | `TPS22918TDBVRQ1` | Active (DigiKey) | 0 | $0.75 | pin-identical AEC-Q100 sibling, ~50x the OFF leakage -- last resort only; NEVER TPS22917L (inverted EN) (U6 row note) |
| FER1 | `3641014` | Active (DigiKey) | 76 | $4.19 | 0.14 mm sheet -- stack 3x for equivalent ferrite thickness (FER1 row note) |
| FER1 | `MHLL6060-300` | Active (DigiKey) | 9,954 | $5.17 | Laird 0.09 mm -- weakest shielding, last resort (FER1 row note) |
| PRG1 | `PG164100` | Active (DigiKey) | 1,186 | $11.68 | MPLAB Snap -- the Makefile already speaks it (PROG=snap_updi), and it puts no high voltage on the UPDI line. Confirm whether yours can power the target: a flat card has no supply of its own, and if the programmer cannot provide one, use the charge-in-light path in firmware/README.md step 3 |

## Datasheet filename prices

The `datasheets/` naming convention embeds a `$price` — a copy of a live number, so it rots. Audited here against the same fetch as the tables above (±5% tolerance); `python3 BOM/check_stock.py --fix-names` renames drifted files **and rewrites every citation** (board/schematic Datasheet fields, the master's cells, tracked docs) in one act. A `$0` name is a deliberate no-ordered-part marker; price-less names (errata, the TIM pad) are informational.

| | File | Maps to | $ in name | $ live |
|---|---|---|---|---|
| ✅ | `C9  QSCP251Q470G1GV001T  $0.37.pdf` | C9 | $0.37 | $0.37 |
| ✅ | `D2-D5  LA P47F-V2BB-24-3B5A-30-R18-Z  $0.43.pdf` | D2, D3, D4, D5 | $0.43 | $0.43 |
| ✅ | `FER1  Wurth WE-FSFS 364006  $13.18.pdf` | FER1 | $13.18 | $13.18 |
| ✅ | `FER1-alt  Laird MHLL6060-300  $5.22.pdf` | FER1 sub | $5.22 | $5.17 |
| ✅ | `FER1-alt  Wurth WE-FSFS 3641014  $4.19.pdf` | FER1 sub | $4.19 | $4.19 |
| ✅ | `PV1,PV2  SM141K06TF  $7.61.pdf` | PV1, PV2 | $7.61 | $7.61 |
| ✅ | `Q2  DMG1012T-7  $1.17.pdf` | Q2 | $1.17 | $1.17 |
| ✅ | `SC1-SC4  SCHURTER 3-153-438  $16.69.pdf` | SC2, SC4 | $16.69 | $16.69 |
| ❓ | `TC1  Tag-Connect TC2030-MCP  $0.pdf` | (secondary/reference doc) (no live match) | $0.00 | — |
| — | `TIM (SC1-SC4)  t-Global T62-1 graphite  0.16mm.pdf` | (secondary/reference doc) (no price segment) | — | — |
| — | `U1  AVR64EA28 errata DS80001048C.pdf` | (secondary/reference doc) (no price segment) | — | — |
| ✅ | `U1  AVR64EA28-E-STX  $1.23.pdf` | U1 | $1.23 | $1.23 |
| ✅ | `U3  ADXL367BCCZ-RL7  $7.50.pdf` | U3 | $7.50 | $7.80 |
| ✅ | `U5  NT3H2211W0FHKH  $1.56.pdf` | U5 | $1.56 | $1.56 |
| ✅ | `U6  TPS22916CYFPR  $0.55.pdf` | U6 | $0.55 | $0.55 |
| ✅ | `U7  MB85RC512TYPN-GS-AWEWE1  $10.19.pdf` | U7 | $10.19 | $10.19 |
| ✅ | `U8  10AEM10300C0000  $3.77.pdf` | U8 | $3.77 | $3.77 |
| ✅ | `U9  TPS7A0233PDQNR  $0.89.pdf` | U9 | $0.89 | $0.89 |

All priced names within ±5% of live.

---
*Prices are qty-1 USD list at the checked timestamp; stock numbers age by the hour — re-run before ordering. Every line here is derived from the design, so the split between what PCBWay places and what you hand-solder is the one in `Generated/fabdocs/` (`…-pcbway-assembly.csv` and `…-handbuy-*.csv`), generated by the same `scripts/bom_split.py` this table is built from.*

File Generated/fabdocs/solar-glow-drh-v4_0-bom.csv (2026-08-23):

Row | Description | Part | References | Value | Footprint | Quantity Per PCB | Status | Datasheet | MPN | Manufacturer | Supplier | Supplier P/N | KiLib_Generator | Sim.Library
1 | NFC tank trim, 0603 High-Q C0G 250 V +/-2% (Johanson S-series QSCP, 0.89 max, legacy 251R14S470GV4T -- low-profile respin 2026-08-06, purpose-built RF part kept per DRH: the S-series has NO 1206 case and no maker stocks a flat RF 1206, so the same family one case DOWN. Was the 0805 QSCT, 1.17 max; the 2026-07-30 0402->0805 upsize fled 0402 rework, and 0603 is the board's workhorse hand case). PLACED at assembly as of 2026-07-30 - value derived, not trimmed: coil L = 0.958 uH by Greenhouse on the board's 7 rails, ferrite-loaded 1.05-1.30 uH, tag Ci = 50 pF (NT3H2211 Table 42), antenna Cc = 6 pF (AN11276 Table 2). 47 pF lands the enclosed resonance at 14.45 MHz against AN11276 4.2.1's 14.5 MHz single-tag target and stays above the 13.56 carrier across the whole ferrite range. Was 82 pF + DNP, which sat at 12.5 MHz enclosed - under the carrier, the wrong side to miss on. | C9 | C9 | 47pF | C_0603_1608Metric | 1 |  |  | QSCP251Q470G1GV001T | Johanson Technology | DigiKey | 712-QSCP251Q470G1GV001TCT-ND | SMD_2terminal_chip_molded
2 | 10 nF X7R ADC reservoir on STO_SNS -- sized so the GATED divider settles in ~33 ms, not ~335 ms | C24 | C24 | 10nF | C1 | 1 |  |  | GRT155R71H103KE01D | Murata | DigiKey | 490-GRT155R71H103KE01DCT-ND
3 | 100 nF X7R decoupling VSENSE filter 100 nF | C1 | C1 C3 C5 C6 C8 C12 C28 C29 | 100nF | C1 | 8 |  |  | GRT155R71H104KE01D | Murata | DigiKey | 490-GRT155R71H104KE01DCT-ND | SMD_2terminal_chip_molded
4 | Accelerometer VREG_OUT decoupling 0.22 uF | C11 | C11 | 220nF | C11 | 1 |  |  | GRT155R71C224KE01D | Murata | DigiKey | 490-GRT155R71C224KE01DCT-ND
5 | 1uF 25V 0603 X7R (GRT automotive), LDO input cap (STO_LDO island) | C22 | C22 | 1uF | C_0603_1608Metric | 1 |  |  | GRT188R71E105KE13D | Murata | DigiKey | 490-GRT188R71E105KE13DCT-ND | SMD_2terminal_chip_molded
6 | 2.2uF 25V 0603 X7R, LDO output (VS); TPS7A02 needs >=0.5uF effective - X7R holds it over temp/bias | C23 | C23 | 2.2uF | C_0603_1608Metric | 1 |  |  | GRM188Z71E225ME43D | Murata | DigiKey | 490-GRM188Z71E225ME43DCT-ND | SMD_2terminal_chip_molded
7 | VS bulk 10uF 16V 0603 X5R (was 4.7uF 0402); more effective VS bulk for transients, 0603 land LED-anode bulk 10uF 16V 0603 X5R (was 4.7uF 0402); keeps glow transient off VS, 0603 land | C4 | C4 C13 | 10uF | C_0603_1608Metric | 2 |  |  | GRT188R61C106KE13D | Murata | DigiKey | 490-12317-1-ND | SMD_2terminal_chip_molded
8 | 10uF 25V 1206 X5R LOW-PROFILE (GRM319: 0.85 +/-0.10 -> 0.95 MAX), AEM VINT buffer (min 5uF EFFECTIVE). VINT sits at 2.2V = 9 pct of rating, derating ~nil: K-tol worst ~8.7uF effective. Re-picked 2026-08-06 off the height wall (was Samsung 0805 X7R, 1.40 max). X5R is DELIBERATE: no low-profile 10uF true-X7R exists in any case size (all 1.8mm+), and the supercaps already cap the system at +85C -- exactly X5R's window. 25V rating vs the incumbent 16V. 10uF 25V 1206 X5R LOW-PROFILE (GRM319: 0.85 +/-0.10 -> 0.95 MAX), STO local bulk/decoupling. STO 5.5V max = 22 pct of rating -> ~8uF effective worst case, ABOVE the 16V 0805 X7R it replaces (5.5V was 34 pct of that rating). X5R deliberate -- see C26: the system is +85C-capped by the supercaps. Was one of the three 1.4mm-plus parts holding the enclosure height wall; 0.95 max drops the trio off it. | C26 | C26 C27 | 10uF | C_1206_3216Metric_HS_LP085 | 2 |  |  | GRM319R61E106KA12D | Murata | DigiKey | 490-5525-1-ND | SMD_2terminal_chip_molded
9 | 22uF 16V 1206 X5R LOW-PROFILE (GRM319: 0.85 +/-0.10 -> 0.95 MAX), AEM CSRC buffer at BUFSRC (aem10300 Table 6: min 13uF EFFECTIVE - footnote 1 names tolerance + DC-bias derating). Re-picked 2026-08-06 off the height wall (was TDK 0805, 1.45 max): K-tol worst 19.8uF; even -25% bias at the 4.15V Voc worst case plus 5% aging leaves ~14.1uF >= 13. Same 16V/X5R point as the incumbent, and a 1206 derates LESS than the 0805 it replaces. The 2026-07-30 note that 1206 does NOT fit was bounded by SB2, deleted 2026-08-05; refit is the board round. Confirm the exact bias curve on SimSurfing there. | C25 | C25 | 22uF | C_1206_3216Metric_HS_LP085 | 1 |  |  | GRM319R61C226KE15D | Murata | DigiKey | 490-GRM319R61C226KE15DCT-ND | SMD_2terminal_chip_molded
10 | Glow LED - reverse-mount amber | D2 | D2 D3 D4 D5 | LA P47F | D2 | 4 |  | datasheets/D2-D5 LA P47F-V2BB-24-3B5A-30-R18-Z $0.43.pdf | LA P47F-V2BB-24-3B5A-30-R18-Z | ams-OSRAM | DigiKey | 475-LAP47F-V2BB-24-3B5A-30-R18-ZCT-ND
11 | Ferrite bead 0603, STO island feed filter | FB1 | FB1 | ferrite | L_0603_1608Metric | 1 |  |  | BLM18PG221SN1D | Murata | DigiKey | 490-5221-1-ND | SMD_2terminal_chip_molded
12 | 10uH 1.76A power inductor, AEM10300 LDCDC ('U8 10AEM10300C0000 $3.77.pdf' Table 11 = DFE252010F-100M); DFE252010 = 2.5x2.0mm on a 1008/2520 land (L_1008_2520Metric) - re-run Update-PCB then route | L2 | L2 | 10uH | L_1008_2520Metric | 1 |  |  | DFE252010F-100M=P2 | Murata | DigiKey | 490-13039-1-ND | SMD_2terminal_chip_molded
13 | N-ch MOSFET SOT-523 (DMG1012T, 0.90 max -- low-profile respin 2026-08-06; was BSS138 SOT-23, 1.20) -- EN_STO_CH low-side charge-disable buffer: gate<-PA4 (CHG_DIS_G), drain->EN_STO_CH, source->GND (cold-start-deadlock fix). Same G/S/D pad order as SOT-23; Vth 1.0 max, Idss 100 nA max, VGSS +/-6 (ESD-protected gate) | Q2 | Q2 | DMG1012T | SOT-523 | 1 |  |  | DMG1012T-7 | Diodes Incorporated | DigiKey | DMG1012T-7DICT-ND
14 | NFC_EN pulldown 1 Mohm 1M 0402 EN_STO_CH pull-up to VINT 1M 0402 Q2 gate pulldown -- holds charge ENABLED while the MCU is dead/resetting (cold-start-deadlock fix) | R14 | R14 R17 R18 | 1M | R14 | 3 |  |  | AC0402FR-071ML | Yageo | DigiKey | YAG3450CT-ND
15 | 1M 0603 thin film 0.1% 25ppm, STO sense divider bottom (STO_SNS->GND); Vishay MC AT to share R15's film system | R16 | R16 | 1M | R_0603_1608Metric | 1 |  |  | MCT0603MD1004BP500 | Vishay | DigiKey | 541-MCT0603MD1004BP500CT-ND | SMD_2terminal_chip_molded
16 | VSENSE divider 2 Mohm - 0603 thin film 0.1% 25ppm GUARANTEED at 2M (matched with R6). Vishay Beyschlag MCT 0603 AT: the only 0603 that holds 25ppm at 2M (Yageo RT0603 2M is 50ppm and stockless). 2026-08-08 bump 1M->2M halves the divider's permanent SRC bleed; AEC-Q200, anti-sulfur ASTM B809. VSENSE divider 2 Mohm - 0603 thin film 0.1% 25ppm GUARANTEED at 2M (matched with R5). Vishay Beyschlag MCT 0603 AT: the only 0603 that holds 25ppm at 2M (Yageo RT0603 2M is 50ppm and stockless). 2026-08-08 bump 1M->2M halves the divider's permanent SRC bleed; AEC-Q200, anti-sulfur ASTM B809. 2M 0603 thin film 0.1% 25ppm, STO sense divider top (STO->STO_SNS) | R5 | R5 R6 R15 | 2M | R_0603_1608Metric | 3 |  |  | MCT0603MD2004BP500 | Vishay | DigiKey | 541-MCT0603MD2004BP500CT-ND | SMD_2terminal_chip_molded
17 | 4x150R isolated ballast array replacing discrete R1-R4 (DRH consolidation 2026-08-07). Panasonic EXB-28V151JX: 0804 convex, elements pair pins 1-8/2-7/3-6/4-5 CONFIRMED from the catalog's printed pin diagram and matched by the board (every K opposite its documented LDRV -- a different pairing convention would permute the LED channels). AEC-Q200 Grade 1 in the CURRENT catalog; 0.45 max height (0.15 under the lite brace's 0.60 span); J +/-5% is the buyable ceiling in this land (the only F-grade, Yageo YC124-FR, is marketplace-only 10k MOQ; KOA CN1E4 EOL; four-LED matching rests on same-substrate construction). Runner-up: Yageo YC124-JR-07150RL (lost on withdrawn AEC claim + height margin). Land: KiCad R_Array_Convex_4x0402 with inner pads slimmed to 0.294 -- see PCB/README's re-link warning. | RN1 | RN1 | 150R | R_Array_Convex_4x0402 | 1 |  |  | EXB-28V151JX | Panasonic | DigiKey | Y7151CT-ND
18 | 2x4.7k I2C pull-up array replacing discrete R10/R11 (consolidation 2026-08-07). Panasonic EXB-24V472JX, 0404 convex, elements pair pins 1-4/2-3 (verified against the EXB catalog and the KiCad land). Same EXB family/tape as RN1. Second source: Yageo YC122-JR-074K7L. Pull-ups need no matching; this is a placement consolidation. Note one body now carries BOTH bus pulls. | RN2 | RN2 | 4.7k | R_Array_Convex_2x0402 | 1 |  |  | EXB-24V472JX | Panasonic | DigiKey | Y5472CT-ND
19 | 3-axis accelerometer (tap/double-tap wake) | U3 | U3 | ADXL367 | ADXL367 CC-12-4_ADI | 1 |  | datasheets/U3 ADXL367BCCZ-RL7 $7.50.pdf | ADXL367BCCZ-RL7 | Analog Devices | DigiKey | 505-ADXL367BCCZ-RL7CT-ND
20 | AEM10300 buck-boost ambient energy harvester PMIC (MPPT), QFN-28 4x4 | U8 | U8 | AEM10300 | U8_QFN28 | 1 |  | datasheets/U8 10AEM10300C0000 $3.77.pdf | 10AEM10300C0000 | e-peas | Mouser | 120-AEM10300-QFN
21 | MCU - 8-bit AVR-EA (PWM, I2C, charge/sleep logic); EXTENDED -40..125C. Diff 12-bit ADC+PGA, 512B EEPROM, 80nA base sleep. Pin-compatible with the DD28 copper except pin 10, which is PD0/AIN0 on the EA, not VDDIO2 (no MVIO: DS40002443A Table 3-1). The DD-era SJ1 strap is REMOVED from this schematic - bridging it would have tied a GPIO to VS. FIRMWARE PORT REQUIRED - see TODO. | U1 | U1 | AVR64EA28 (VQFN28) | U1 | 1 |  | datasheets/U1 AVR64EA28-E-STX $1.23.pdf | AVR64EA28-E/STX | Microchip Technology | DigiKey | 150-AVR64EA28-E/STX-ND
22 | 512kbit I2C FeRAM 0x50, on always-on VS and parked in I2C Sleep (2026-07-23 back-power fix; VNFC now gates the tag alone); DFN LCC-8P-M05 5.0x6.0mm, 0.90mm MAX (was SOP-8 1.75mm) | U7 | U7 | MB85RC512TY | U7_DFN8 | 1 |  | datasheets/U7 MB85RC512TYPN-GS-AWEWE1 $10.19.pdf | MB85RC512TYPN-GS-AWEWE1 | RAMXEED | DigiKey | 865-MB85RC512TYPN-GS-AWEWE1CT-ND | package/gullwing | .\
23 | NFC tag - NTAG I2C plus 2K | U5 | U5 | NT3H2211 | U5 | 1 |  | datasheets/U5 NT3H2211W0FHKH $1.56.pdf | NT3H2211W0FHKH | NXP Semiconductors | DigiKey | 568-12901-1-ND
24 | Ultra-low-leakage load switch for the NFC tag rail. TPS22916C DSBGA-4 YFP (0.4 mm pitch, 0.5 max height -- the 2026-08-06 ultrathin swap; was TPS22919 SC-70-6, 1.1). C version = active-high ON, 150R QOD, slow inrush-limited ramp, reverse-current blocking. ISD 10 nA typ/100 nA max vs the 22919 2 nA typ -- +8 nA typ on the dominant OFF state, bought back 16x in ON-state IQ (0.5 uA vs 8 uA); ball map A1 VOUT, A2 VIN, B1 GND, B2 ON per SLVSDO5F Fig 5-2. STO sense-divider gate: high-side load switch, so R15/R16 draw from the tank only during a conversion | U6_TPS22916 | U6 U10 | TPS22916C | TPS22916_YFP0004 | 2 |  | SLVSDO5F | TPS22916CYFPR | Texas Instruments | DigiKey | 296-50065-1-ND | package/gullwing
25 | TPS7A0233 nanopower LDO, 3.3V fixed, ~25nA Iq (VS rail) | U9 | U9 | TPS7A0233PDQNR | Texas_X2SON-4_1x1mm_P0.65mm | 1 |  |  | TPS7A0233PDQNR | Texas Instruments | DigiKey | 296-TPS7A0233PDQNRCT-ND | package/gullwing
Project info:
Schematic: | solar-glow-drh-v4_0
Variant: | default
Revision: | v4.0
Date: | 2026-08-04
KiCad Version: | 10.0.5-unknown-202607221313~667fa36054~ubuntu25.10.1
Statistics:
Component Groups: | 25
Component Count: | 42
Fitted Components: | 42
Number of PCBs: | 1
Total Components: | 42

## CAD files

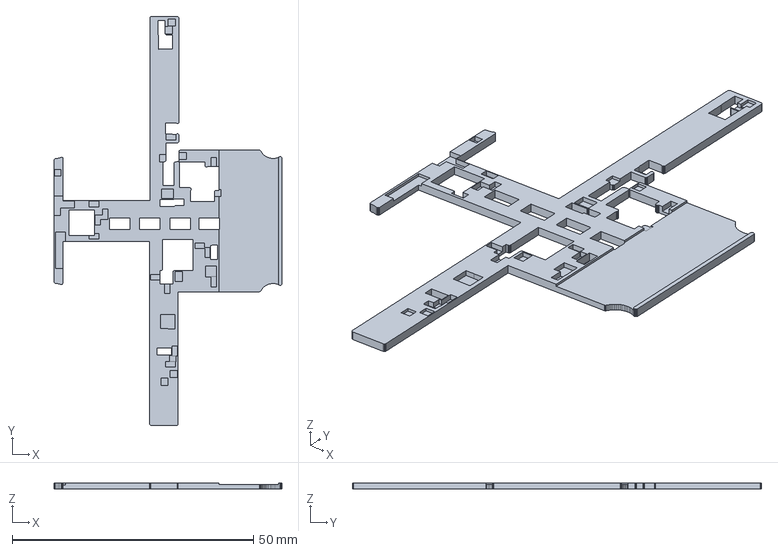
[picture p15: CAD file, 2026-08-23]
enclosure/brace/solar-glow-drh-diffuser-brace-lite.step
47.2 x 84.8 x 1.22 mm

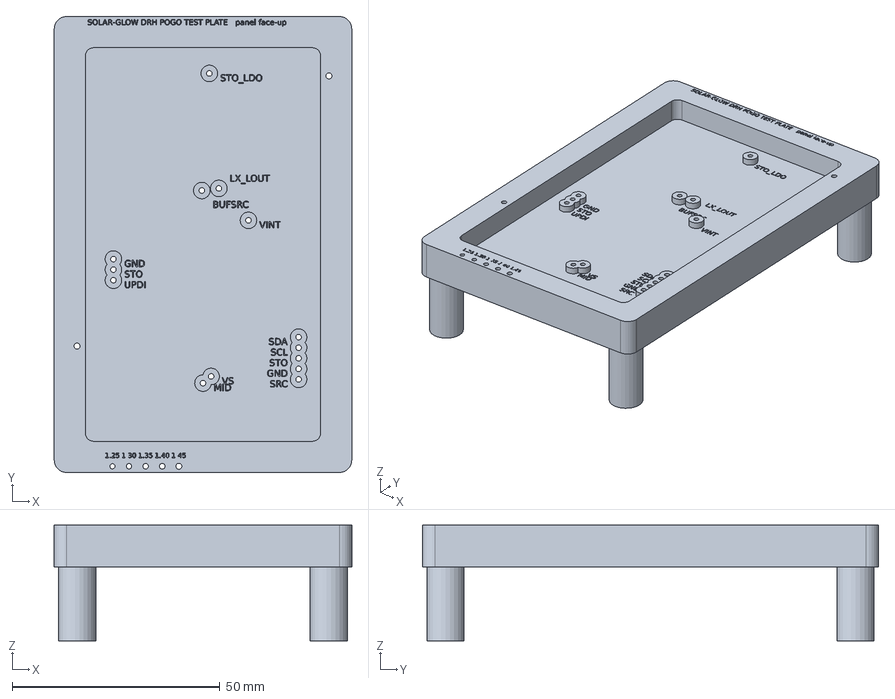
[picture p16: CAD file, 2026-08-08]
enclosure/solar-glow-drh-pogo-testplate.step
71.6 x 109.7 x 27.8 mm

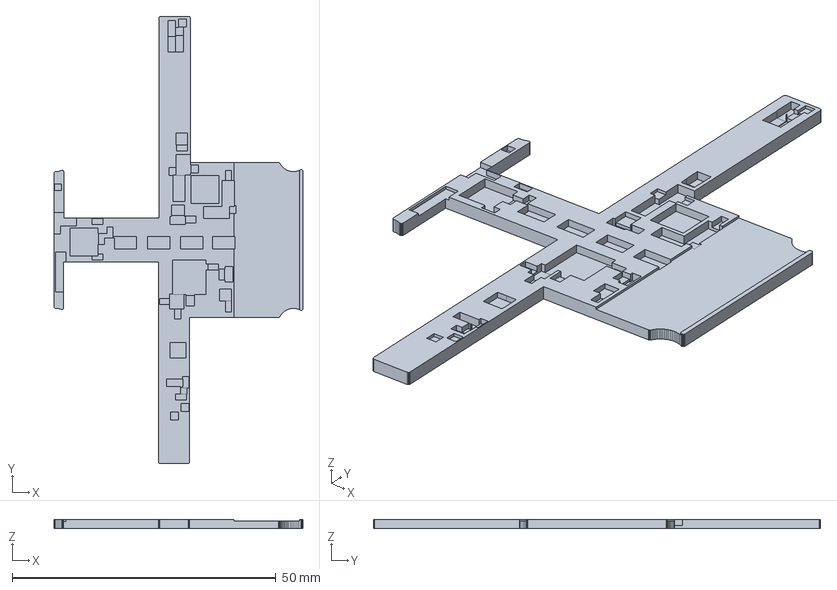
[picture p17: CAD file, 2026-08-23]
enclosure/brace/solar-glow-drh-diffuser-brace.step
47.2 x 84.8 x 1.80 mm

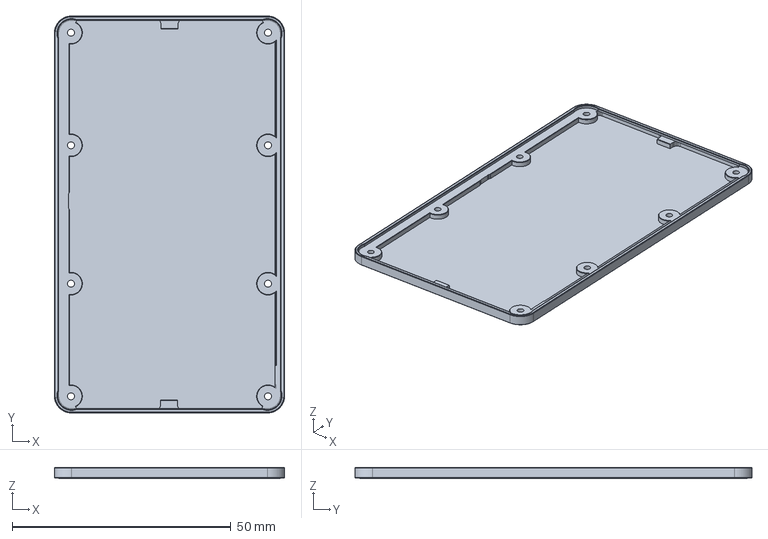
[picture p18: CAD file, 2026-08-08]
enclosure/solar-glow-drh-shell-lite-Ti.step
52.7 x 90.8 x 2.57 mm

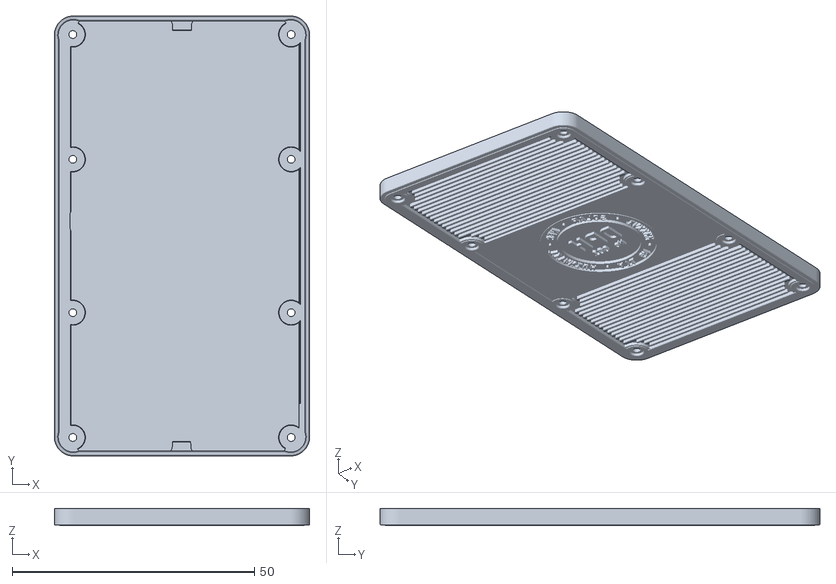
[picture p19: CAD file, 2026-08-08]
enclosure/solar-glow-drh-v4_0-backshell-0p6b-brace-Ti-max.stl
52.7 x 90.8 x 3.55

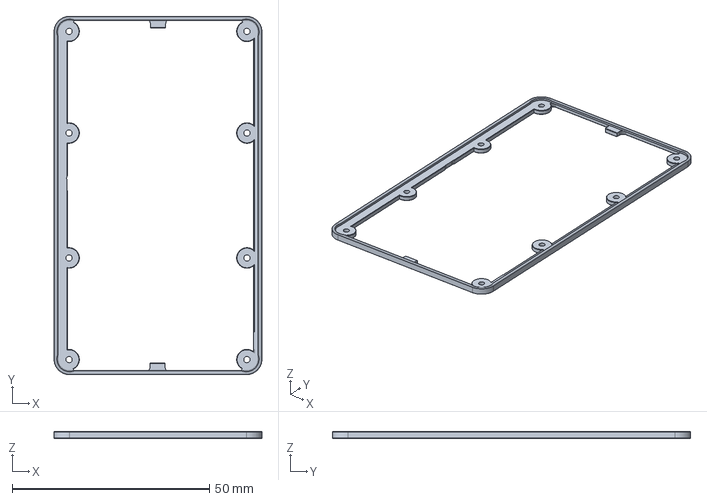
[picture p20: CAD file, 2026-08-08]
enclosure/solar-glow-drh-frame-air-316L.step
52.7 x 90.8 x 1.80 mm

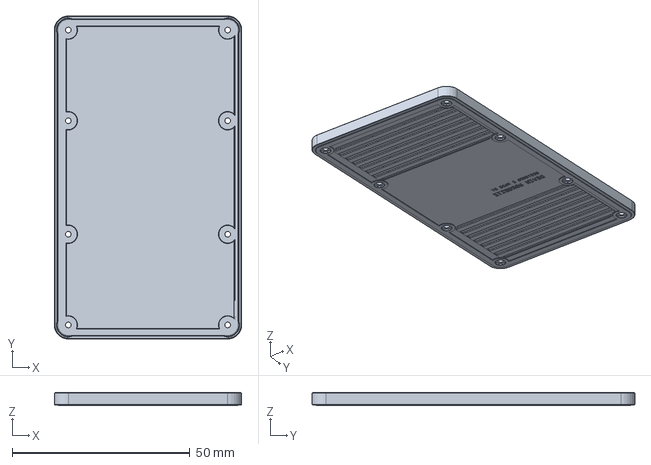
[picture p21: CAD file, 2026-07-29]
enclosure/solar-glow-drh-v3_0-backshell-0p6b-brace-Ti-max.step
52.7 x 90.8 x 3.55 mm

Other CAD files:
enclosure/shim/solar-glow-drh-reflow-shim.dxf
enclosure/solar-glow-drh-v3_0-backshell-0p6b-brace-Ti-max-progwindow.step
enclosure/brace/solar-glow-drh-diffuser-brace-lite.stl
enclosure/brace/solar-glow-drh-diffuser-brace.stl
enclosure/solar-glow-drh-frame-air-316L.stl
enclosure/solar-glow-drh-pogo-testplate.stl
enclosure/solar-glow-drh-shell-lite-Ti.stl

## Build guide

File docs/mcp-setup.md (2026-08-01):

# MCP setup handoff -- distributor part APIs (DigiKey + Mouser)

> **DONE / reference only (2026-07-25).** The job this handoff describes is finished: both APIs are
> live and **every ordered BOM line is priced** — no `TBC` cells remain. Keep this as the setup
> recipe + credential/proxy reference for future sourcing work; nothing here is outstanding.

**Purpose.** Stand up the DigiKey and Mouser part APIs so a session can pull live part
pricing / stock / specs into the BOM work -- originally to close the SS17 `3-153-440` unit price
then marked **TBC** in `BOM/solar-glow-drh-v4_0-BOM.xlsx`. This doc exists so a fresh session can
work the distributor APIs cold, without cross-chat.

## Status

**2026-07-22 (latest) -- BOTH DISTRIBUTOR APIs NOW LIVE; the BOM is fully priced.** DigiKey and
Mouser both return live data; every ordered on-board line has a price. (Earlier in the day the Mouser
key was still rejected -- see the Mouser bullet -- but it has since come live.) Went straight to live
API calls (no MCP wrapper needed to prove connectivity):
- **Network policy now permits both hosts.** `https://api.digikey.com` -> `404` and
  `https://api.mouser.com` -> `302` (real HTTP responses, not the old `000` / `CONNECT tunnel failed`).
  General web is partly open too (`example.com` -> `200`; `www.digikey.com` still `403`). The two API
  hosts we need are reachable.
- **Credentials are now set.** `DIGIKEY_CLIENT_ID` (48 ch), `DIGIKEY_CLIENT_SECRET` (64 ch),
  `MOUSER_PART_API_KEY` (36-ch GUID) are all present in the container.
- **DigiKey: WORKING.** OAuth2 client_credentials returned a bearer token (HTTP 200), and a
  Product Information V4 `keyword` search returned live data. Results used to close the BOM TBC:
  - **SS17 `3-153-440`** (DK `486-3-153-440-ND`): **$17.16 @ 1**, 200 in stock (10@$13.48, 100@$11.55).
  - **WS17 `3-153-438`** (DK `486-3-153-438-ND`): **$16.69 @ 1**, 195 in stock (was $15.48 @ 2026-07-02).
  Both written into `BOM/solar-glow-drh-v4_0-BOM.xlsx` (SC1/SC3 row filled; SC2/SC4 refreshed;
  subtotal recomputed to $130.00 / 30 priced cells).
- **Mouser: WORKING (now).** Earlier in the day `search/partnumber` returned HTTP 200 with
  `{Code: "Invalid", Message: "Invalid unique identifier", PropertyName: "API Key"}` -- the key was not
  yet an activated Search key. It has since come live: `search/partnumber` for `10AEM10300C0000` returns
  the real listing and closed the last BOM line:
  - **U8 (AEM10300)** -> Mouser `120-AEM10300-QFN` (e-peas), **$3.77 @ 1**, 553 in stock, 16-day lead
    (breaks 10@$2.81, 100@$2.31, 1000@$1.85). Written into `BOM/solar-glow-drh-v4_0-BOM.xlsx` (`R35`).
  U8 is the only Mouser-only line (DigiKey returns 0 results for it); everything else is DigiKey-sourced.
- **MCP registration is optional now.** DigiKey's data was pulled directly (curl/`requests` through the
  proxy CA), so the BOM job is done without the MCP servers. To make `digikey` / `mouser` tools available
  to future *interactive* sessions, put `scripts/setup-distributor-mcp.sh` in the **environment setup
  script** (a mid-session `claude mcp add` only affects the current ephemeral container and does not
  hot-load into an already-running session). The script stays valid; only the Mouser key needs fixing.

_Prior status (2026-07-22, earlier sessions): servers cloned + `uv sync`'d + smoke-tested, then blocked
first by the egress `403`, then by unset credentials, then by an unactivated Mouser Search key. All
three are now resolved -- both APIs are live and the BOM is fully priced._

## Prerequisites

1. **Network policy** must allow outbound HTTPS to `api.digikey.com` and `api.mouser.com`
   (enabled 2026-07-22; effective in a new container).
2. **Runtimes** already present in the CCR environment: `uv`, python 3.11, git. `requests` honors
   `REQUESTS_CA_BUNDLE` (the proxy CA), so TLS through the egress proxy works once the host is allowed.
3. **Credentials as environment variables** (set in the environment settings -- not in chat, not in
   the repo):
   - `DIGIKEY_CLIENT_ID`, `DIGIKEY_CLIENT_SECRET` -- from developer.digikey.com: a **Production App**
     with the **Product Information V4** product enabled, client-credentials grant (no callback URL).
   - `MOUSER_PART_API_KEY` -- from mouser.com/api-hub -> **Search API** (the Order/Cart key is not
     needed). The Search key requires an access-request form with approval lag, so request it early.

## Per-container setup (put this in the environment setup script)

**Shortcut:** `scripts/setup-distributor-mcp.sh` runs everything below in one idempotent step
(preflight-checks the creds + host reachability, clones/`uv sync`s both, writes each `.env`, and
registers both servers). The manual steps are equivalent and kept here for reference.

Clones live outside any repo (e.g. `/home/user`) so nothing here touches the board repo:

```sh
# DigiKey -- bengineer19/digikey_mcp (Python; DigiKey Product Information V4)
git clone https://github.com/bengineer19/digikey_mcp.git /home/user/digikey_mcp
uv sync --directory /home/user/digikey_mcp
printf 'CLIENT_ID=%s\nCLIENT_SECRET=%s\n' "$DIGIKEY_CLIENT_ID" "$DIGIKEY_CLIENT_SECRET" > /home/user/digikey_mcp/.env

# Mouser -- nickweedon/mouser-mcp-docker (run as plain Python, NOT its shipped .mcp.json)
git clone https://github.com/nickweedon/mouser-mcp-docker.git /home/user/mouser-mcp-docker
uv sync --directory /home/user/mouser-mcp-docker
printf 'MOUSER_PART_API_KEY=%s\n' "$MOUSER_PART_API_KEY" > /home/user/mouser-mcp-docker/.env

# register both (they load at session start)
claude mcp add digikey -- uv run --directory /home/user/digikey_mcp python digikey_mcp_server.py
claude mcp add mouser  -- uv run --directory /home/user/mouser-mcp-docker mouser-mcp
```

Manual alternative (no env config): start a fresh session, provide the keys, and run the same
clone / `uv sync` / `.env` / `claude mcp add` steps by hand.

## Per-server notes and gotchas

### DigiKey -- `bengineer19/digikey_mcp`
- API: Product Information V4 (`/products/v4/search/...`); auth: OAuth2 **client_credentials**
  (no callback URL needed).
- Tools: `keyword_search`, `product_details`, `get_product_pricing`, `search_product_substitutions`,
  `get_product_media`, `search_manufacturers`, `search_categories`, `get_category_by_id`, digireel pricing.
- It **fetches the OAuth token at startup**, so it will not launch without valid creds.
- **Gotcha:** `USE_SANDBOX` is inverted vs the README. **Leave it unset** for production
  (`api.digikey.com`). Setting `USE_SANDBOX=false` selects the sandbox (fake data), despite what the
  README says. Only set it to `false` to deliberately test against sandbox.

### Mouser -- `nickweedon/mouser-mcp-docker`
- A `fastmcp` Python server packaged in Docker. Docker is optional -- run it directly with
  `uv run mouser-mcp` (the `pyproject.toml` exposes that script).
- **Ignore the repo's shipped `.mcp.json`** -- it is a wrong copy-paste (a Playwright config), not Mouser.
- Needs only `MOUSER_PART_API_KEY` (Search API) for part search/pricing. Imports fine without keys;
  keys are read per call.
- Tools: `search_by_keyword`, `search_by_part_number` (plus cart/order tools that need the unused
  Order key).

## First queries once live

- **DigiKey -- DONE 2026-07-22.** `keyword` search for `3-153-440` (SS17) and `3-153-438` (WS17) both
  returned live pricing/stock; the SS17 TBC is filled and the WS17 refreshed in
  `BOM/solar-glow-drh-v4_0-BOM.xlsx` (see Status).
- **Mouser -- DONE 2026-07-22.** `search_by_part_number` for `10AEM10300C0000` returned the live listing
  (`120-AEM10300-QFN`, $3.77 @ 1, 553 in stock); the U8 (`R35`) price/stock is filled in the BOM (see Status).

## Security

- Keys live only in environment variables + each clone's `.env` (gitignored, outside this repo).
  Never commit them.
- The DigiKey Client ID/Secret were pasted into a chat transcript during setup. Rotate them once on
  the app page if that matters (regenerating is one click), then update the env var.

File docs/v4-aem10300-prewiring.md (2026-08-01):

# v4 AEM10300 pre-wiring plan (net + pin assignments)

Companion to `solar-glow-drh-design-notes.md` -> "Addendum (2026-07-15) -- v4 active-harvest option".
**Status: v4.0 ADOPTED — and the respin this plan drove is DONE.** The board is fully routed
(0 unconnected) and the schematic was synced to it 2026-07-30 (`v4-schematic-sync-checklist.md`);
this document is now the **record of what was applied**, kept for lineage — the `.kicad_pcb` and
`.kicad_sch` are the truth. _(Original framing follows:)_ This is the executable net/pin list for the manual KiCad respin: add the
new parts off to the side, wire each pin to the net named here (the ratsnest then guides placement), and
delete the parts in section 4. Every net/refdes below was read from the committed
`PCB/solar-glow-drh-v4_0.kicad_pcb`.

## Net model (what changes)

The as-built `VS` net does two jobs at once (storage top AND the MCU/accel supply) because the clamp fuses
them. The AEM splits them:

- **`VS` is redefined as the regulated 3.3 V rail** (the TPS7A02 output). The MCU, accel, I2C pull-ups,
  decoupling, VDDIO2, and the load switch all *stay on `VS`* -- they just get a clean 3.3 V now instead of
  the clamped supercap. This keeps firmware/doc churn minimal ("VS" still means "the MCU rail").
- **`STO` is a new net** = the supercap top (unclamped, 0.2 - 4.65 V). Supercaps, the LED feed, bench power,
  the AEM, and the LDO input live here.
- **`SRC` is a new net** = the merged panel node (old `VIN` + `VINB`) feeding the AEM harvester.
- Vanishing nets (clamp/comparator subcircuit): `CLBASE`, `CLREF`, `REF_TIE`, `VCMP`, `VIN`, `VINB`.

## 1. New components (place to the side)

| Refdes | Part | Package | Role |
|---|---|---|---|
| **U8** | AEM10300 | QFN-28 4x4 | harvest PMIC + 2-cell balancer |
| **U9** | TPS7A0233 (fixed 3.3 V) | SOT-23-5 | MCU + accel LDO (25 nA) |
| **L2** | 10 uH, 1.76 A (Murata DFE252010F-100M) | 2.5x2.0x1.0 mm | buck-boost inductor |
| **C25** (was CSRC) | 22 uF 10 V | 0603 | BUFSRC input buffer |
| **C26** (was CINT) | 10 uF | 0402 | VINT buffer |
| **C27** (was CSTO) | 10 uF 10 V | 0603 | STO local bulk/decoupling |
| **C22** | 1 uF | 0402 | LDO input cap |
| **C23** | 2.2 uF 10 V | 0402 | LDO output cap (stability) |
| **R15, R16** | 2 M, 1 M | 0402 | STO sense divider (÷3) |
| **C24** | 100 nF | 0402 | STO-sense filter |
| **R17** | 1 M | 0402 | EN_STO_CH pull-up to VINT |
| **FB1** | ferrite bead | 0603 | STO island feed filter |

(Refdes U8/U9/L2/... are suggestions; renumber to your scheme. ST_STO status pins left unpopulated --
charge state comes from the STO ADC read, so the AEM `ST_STO` pin is a test point / DNP.)

## 2. Pin -> net for the new components

**U8 AEM10300** (straps: R_MPP = HLL 80%, T_MPP = LH, STO_CFG = LLHH dual-cell supercap, EN_HP = GND,
EN_STO_FT = GND):

| Pin | Name | Net | | Pin | Name | Net |
|---|---|---|---|---|---|---|
| 1 | ZMPP | *NC (float)* | | 15 | STO_OVDIS | *NC (float)* |
| 2 | SRC | `SRC` | | 16 | STO_RDY | *NC (float)* |
| 3 | GND | `GND` | | 17 | STO_OVCH | *NC (float)* |
| 4 | BUFSRC | `BUFSRC` | | 18 | STO_CFG[3] | `GND` (L) |
| 5 | LIN | `LX_LIN` | | 19 | EN_HP | `GND` |
| 6 | LOUT | `LX_LOUT` | | 20 | T_MPP[0] | `VINT` (H) |
| 7 | GND | `GND` | | 21 | EN_STO_FT | `GND` |
| 8 | R_MPP[2] | `VINT` (H) | | 22 | T_MPP[1] | `GND` (L) |
| 9 | R_MPP[1] | `GND` (L) | | 23 | STO_CFG[0] | `VINT` (H) |
| 10 | VINT | `VINT` | | 24 | STO_CFG[1] | `VINT` (H) |
| 11 | R_MPP[0] | `GND` (L) | | 25 | STO_CFG[2] | `GND` (L) |
| 12 | EN_STO_CH | `EN_STO_CH` | | 26 | ST_STO | *NC / TP (DNP)* |
| 13 | BAL | `MID` | | 27 | GND | `GND` |
| 14 | STO | `STO` | | 28 | CS_IN | `SRC` |
| | | | | EP | pad | `GND` |

**U9 TPS7A0233:** 1 IN -> `STO`, 2 GND -> `GND`, 3 EN -> `STO` (always-on), 4 NC, 5 OUT -> `VS`.
**L2:** 1 -> `LX_LIN`, 2 -> `LX_LOUT`.
**C25/CSRC:** 1 -> `BUFSRC`, 2 -> `GND`. **C26/CINT:** 1 -> `VINT`, 2 -> `GND`. **C27/CSTO:** 1 -> `STO`, 2 -> `GND`.
**C22 (LDO in):** 1 -> `STO`, 2 -> `GND`. **C23 (LDO out):** 1 -> `VS`, 2 -> `GND`.
**R15:** 1 -> `STO`, 2 -> `STO_SNS`. **R16:** 1 -> `STO_SNS`, 2 -> `GND`. **C24:** 1 -> `STO_SNS`, 2 -> `GND`.
**R17 (EN_STO_CH pull-up):** 1 -> `VINT`, 2 -> `EN_STO_CH`.
**FB1:** in series on the STO feed leaving the island (AEM-local STO <-> board `STO`); a layout element,
net stays `STO` both sides for schematic parity.

## 3. Existing pins that re-net

**Move off `VS` -> `STO`** (storage / LED feed / bench power entry):

| Pin | Was | Now | note |
|---|---|---|---|
| SC1.P, SC2.P | VS | `STO` | pack top-stage positives |
| SW2.1 | VS | `STO` | LED full-bright feed |
| R12.2 | VS | `STO` | SW2 TINY-mode ballast (R12 stays) |
| J1.2, JP1.2, TC1.2 | VS | `STO` | bench / prog power -> storage (update bench pad-strip labels) |

**Merge panels -> `SRC`** (old `VIN` + `VINB` collapse; blocking diodes gone):

| Pin | Was | Now |
|---|---|---|
| PV1.P, PV1.Pt | VIN | `SRC` |
| PV2.P, PV2.Pt | VINB | `SRC` |
| R5.1 | VIN | `SRC` (VSENSE light divider now senses SRC) |
| TP1.1 | VIN | `SRC` |

**`MID`:** add **U8.13 (BAL)**; drop U2.4/6/7 (U2 deleted). Supercap taps (SC1.N, SC2.N, SC3.P, SC4.P) stay.

**Stay on `VS` (now the regulated 3.3 V rail)** -- no wire change, but confirm intent:
U1.18, U1.24 (MCU VDD); U3.10, U3.12 (accel VDD); R10.2, R11.2 (I2C pull-ups); C1.1, C4.1, C6.1, C7.1,
C12.1 (decoupling); SJ1.1 (-> VDDIO2); U6.1 (NFC/FRAM load-switch input). Add **U9.5 (LDO OUT)** and
**C23.1** here as the rail's source.

## 4. MCU spare-pin assignments (new signals)

| MCU pin | Pad | Net | Direction | Role |
|---|---|---|---|---|
| PD1 (AIN1) | 11 | `STO_SNS` | ADC in | supercap-state sense (÷3 divider) |
| PA4 | 2 | `CHG_DIS_G` | GPIO out, push-pull | gate of Q2, the low-side charge-disable buffer (HIGH = disable AEM charging during an NFC read) |
| PC0 | 6 | *(reserved)* | -- | optional ST_STO if ever populated |

PD1 is currently `unconnected-(U1-PD1-Pad11)`; PA4 is the JP2.1 spare. EN_STO_CH is 2.75 V-max.
_(Superseded 2026-07-23 — the cold-start-deadlock fix.)_ PA4 no longer drives EN_STO_CH directly:
a dead MCU's pin clamp held that node low and **permanently disabled charging** on a fully drained
card. PA4 now drives the **gate of Q2** (BSS138, low-side) on net `CHG_DIS_G`, push-pull, HIGH =
FET on = EN_STO_CH pulled low = charging disabled; **R18** (1 M gate pulldown) holds the FET off —
charging **enabled** — whenever the MCU is dead, resetting, or being programmed. R17 still pulls
EN_STO_CH up to VINT. See the design-notes second-sift addendum.

## 5. Delete these (with the nets they take with them)

| Refdes | Part | Why gone |
|---|---|---|
| **U2** | ALD910025 balancer | AEM `BAL` pin does it on-chip |
| **U4** | TLV3011 comparator | AEM `VOVCH` handles overvoltage |
| **Q1** | BCP5316 PNP | shunt clamp removed |
| **R7, R8** | 6.81 M / 3.74 M | clamp reference divider |
| **R9** | 1 k | Q1 base resistor (VS -> CLBASE) |
| **D10, D11** | MMSD301T1G | comparator-supply OR |
| **C2** | 100 nF | VCMP decoupling |
| **D1, D9** | MMSD301T1G | per-panel blocking (AEM has reverse protection; keep panels diode-less for low-V harvest efficiency) |

Nets removed: `CLBASE`, `CLREF`, `REF_TIE`, `VCMP`, `VIN`, `VINB`.

**Keep (do not delete):** R12 (TINY ballast, re-net to STO), C13 (LED anode bulk, on ANODE), R5/R6/C5
(VSENSE divider, now on SRC), R10/R11 (I2C pull-ups), R14 (NFC_EN pulldown), U6 (load switch), SJ1, SW2.

## 6. Verify after wiring

- ERC/DRC: the vanished nets (VCMP/CLBASE/...) leave no dangling pins; `SRC`/`STO`/`VINT`/`LX_*` are new.
- `scripts/check_consistency.py`: board.h pin map picks up PD1/PA4 additions; BOM gains U8/U9/L2/... and loses U2/U4/Q1/R7-9/D1/D9-11/C2.
- Firmware (staged as `v4-aem10300-firmware.patch`, see section 8): re-points `sense_vdd_mv()` + the four
  rail gates from VDD/10 to the `STO_SNS` AIN, re-folds the count macros, and adds the EN_STO_CH
  open-drain gate on the FD edge.

## 7. board.h additions (apply in lockstep with the schematic)

> **APPLIED (2026-07-18):** these edits, originally captured as **`v4-aem10300-boardh.patch`** (repo root),
> have been applied. **board.h now carries** the **PA4 -> EN_STO_CH** and **PD1 -> STO_SNS** pin-map lines and
> the `STO_SNS_AIN` / `STO_DIVIDER` / `ENSTOCH_PORT` / `ENSTOCH_PIN_bm` `#define` blocks described below. The
> precondition that once blocked the patch is satisfied: the reworked `.kicad_pcb` + `.kicad_sch` are in place
> and put **U1.PA4 on net `EN_STO_CH`** and **U1.PD1 on net `STO_SNS`** (PD2/`VSENSE` keeps its net name but now
> divides `SRC`), so the pin contract matches and `check_consistency.py` passes. The patch was minimal (pin-map
> + the two `#define` blocks); bumping the board.h header `v3.0 -> v4.0` and swapping residual `VIN` comments to
> `SRC` remain cosmetic follow-ups.

`scripts/check_consistency.py` parses board.h's pin-map table and compares it against the **schematic
netlist**; these edits landed in the **same commit as the schematic net rename** (PD1 -> `STO_SNS`,
PA4 -> `EN_STO_CH`), so board.h is not ahead of the netlist and CI passes. Recorded here so the apply history
is clear.

**Pin-map table** -- change the PA4 line, add a PD1 line (keep the column format the parser reads; net name
must match the schematic exactly):

```
 *     2 PA4      EN_STO_CH  AEM10300 charge gate (open-drain, LOW = disable during NFC read)
 *    11 PD1      STO_SNS    supercap-state sense  AIN1 (STO via R15/R16 divide-by-3)
```

PA4 was `spare GPIO (JP2.1)`; PD1 was unconnected. PD2/`VSENSE` keeps its pin but now senses `SRC` (light) --
update its role comment; no functional change.

**New #defines** (add near the existing sense / NFC blocks):

```c
/* ---- supercap-state sense on PD1 (AEM10300 STO via divide-by-3) ----
 * VS is now the regulated 3.3 V LDO output (constant), so the old VDD/10 read no longer tracks
 * the pack. STO (0.2..4.65 V) is divided by 3 into AIN1/PD1; the re-pointed sense_vdd_mv() reads
 * this channel and scales back: STO_mv = pin_mv * STO_DIVIDER. */
#define STO_SNS_AIN     ADC_MUXPOS_AIN1_gc     /* PD1 = AIN1 */
#define STO_DIVIDER     3                       /* R15 / R16 = 2 M / 1 M */

/* ---- AEM10300 charge gate on PA4 (EN_STO_CH), ACTIVE-LOW, emulated open-drain ----
 * Drive OUTPUT-LOW to disable AEM charging -> the >=10 MHz DCDC goes quiet for an NFC read;
 * RELEASE (set INPUT / Hi-Z) to re-enable (R17 pulls it to VINT). Driven from the FD both-edge
 * handler in main.c (FD falling -> low, FD rising -> release). Open-drain because EN_STO_CH is
 * 2.75 V-max while the MCU rail is 3.3 V. */
#define ENSTOCH_PORT    PORTA
#define ENSTOCH_PIN_bm  PIN4_bm
```

**Re-scale, do not add:** the existing glow gates (`VS_GLOW_FLOOR_MV`, `VS_GLOW_FULL_MV`,
`SWEEP_CAPS_FULL_MV`, `EE_WRITE_FLOOR_MV`, `VS_GLOW_DIM_PEAK`) are now read against STO's 0.2..4.65 V range
instead of the old clamped 2.6..3.5 V rail (the sense.c re-point makes `sense_vdd_mv()` return STO).
Bench-tune the values; no new symbols needed.

The two table lines + the #defines are in board.h and the matching `STO_SNS` / `EN_STO_CH` net names are in
the schematic, landed in one commit, and `check_consistency.py` passes.

## 8. Firmware re-point (applied; was `v4-aem10300-firmware.patch`)

Companion to the board.h edits above -- the sense/gate code the new rail topology needs. **Applied:** it
references board.h's `STO_SNS_AIN` / `STO_DIVIDER` / `ENSTOCH_*` defines, which are now in-tree, so it
compiles; it landed in the **same commit** as the board.h edits + reworked board/schematic. The
`v4-aem10300-firmware.patch` / `v4-aem10300-boardh.patch` files were historical and **were deleted 2026-07-25** (they were applied long ago, and their content had since been superseded twice — PA4 is now the Q2 gate). They remain in git history if ever needed.

What it changes:
- **`sense.c` (7 hunks):** re-points `sense_vdd_mv()` and the four rail gates (`sense_rail_ok`,
  `sense_caps_full`, `sense_ee_safe`, and `sense_glow_peak` via `sense_vdd_mv`) from the internal **VDD/10**
  channel to the **STO divider on PD1/AIN1** (`STO_SNS_AIN`), scaling by `STO_DIVIDER` (x3) -- the same
  divider-pin form `sense_vin_mv()` already uses. The compile-time count macros (`RAIL_COUNT`,
  `CAPS_FULL_COUNT`, `EE_SAFE_COUNT`) are re-folded for the STO/3 channel (like `SUN_COUNT`), dropping the
  old VDD/10 10-mV-quantization intermediates.
- **`main.c` (3 hunks):** PD1 pull-up -> `PORT_ISC_INPUT_DISABLE_gc` (analog input); PA4 spare pull-up ->
  the **EN_STO_CH open-drain gate** (OUT latch LOW, DIR toggled -- Hi-Z = charge on via R17 -> VINT, driven
  LOW = charge off; never driven HIGH into the 2.75 V-max pin); and the FD ISR (`PORTA_PORT_vect`) drives it
  -- LOW on the falling edge (field present, silence the >=10 MHz DCDC for the read), released on the rising
  edge.

Verified (no AVR toolchain here -- CI does the real cross-compile at apply time): `git apply --check` clean,
brace/paren balanced, and the re-folded count macros are in-range and monotonic across STO's 0.2-4.65 V span
(VS_GLOW_FLOOR 2600 -> 1420, EE_WRITE_FLOOR 2700 -> 1475, SWEEP_CAPS_FULL 3300 -> 1803; max STO count ~2540,
all < 4096, no saturation).

**Bench-tune after wiring:** the threshold *values* (`VS_GLOW_FLOOR_MV`, `VS_GLOW_FULL_MV`,
`SWEEP_CAPS_FULL_MV`, `EE_WRITE_FLOOR_MV`, `VS_GLOW_DIM_PEAK`) are still the v3 clamped-rail numbers; they now
act on STO's wider 0.2-4.65 V range and want re-tuning (e.g. caps-full nearer VOVCH 4.65 V, not 3.3 V).
Cosmetic follow-up not in the patch: a few residual "VDD/10" mentions in `sense.h` and `sense_glow_peak`.

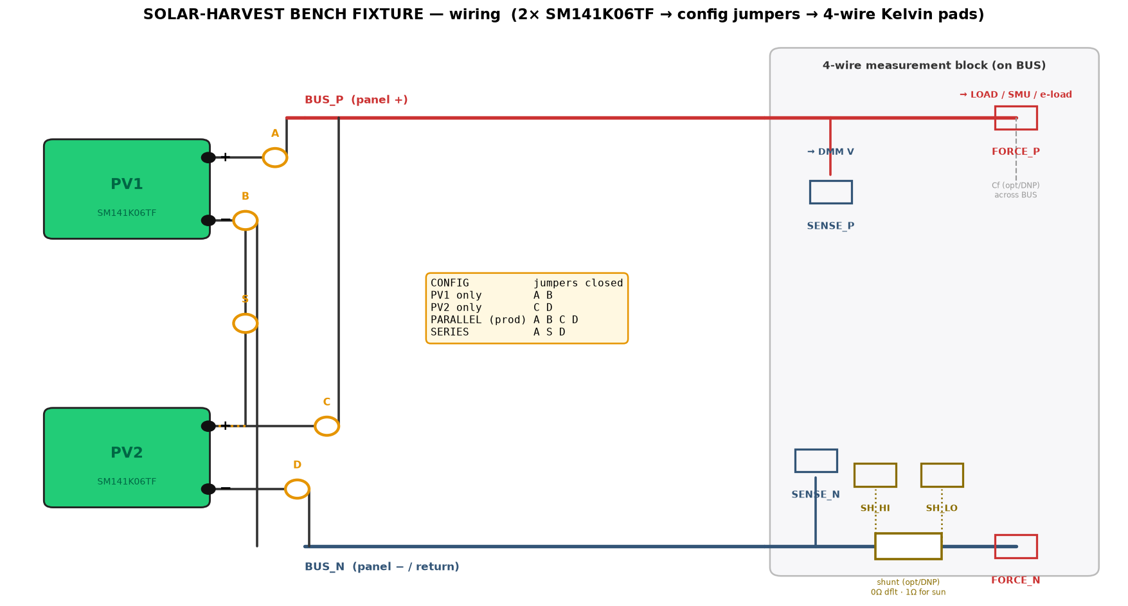
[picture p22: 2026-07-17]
images/bench-fixture-wiring.png

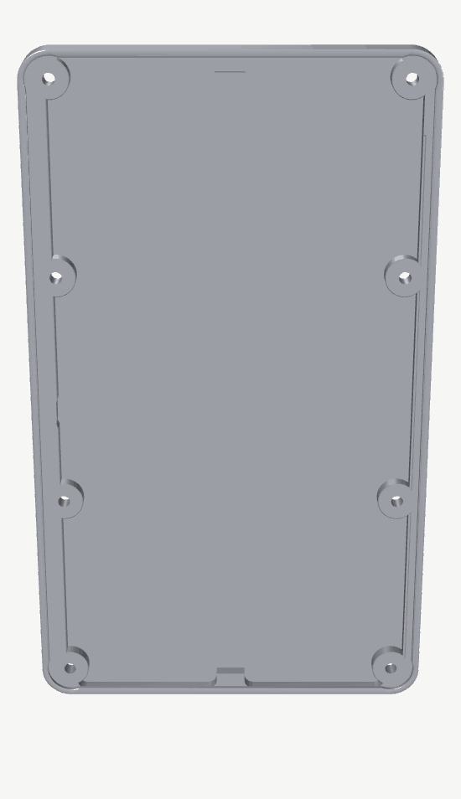
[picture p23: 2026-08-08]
enclosure/solar-glow-drh-assembly-shell-spin.gif

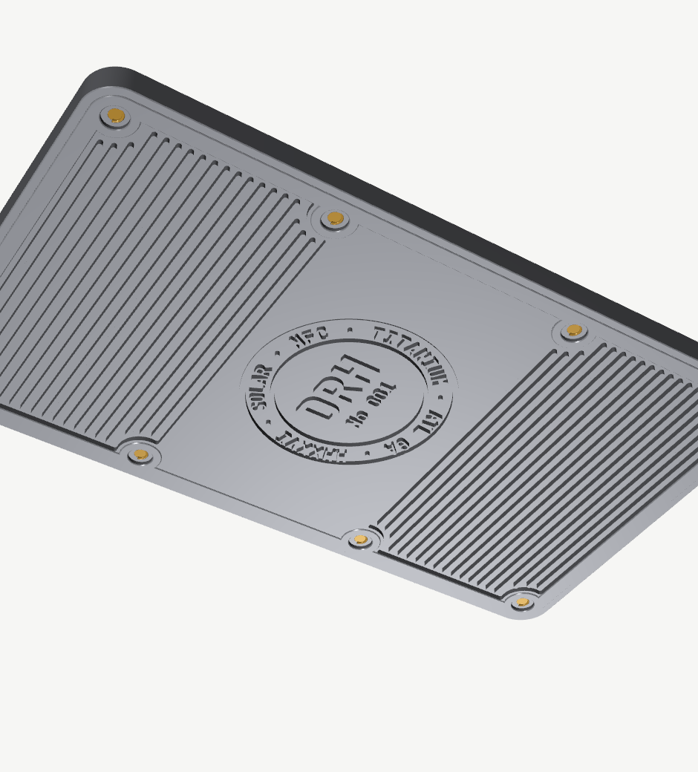
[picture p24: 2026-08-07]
enclosure/solar-glow-drh-assembly-reverse.png

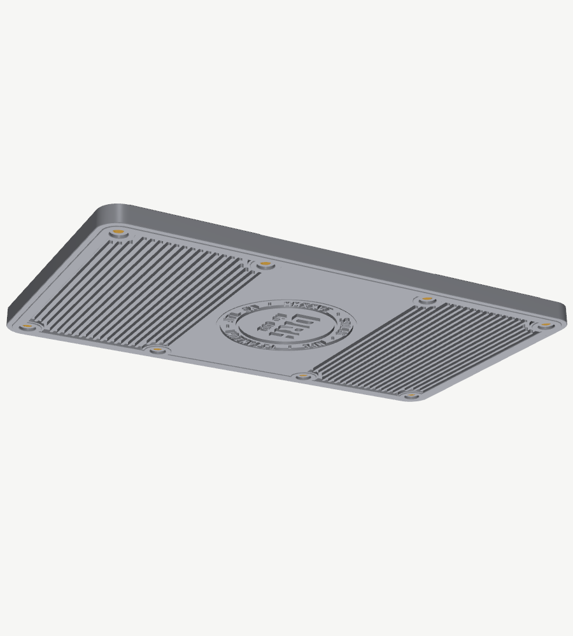
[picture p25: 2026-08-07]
enclosure/solar-glow-drh-assembly-hero.png

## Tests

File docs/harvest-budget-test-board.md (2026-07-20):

# Harvest-budget test board -- design handoff

**Status: design spec / handoff -- not yet laid out.** A small, single-sided PCB that answers
one question at a glance, with no instrument: *at this light, can the two SOLAR-GLOW panels
out-harvest the card's own draw?* It carries the two product panels, top-side probe pads, and
a **self-powered "harvest surplus" blink indicator** whose flash rate is proportional to the
net power the panels bank *over a jumper-selected load that emulates the card's consumption*.

This is the **live-harvest / budget** companion to `harvest-bench-fixture-handoff.md`. That
board is the precise instrument (4-wire panel I-V curve, needs an SMU/DMM); **this** board is
the glanceable go/no-go you leave on the desk. Use them together: characterize V<sub>mp</sub>
with the fixture, then set this board's window around it (section 5).

---

## 1. What it is / is not

- **Is:** 2 panels (parallel = the product's SRC node), a passive reverse-blocking diode into a
  small storage cap, a nanopower relaxation blinker, a **jumper-selected calibration load**, and
  top-side probe pads. Reads out **as a blink rate** (qualitative, glanceable) **and** as a
  scope-able ramp on one pad (quantitative, no series break).
- **Is not:** the product front-end. It deliberately omits the AEM10300 so it stays simple and
  self-powered. That makes it a **conservative proxy**: it parks the panels at V<sub>CAP</sub>
  (~2.2-3.0 V), *below* the MPP the AEM would hold, so it under-reads what the real card
  harvests. **If this board says net-positive, the AEM-boosted card comfortably is** (MPPT gain
  1.3-2.2x, per the fixture doc). For the exact card number, use the fixture's SMU sweep or a
  future AEM-in-the-loop board.

---

## 2. Panels -- same as the product

2x **ANYSOLAR SM141K06TF** (PV1, PV2), wired **parallel** into SRC (the product config; the v3
per-panel blocking diodes are gone). Reuse `solarglow:PV1` / `solarglow:PV2` from
`PCB/solar-glow-drh-v4_0.kicad_pcb` -- do not re-derive the land. Datasheet anchors (1 sun):
Voc 4.15 V, Isc 58.6 mA, V<sub>mp</sub> 3.35 V, I<sub>mp</sub> 55.1 mA, P<sub>max</sub> 184 mW;
indoors these scale ~with lux (desk ~400 lux ~= 0.4 % sun -> ~0.5-1 mW per panel, ~1-2 mW the
pair). **Manual solder only, <= 260 C / 2 s, no reflow** (moisture-sensitive laminate).

---

## 3. How the indicator works

```
 PV1 ||                      D1 (Schottky, reverse block)
 PV2  +----[SRC]----o SRC+----|>|----o VCAP ---+------+-------------+
      |             (probe)          (probe)   |      |             |
     GND                                     C_store  R_load       comparator relaxation
      |                                        |     (jumper       (TLV3691 nanopower) +
      +----------------------------------------+------ bank)------- LED flash + hysteresis
                                               |      |             |
                                              GND    GND           GND
```

- **D1** blocks the cap from back-feeding the panels in the dark (the AEM does this actively in
  the product; a passive board needs the diode). Use a low-V<sub>f</sub> Schottky (e.g. BAT54,
  or the MMSD301 land the card retired).
- **C_store** is the mini "tank." The panels charge it; the blinker dumps a fixed energy quantum
  out of it through the **LED** each time it reaches the upper threshold, then it recharges.
- **The comparator** (nanopower, ~0.15 uA -- e.g. TI **TLV3691**) plus a hysteresis divider make
  a relaxation oscillator on V<sub>CAP</sub>: charge to **V<sub>hi</sub>**, flash + discharge to
  **V<sub>lo</sub>**, repeat. Defaults **V<sub>hi</sub> ~= 3.0 V, V<sub>lo</sub> ~= 2.2 V** --
  chosen to (a) straddle the likely indoor V<sub>mp</sub> so the panels sit near their MPP, and
  (b) stay above the LED forward drop. Retune the divider once the fixture board measures the
  real indoor V<sub>mp</sub>.
- **R_load** (the jumper bank, section 5) sinks a current that **emulates the card's average
  draw**. The blinker only advances when **harvest > R_load**, so *the LED blinking at all means
  the panels are net-positive at that usage level*, and the **rate is the surplus**.

**Blink-rate law (this is the calibration):**
> f_blink = P_net / E_flash,  where  E_flash = 1/2 * C_store * (V<sub>hi</sub>^2 - V<sub>lo</sub>^2)
> and P_net = P_harvest - P_load - P_quiescent.

With **C_store = 1000 uF**, V<sub>hi</sub> 3.0 / V<sub>lo</sub> 2.2 V -> **E_flash ~= 2.1 mJ**:

| Blink rate | Net surplus over the selected load |
|---|---|
| 1 / sec | ~2.1 mW |
| 1 / 10 sec | ~210 uW |
| 1 / min | ~35 uW |
| (no blink, cap stuck low) | harvest < selected load at this light |

Silk-screen that table. Bigger C_store = slower, "chunkier" blinks (more energy per flash);
drop to ~220 uF for livelier blinks in dim light. A small 0.1 F EDLC also works (very slow,
very visible pulses).

---

## 4. Reading it (bench use)

1. Set the panel angle/distance to your real use case; note the lux (phone app is fine) and
   panel temperature (Voc tempco -10.4 mV/K).
2. **Pick the load jumper = the usage you care about** (idle vs light vs active glow, section 5).
3. **Watch the LED:**
   - **Blinking** -> panels are net-positive at that usage; **count the rate -> surplus power**
     from the table. Faster = more margin.
   - **Dark (cap never reaches threshold)** -> harvest is below that usage level here; step the
     load jumper down (to idle) to find where it *does* go net-positive.
4. **For a number, don't break the circuit:** scope the **VCAP** pad. The charging ramp's slope
   gives **I_net = C_store * dV/dt** directly (net harvest current into the cap), and the flash
   interval gives P_net independently -- two cross-checks, no series ammeter.
5. Sanity anchor: at a desk you should see blinks with the idle load and slower/none as you step
   to the active-glow load. In a dim room, expect idle to still blink slowly and light-use to
   stop -- that boundary is the actual answer to the open gate.

---

## 5. Calibration to the card's usage (the load bank)

R_load is a **jumper- or DIP-selected resistor to GND**, sized so its current at the mean
V<sub>CAP</sub> (~2.6 V) equals a card operating average. Representative set (retune to taste):

| Jumper | Emulates | Card avg current | R (@ ~2.6 V) | Meaning if it blinks |
|---|---|---|---|---|
| **OFF** | nothing (raw harvest) | 0 | open | pure panel-into-cap rate; "is there any harvest?" |
| **IDLE** | standing (accel + MCU sleep + poll) | ~2.7 uA (~9 uW) | **~1.0 M** | the card survives here doing nothing |
| **LIGHT** | idle + a few glows/day, averaged | ~30 uA (~90 uW) | **~82 k** | sustains light interactive use |
| **ACTIVE** | frequent glowing | ~300 uA (~0.9 mW) | **~8.2 k** | sustains heavy use |

Notes:
- These currents come from the card's power model (idle ~2.7 uA standing; a breath is ~15-30 mA
  for a few seconds, so the *average* is dominated by how often it glows). Print the assumptions
  on the silk so the load meanings are unambiguous.
- A resistor is a fixed conductance, not a fixed current, so its draw sags a little as
  V<sub>CAP</sub> ramps -- fine for a go/no-go. If you want a true constant-current emulation of
  the card, populate a 2-transistor current sink or a JFET+R in the R_load land instead (DNP
  option).
- **The load bank IS the "calibrated to our setup" part.** Swapping the jumper reframes the
  blink from "is there sun" to "can it run the card *at this duty*."

---

## 6. Probe pads (top side, sized for mini-grabbers)

| Pad | Node | Use |
|---|---|---|
| **SRC+ / GND** | panel output | panel terminal V; DMM Voc with load off |
| **I_SRC** | series break in the SRC leg | open the jumper, insert a uA DMM in series for direct harvest current |
| **VCAP** | storage cap top | scope the ramp (slope = net harvest current) + flash pulses |
| **VLO/VHI** | comparator threshold divider taps | verify/tune the window with a DMM |
| **PV1+/-, PV2+/-** | each panel | per-panel Voc / shading checks, 2-instrument reads |

Keep a **SENSE pair** at the panel lands (Kelvin) if you also want clean 4-wire panel voltage
under load, same as the fixture board.

---

## 7. Bill of materials (minimal, all top-side)

| Ref | Part | Qty | Note |
|---|---|---|---|
| PV1, PV2 | ANYSOLAR SM141K06TF | 2 | reuse `solarglow:PV*`; manual solder, no reflow |
| D1 | Schottky, low Vf (BAT54 / MMSD301) | 1 | reverse block into the cap |
| C_store | 1000 uF (or 220 uF livelier / 0.1 F EDLC slow) | 1 | sets blink energy quantum |
| U1 | TLV3691 nanopower comparator (or equiv.) | 1 | 0.15 uA; the relaxation oscillator |
| LED1 | red/amber high-efficiency LED | 1 | the flash; low Vf so it fires below Vhi |
| R_hys, R_div | comparator hysteresis + threshold divider | ~3-4 | set Vhi/Vlo (~10 M scale to stay sub-uA) |
| R_led | LED series limit | 1 | ~100-330 ohm, sets flash brightness/energy |
| R_load bank | IDLE/LIGHT/ACTIVE resistors + jumpers | 3 + 4 | calibration loads (section 5); DNP current-sink option |
| A/B config + I_SRC | 2-pin headers / solder jumpers | ~3 | parallel-only needed; keep the series break |
| pads / TPs | plated probe pads | ~10 | 2.0-2.5 mm |
| H1-H4 | mounting holes | 4 | stand it at a repeatable angle |

Optional DNP: a 1 uF film across SRC to average 100/120 Hz room-light flicker for a steady mean.

---

## 8. Layout (single-sided)

- **All assembly + all pads on top; back is routing/vias only** (flat for handling, faces up to
  the light) -- same rule as the fixture board.
- **Outline:** reuse SOLAR-GLOW **50.8 x 88.9 mm** Edge.Cuts so it feels like the product (free
  to shrink; the two 42 x 23 mm panels are the size floor).
- **Floorplan (portrait):** PV1 top, PV2 below (both faces up, centered); bottom strip = the
  indicator cluster (D1, C_store, U1, LED where you'll actually see it) + the load-jumper row +
  the probe-pad field. Put **LED1 near the top edge** so it's visible with the board flat on a
  desk.
- **Silk earns its keep:** the blink-rate table (section 3), the load-jumper legend (section 5),
  and the datasheet anchors (Voc 4.15 / V<sub>mp</sub> 3.35 / Isc 58.6 mA @ 1 sun).

---

## 9. Two indicator tiers (pick one)

- **Tier 1 -- dead simple (~2 parts).** One high-efficiency LED across V<sub>CAP</sub> through a
  large series R: glows when the panels produce, brighter in more light. Zero calibration, but it
  loads the panel and only says "there is light," not "enough for the card." Good as a first cut.
- **Tier 2 -- calibrated (recommended, this doc).** The blink-rate relaxation + load bank above:
  self-powered, rate = surplus, jumper = usage. ~8 parts, still single-sided and simple.

---

## 10. Open choices for you

- **C_store value / type** -- ceramic-tantalum 1000 uF (default), 220 uF (livelier), or a 0.1 F
  EDLC (slow, dramatic pulses). Sets the blink cadence.
- **R_load: resistor (simple) vs a 2-transistor constant-current sink (faithful).** Resistor is
  fine for go/no-go; the sink better mimics the card's flat current draw.
- **Config jumpers** -- parallel is the only product-relevant case, so you can hard-wire PV1||PV2
  and keep just the I_SRC series break + the load bank, or keep the fixture board's full A/B/C/D/S
  set if you want singles/series too.
- **Take it to KiCad:** the capture-ready schematic is **Appendix A** below -- component table,
  full net list, and the threshold math. Capture it as-is; the two analog thresholds want a
  quick LTspice/bench tune (A.4), so treat the resistor values as starting points.

---

## Appendix A -- Schematic (capture-ready)

The Tier-2 (calibrated blink-rate) circuit. This is a **passive solar front-end + a nanopower
voltage-trigger blinker** (the classic "solar-engine" pattern): the panels trickle-charge
C_store; when it reaches V<sub>hi</sub> the trigger flashes the LED and dumps the cap to
V<sub>lo</sub>; it recharges; repeat. Blink rate = net surplus power (section 3).

**Delivered as a capture spec, not a raw `.kicad_sch`, on purpose:** there is no `kicad-cli`
in this environment to ERC-validate a generated file, and the repo's symbol library is
per-refdes custom (no LED / MOSFET / comparator symbols) -- so a hand-built binary would be a
liability, not a head start. The net list below captures cleanly in ~20 min and is unambiguous.

### A.1 Signal flow

`PV1||PV2 -> SRC -> [I_SRC break] -> D1 -> VCAP( C_store )` and off VCAP hang three things:
the **trigger** (U1 divider R1/R2 -> V<sub>REF</sub>, compared to U1's internal 1.182 V), the
**flash path** (R_led -> LED1 -> Q1 to GND, Q1 gated by the trigger output), and the
**calibration load bank** (R_idle / R_light / R_active, each jumper-selected to GND).

### A.2 Components

| Ref | Value | KiCad symbol | Footprint | Note |
|---|---|---|---|---|
| PV1, PV2 | SM141K06TF | `solarglow:PV1` / `PV2` (reuse) | `solarglow:PV1` / `PV2` | panels ||, = product SRC |
| D1 | BAT54 (Schottky) | `Device:D_Schottky` | SOT-23 / SOD-323 (or reuse `solarglow:D2` land) | reverse block into cap |
| C1 | 1000 uF (C_store) | `Device:C_Polarized` | tantalum/elec, or 0.1 F EDLC | blink energy quantum |
| U1 | MAX931 (nanopower comp + 1.182 V ref + hysteresis) | `Comparator:MAX931` (or LTC1540) | SOIC-8 / uMAX-8 | **confirm pinout at capture** |
| Q1 | 2N7002 (N-MOSFET) | `Device:Q_NMOS_GSD` | SOT-23 | flash / discharge switch |
| LED1 | red/amber, high-eff | `Device:LED` | 0805 | the indicator |
| R1 | 6.8 M | `Device:R` | 0402 | divider top (VCAP->VREF) |
| R2 | 4.7 M | `Device:R` | 0402 | divider bottom (VREF->GND) |
| R3 | 10 M | `Device:R` | 0402 | hysteresis (OUT->VREF) |
| R_led | 220 ohm | `Device:R` | 0402 | flash current limit |
| R_idle / R_light / R_active | 1.0 M / 82 k / 8.2 k | `Device:R` | 0402 | calibration loads (section 5) |
| JP1-3 | load select | solder-jumper / 2-pin | -- | one-per-load to GND |
| J_SRC | series I break | 2-pin header | -- | insert uA DMM; default closed |
| TP1-6 | SRC / VCAP / VREF / COMP / GND / panel taps | test point | 2.0-2.5 mm pad | probe |
| PWR1-3 | on SRC, VCAP, GND | `solarglow:PWR_FLAG` (reuse) | -- | ERC (no driven power pin) |
| H1-4 | mounting | `solarglow:MH*` | M2 | stand at a fixed angle |

### A.3 Net list (net : pins)

```
SRC     : PV1.+  PV2.+  J_SRC.1  TP1  PWR1
VIND    : J_SRC.2  D1.A                       (= SRC if J_SRC closed / omitted)
VCAP    : D1.K  C1.+  U1.V+  R1.1  R_led.1  R_idle.1  R_light.1  R_active.1  TP2  PWR2
VREF    : U1.IN+  R1.2  R2.1  R3.2  TP3
UREF    : U1.REF  U1.IN-                       (internal 1.182 V ref tied to IN-)
COMP    : U1.OUT  R3.1  Q1.G  TP4
LED_A   : R_led.2  LED1.A
LED_K   : LED1.K  Q1.D
GND     : PV1.-  PV2.-  C1.-  U1.V-  U1.GND  R2.2  Q1.S  JP1.2  JP2.2  JP3.2  TP5  PWR3
(load bank: R_idle.2->JP1.1, R_light.2->JP2.1, R_active.2->JP3.1; close one jumper)
```

### A.4 Threshold design (the two numbers to tune)

U1 trips when its divider node hits the internal reference: **V<sub>hi</sub> = 1.182 * (1 +
R1/R2)**. With R1 6.8 M / R2 4.7 M -> **V<sub>hi</sub> ~= 2.9 V** (sits near the indoor MPP and
above the LED V<sub>f</sub>). Hysteresis from R3 (OUT->VREF): **ΔV ~= V<sub>hi</sub> * (R1||R2) /
R3**; with R3 10 M -> **ΔV ~= 0.8 V, so V<sub>lo</sub> ~= 2.1 V**. Flash quantum **E =
1/2*C1*(V<sub>hi</sub>^2 - V<sub>lo</sub>^2) ~= 2.0 mJ** at 1000 uF -> the section-3 rate table.

Tune once: (1) re-center V<sub>hi</sub>/V<sub>lo</sub> on the **real indoor V<sub>mp</sub>** the
`harvest-bench-fixture` measures; (2) pick C1 for a comfortable blink cadence (bigger = slower).
Keep the divider in the 5-20 M range so it draws < ~0.5 uA (well under the IDLE load it must not
swamp).

### A.5 ERC / capture notes

- **Passive board, no driven power net** -> KiCad ERC needs a `PWR_FLAG` on SRC, VCAP, and GND
  (reuse `solarglow:PWR_FLAG`), else "input power pin not driven" errors.
- **U1** is the only part whose exact pin numbers I have not pinned to a datasheet here (proxy
  blocked it) -- capture from the KiCad `MAX931` symbol's named pins (V+, GND, IN+, IN-, REF,
  HYST, OUT) and confirm against the datasheet; wire IN- to REF for the internal-reference
  configuration. (If you prefer, `LTC1540` is a drop-in-equivalent nanopower comp+ref.)
- **Q1** body diode points cap->GND; fine (LED_K is always >= GND). No flyback concern (resistive
  LED load).
- No-connects: U1 HYST pin may be left open if you use the external R3 hysteresis shown (or tie
  per the datasheet if you use the internal HYST resistor instead -- pick one path).
- Single-sided: all of the above on top; back is copper/vias only (section 8).

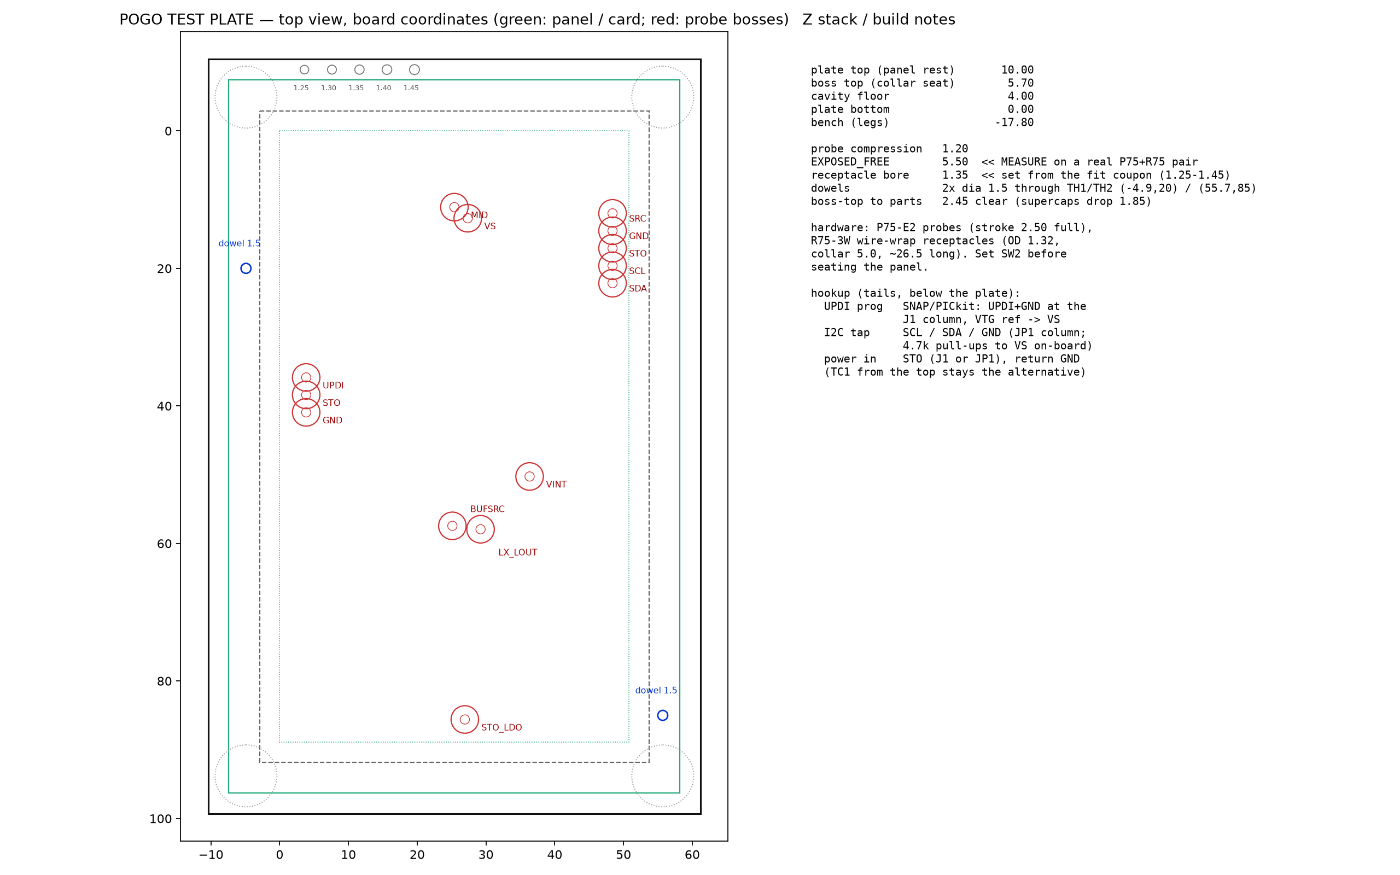
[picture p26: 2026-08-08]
enclosure/solar-glow-drh-pogo-testplate-DRAWING.png

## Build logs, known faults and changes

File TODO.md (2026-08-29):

# Open items — SOLAR-GLOW DRH

A cross-domain tracker so nothing slips between the firmware, PCB, and enclosure
handoffs. This is an **index of what is left**, not a spec — canonical values
live in the source files it points to (see the "Where the truth lives" table in
`README.md`). Check items off in the GitHub UI as they land; **completed items are
culled** — the record lives in git history + the `solar-glow-drh-design-notes.md`
addenda.

_Board freeze status (updated 2026-07-25): the 2026-07 audit round reopened the
netlist and it is now closing again — Q2/R18 (the cold-start-deadlock buffer) and
the FRAM VS re-rail are placed, routed, and verified on the board; the U7
footprint-identity swap and DNP clear have since landed too (2026-07-26). A PCB layout change still means
a brace reprint, not a shell re-machine._

_Purged 2026-08-09: 18 completed `[x]` items culled (the file's own policy — the record is in git
history and the design-notes addenda); the panel `check_zone_fills` fab hazard culled because it was
FIXED the same day (`PCB/solar-glow-drh-panel.kibot.yaml` now carries the preflight); and two
"decided, do not re-derive" reference items (U6 alternatives, C26/C27 thinning) moved to Locked,
where verdicts of that shape belong. 1,116 → 636 lines. What survives is almost entirely
bench-gated: it needs the first article, a light meter, or a scope._

_Purged 2026-07-30 (see the design-notes addendum "TODO purge, 2026-07-30" + git history):
29 completed items culled; 20 open items verified already-resolved against the current board/repo
and culled; 4 declined (cosmetic lib_ids, stencil/copper cosmetics, teardrop completeness — covered
by the README pre-order step, C13's lib_id); the accepted copper trade-offs moved to Locked._

_Completed & culled 2026-07-25 (see git history + design-notes addenda for the
full reasoning): the AVR64DD28→AVR64EA28 family swap + firmware port; the U5 NFC
and U6 load-switch (→TPS22917) silicon audits; the U7 FRAM DFN-repackage and the
VS-rail back-power fix (schematic + firmware + board all landed — the FRAM
bench-verify is still open, see the items above); the Q2/R18 cold-start-deadlock buffer (schematic + firmware + board); the
passive longevity/precision upgrades (X7R / AEC-Q200, 0603 & 0805 upsizes,
thin-film dividers); the full live DigiKey/Mouser BOM sourcing pass; the
SUN-threshold derivation and the solar-cell-thickness resolution; and the
STO_LDO island / led_sweep / MPN-grouped-BOM work._

## Cross-domain (link two+ teams — easiest to forget)

- [ ] **[BOM] Buy the low-stock / long-lead parts early** _(2026-07-23; numbers refreshed 2026-07-30
  from a live DUAL-distributor sweep of all 31 orderable MPNs — DigiKey and Mouser, exact-MPN matched.)_
  - **U3 accel `ADXL367BCCZ-RL7` — the new alarm: DigiKey went 731 → 0 in seven days.** Mouser holds
    2,601 ($7.80). The card's only actuator is now single-distributor. Buy from Mouser, early.
  - **THE SUPERCAPS ARE TWO DIFFERENT PARTS, 2 + 2 — NOT four of one.** _(Called out 2026-08-02;
    now printed on every consistency run and gated by check [15].)_
    **SC1, SC3 = SS17 1.8 F 2.75 V = `3-153-440`** (DigiKey `486-3-153-440-ND`) and
    **SC2, SC4 = WS17 1 F 2.75 V = `3-153-438`** (DigiKey `486-3-153-438-ND`). Two MPNs, two
    separate stock pools, two of each per board — ordering 4× either one builds nothing.
    Board and schematic have always agreed on this; what invites the mistake is that
    `datasheets/` holds exactly one supercap PDF and its filename reads
    **`SC1-SC4  SCHURTER 3-153-438`**, i.e. the wrong belief written down, with no datasheet
    on file for `3-153-440` at all. (`BOM/README`'s generated table is correct — it maps that
    PDF to SC2, SC4 by MPN, not by the filename.) Fix the filename and fetch the missing
    datasheet at order time; do not let the folder be the source.
  - **Supercaps are the global chokepoint:** SS17 ≈ 400 and WS17 ≈ 393 **combined across both
    distributors** — at 2/board, ~200 boards of world-visible stock per type. SS17 is $0.66 cheaper
    at Mouser. Order with the first cut, from both carts if batching.
  - **Nothing in the fab package buys the hand-soldered parts.** SC1–4 and PV1–2 are excluded
    from the assembly BOM *and* (since 2026-08-02) from the CPL — correct, they are hand-soldered
    — which means **no fab file orders them**. `BOM/README`'s table is the only document that
    does, so check [15] now holds it against the board and prints the buy list every run:
    `3-153-438 ×2 (SC2, SC4); 3-153-440 ×2 (SC1, SC3); SM141K06TF ×2 (PV1, PV2)`.
  - **FER1 was a false scarcity:** the "41 in stock, 24-week lead" figure was DigiKey's; **Mouser has
    119 at $13.18 vs DK's $17.43**. Buy there.
  - **U1 MCU recovered:** DK 608 → 1,365 (Mouser only 269 — buy DK). **PV cells** 423, DK-only
    (Mouser doesn't list ANYSOLAR). **C11** (mandatory ADXL VREG cap) ~5.1 k combined — fine, order
    with build.
  - **A single-distributor order is impossible:** DK-only = PV, LEDs (`LA P47F`, 11.3 k), U7 FRAM
    `…AWEWE1` (1.5 k), R10/R11, C22. Mouser-only = U3, U8 AEM10300 (553, listed as `AEM10300-QFN`),
    C26/C27 Samsung, PRG1 UPDI Friend (56). Split is forced; assign by depth.
  - **CBL1 trap:** DigiKey's in-stock Tag-Connect item is `TC2030-MCP-NL` (no legs); the legged
    `TC2030-MCP` the BOM specifies is Restricted/zero at Mouser — check Tag-Connect direct at order.
  - Also grab a **spare NT3H2211 or two**: NXP steers new designs to NTAG 5, so NTAG I²C plus carries
    EOL risk on a years horizon (the U5 NFC audit kept it as best-fit, but flagged this).
  - _LCSC pending as a third source (API hookup TBD). Expectation to verify: strong on the Yageo /
    Samsung / TDK passives, useless for the actual chokepoints (SCHURTER, ANYSOLAR, e-peas, RAMXEED,
    Würth FSFS, likely ADXL367)._

- [ ] **[BENCH/PCB — TABLED 2026-08-02 until the hero project ships] Two designed-but-never-laid-out
  test boards — the instrument and the go/no-go**
  _(Piped into TODO 2026-08-02; tabled the same day: they do NOT ride the card's fab order.)_
  They can be made cheaper at OSH Park, thicker (1.6 mm, no reason to share the card's exotic
  0.6), and they need no assembly service — both are hand-solderable. Deliberately decoupled so
  nothing about them gates the hero order. (a) `docs/harvest-bench-fixture-handoff.md` — the
  **panel characterization fixture** (single-sided, no MCU: 4-wire panel I-V under real light,
  needs an SMU/DMM); the authoritative tables are in the doc, it just needs KiCad layout. (b)
  `docs/harvest-budget-test-board.md` — the **harvest-surplus blinker** (carries two product
  panels + a jumper-selected card-draw emulation load; flash rate ∝ net banked power — the
  glanceable desk answer to "can this light run the card?"). Sequence when picked up: fixture
  first (characterize V_mp), then set the blinker's window from it (its §5).

- [ ] **[BENCH/CROSS-DOMAIN — first-article gate] Measure NFC read range, in the shell**
  _(2026-08-09. Added when the U5 VOUT decline was Locked and its reopen condition turned out to
  name a number nobody was scheduled to produce. Searching the tracker for "read range" returned
  the Locked entry and nothing else.)_
  The card's contact story is Locked as **offline-first**: the vCard is embedded in the tag and read
  RF-powered with the supercap flat. That premise assumes a 13.56 MHz link that survives a ferrite
  sheet and a **titanium** back shell, and no one has put a number on it. It is the second-riskiest
  physics on the card after the energy budget, and unlike the energy budget it has no entry.
  Measure, at bring-up, with the brace removable (already Locked as a requirement) and the C9 ladder
  in play:
  - **Baseline sweep:** bare board, then + ferrite, then + shell — max / lite / **air** (the air frame
    is 316L specifically for the coil; this is the run that shows whether that choice paid).
  - Report **millimetres of read distance** per configuration against 2–3 real phones, plus the
    resonance the coil actually lands on. `scripts/nfc_coil.py --check` gives bare-copper L and a
    predicted f0; the ferrite raises L ~1.3–1.5×. **The bench owns the real number** — this is the
    measurement that closes that gap.
  - Record the margin, not just pass/fail. Margin is what every future range-costing decision gets
    judged against, and right now there is nothing to judge against.

  **Gates:** the Locked `U5` VOUT decline reopens only on a margin figure from this; the C9 trim
  value; and whether the air variant earns its existence.

- [ ] **[BENCH — first-article gate] Sweep the LED's I-V curve, and the loop current in situ**
  _(2026-08-20. Added after an ASIC-side analysis published a wrong finding off the back of the
  gap: `asic/analog/README.md` briefly claimed a worst-bin LED cannot light at the 2.75 V glow
  floor. It was the 30 mA Vf applied at 0.67 mA. Retracted — but the retraction only says the
  low rail is UNMODELLED, and nothing in the tree can model it.)_
  **The whole repo has exactly one Vf datum: `1.95-2.55 V at 30 mA`** (unbinned 3B-5A,
  `PCB/README.md`). Every current figure the card and the ASIC compute leans on it, and most of
  them lean on it far from 30 mA. `asic/analog/sink_budget.py` now prints each row's distance
  from that spec point, and the glow-floor row is **0.11x — not usable**. This is the
  measurement that makes the bottom of the operating range real.

  **(a) The part, on a breakout — the curve itself.** Sweep If from **~10 uA to 30 mA** (3.5
  decades; the same wide-dynamic-range problem `docs/harvest-bench-fixture-handoff.md` §2 calls
  out for the panel) and record Vf at each point, at room temperature. **Sample several parts**:
  the LA P47F is shipped UNBINNED across 3B-5A, so bin spread — not measurement error — is the
  dominant uncertainty, and one part tells you almost nothing about the corner.

  **(b) The loop, on a real card — what the energy budget actually needs.** With SW2 on, sweep
  STO from the **2.75 V glow floor to the 4.65 V VOVCH ceiling** and record per-LED current at
  100 % duty. That folds in the ballast, the sink drop and Vf together, which is the number the
  budget wants; the part curve in (a) is what lets you attribute a surprise to the right term.

  **What it settles, each of which is currently an assumption:**
  - **The low-rail end.** Does a max-Vf part conduct at 2.75 V, and how brightly? `board.h`'s
    `VS_GLOW_FLOOR_MV` was chosen without this, and if the answer is "barely", the floor is
    mis-set for part of the bin distribution. **This converges with the
    `VS_GLOW_FLOOR_MV` vs STO-channel accuracy item below**, which reaches the same
    constant from the opposite side — sense tolerance, not LED physics — and lands on a floor
    near **2900 mV**. Two independent arguments pointing the same way; take both
    measurements before moving the constant once.
  - **`VF_GUARD` = 1.90 V.** F1's clamp margin (`GLOW_CLAMP_PEAK` 221) rests on it, and 1.90 is
    *below* the 1.95 V datasheet floor **at 30 mA**. It is plausibly right at 22 mA because Vf
    falls with current — i.e. the margin currently holds by two errors cancelling, not by
    derivation. **Do not "correct" 1.90 to 1.95 without this curve**: that lowers the computed
    current and makes the clamp look safer than it is.
  - **The published "~16 mA".** `README.md`'s "The open question" computes it as
    `(4.65 - 2.25)/150` — **no sink drop at all**. With the AVR's ~0.4 V VOL the same loop gives
    **13.3 mA**. Both numbers are in the tree; the sweep says which one the budget should use.
  - **Whether 150 ohm is right.** `PCB/README.md` flags R1-R4 as **SIZED, not locked** and
    bench-pending. A re-tune moves the corner `sink_budget.py` gates the clamp against — the
    guard will go red rather than drift, but only this measurement tells you where to move it.

  **Where the results land:** `PCB/README.md`'s Vf row (add the low-current points and the spec
  condition), `asic/analog/sink_budget.py`'s `VF_*` constants and its MODEL VALIDITY note, and
  the envelope table's "not usable" row — which should stop saying that.

  **Gates:** the #1 energy-budget item's draw side; F1's margin; the retracted F2; and any
  future re-tune of the 150 ohm ballast.

- [ ] **[BENCH — first-article gate] Find the system's true low-rail floor, and set TH_CRIT from it**
  _(2026-08-20. `asic/rtl/sense_seq.v`'s `TH_CRIT_MV` = 2000 is the one threshold in that module
  with **no firmware anchor** — the card has no second rail gate — so it was sourced to the
  AEM10300 selection analysis's "drain to ~2 V at the load". That is a statement about what the
  HARVESTER can deliver, not about what THIS LOAD can still run on, and those are different
  questions.)_

  **It is an energy-budget claim in disguise, and the arithmetic is not small.** On the real tank
  (2S2P, **1.40 F**, 15.14 J at the 4.65 V VOVCH ceiling):

  | spend down to | stored left | spendable |
  |---|---|---|
  | 2.75 V — the card's glow floor | 5.29 J | **9.84 J** (README's "9.8 J spendable") |
  | 2.60 V — the AVR's BOD | 4.73 J | 10.40 J |
  | 2.00 V — `TH_CRIT` as set | 2.80 J | **12.34 J** |

  So `TH_CRIT` = 2000 mV quietly asserts **+25.3 % usable energy** over the number the card
  publishes. Nobody has justified that, and it is exactly the kind of claim the #1 energy-budget
  gate exists to settle.

  **And the ordering argument says 2.0 V is probably wrong in principle.** DORMANT exists to STOP
  SPENDING so the tank can recover — so it has to engage **above** the point where the system
  stops working, not at it. A design that has already browned out cannot execute the transition.
  The card's own floor is the AVR's **BOD at 2.60 V**, and `VS_GLOW_FLOOR_MV` = 2750 is derived
  from it explicitly (`board.h`: 2600 + 150 mV of glow-sag margin). `TH_CRIT` sits 600 mV
  **below** that floor.

  **What has to be established, in order:**
  - **(a) Desk work first, and it has no home yet.** The minimum operating voltage of every part
    still on `VS` once the ASIC replaces U1 — **ADXL367, NT3H2211, MB85RC512TY** — plus what the
    TPS7A0233 does below dropout (`board.h` already notes VS tracks STO under ~3.3 V, so at
    STO 2.0 V every peripheral sees ~2.0 V). The tree currently has exactly one datum near this:
    `adxl367.h`'s 0.89 µA is specified *at a 2.0 V supply*, which shows the accel runs there but
    says nothing about the others. Record the set in one place; today there isn't one.
  - **(b) The ASIC's own Vmin is a GF180/PDK question this experiment does not claim.** It
    blocks a final number, and `asic/README.md` should not pretend otherwise.
  - **(c) Bench, on the first article.** Walk STO down and record where each function actually
    fails — tap detection, NFC read, FRAM write, glow — rather than where a datasheet says it
    might. That floor is the answer, and it feeds the CARD's numbers too, not just the ASIC's.

  **Then** set `TH_CRIT` from it and reconcile against `VS_GLOW_FLOOR_MV`, so both thresholds
  derive from one measured floor instead of two unrelated arguments.

  **Guard already in place:** `tb_sense_seq`'s check D asserts `vcrit < vlow < clamp` on the
  DISCOVERED boundaries, because the likely revision here is *upward* toward the glow floor —
  the direction that breaks the ordering. It goes red rather than producing a supervisor that
  enters dormancy while the glow gate still reads healthy.

  **Converges with** the `VS_GLOW_FLOOR_MV` vs STO-channel-accuracy item and the LED I-V sweep
  above: three separate arguments, all about where the bottom of the operating range really is.
  Take the measurements together.

- [ ] **[BENCH — BLOCKS the pogo rig] The test plate has no hold-down, only registration**
  _(2026-08-04. Raised by DRH while costing the panel; the numbers below confirm it.)_
  `enclosure/solar-glow-drh-pogo-testplate-cad.py` asserts **14 probe pads** (TP1–TP7 + JP1 ×4 +
  J1 ×3) and specs P75 probes at **~100 gf** spring. That is **~9–14 N pushing up**, working to
  full stroke. Its only fasteners are `2x dia 1.5 dowel pins through TH1/TH2` — those *register*
  the panel, nothing *holds it down*. The 1-up panel is 65.6 × 103.7 × 0.6 mm of FR4, ≈ 4.1 cm³
  at ~1.85 g/cm³ ≈ **7.6 g ≈ 0.075 N**. The springs beat gravity by **~120–180×**: the panel
  never seats, it floats off the pins. A thumb is not a test fixture.

  **Fix: clamp through the card's own eight M2 mounts.** `fit_rules.MOUNTS` — Ø2.20 plated
  through-holes, 3.60 mm annuli, all on GND, four corners plus two mid-edge pairs, on a
  **45.06 × 83.16** pattern. Distributed clamping, which also matters because 14 point loads in
  the middle will bow a 0.6 mm board that is only pinned at two rail holes.

  Three things fall out, and the third is the reason to do it even if the rig were fine:

  - **Registration gets SHORTER, not just firmer.** TH1/TH2 are in the *rail*, so the tolerance
    chain is rail → tab → rout → card. The mounts put the datum and the probed part on the same
    piece of copper-clad.
  - **In-panel testing is NOT lost.** The plate is already panel-sized, so the rails just rest on
    it — screw the card down while it is still in the frame and "test as delivered, then depanel"
    survives intact, now with actual clamping.
  - **It decouples the plate from panel topology.** Today it imports `panelize` for `TH_LEFT_Y`,
    `TH_RIGHT_Y`, `BUS_INSET` and `RAIL_W` — a fixture bolted to a frame that gets *routed away*.
    Re-based on `fit_rules.MOUNTS` it stops caring whether the panel is 1-up, 2-up or absent,
    and it sits on the same single source of truth the brace and shell already read. Note
    check [16] bans literal mount lists in `enclosure/`, so this must be an import either way.

  Do this before ordering the plate — it is a generator edit, and CI reprints the STEP/STL/drawing.

- [ ] **[BENCH] Assemble and bring up the pogo test rig when the panel arrives**
  _(Piped 2026-08-02 — the rig was built in-repo but its bring-up had no entry.)_ Everything is
  generated and committed: the in-frame pogo test plate (`enclosure/solar-glow-drh-pogo-testplate`,
  probes TP2–TP7 + TC1 with the card still in the panel), the Pico monitor firmware and channel
  map, and the host dashboard (`bench/monitor/`). Physical work remaining: print/order the plate,
  fit pogo pins, flash the Pico, and smoke-test channels against `bench/monitor/README.md` before
  the first card powers up on it.

- [ ] **[V-NEXT, PARKED] Companion ASIC — Tiny Tapeout proving ground → wafer.space quarter
  slot; the RTL experiment is BUILT (`asic/`)**
  _(Banked 2026-08-10 after the custom-silicon investigation; `asic/README.md` is the
  experiment's verdict and `asic/SPEC.md` the design contract. Deliberately NOT a v4 item —
  nothing here touches the board being ordered.)_
  **The two-rung ladder, with the numbers that matter:**
  - **Rung 1 — Tiny Tapeout (proof, not product):** €70/tile (~1 k gates, SKY130), fixed
    8 in / 8 out / 8 bidir behind a shared-die mux, ~1 year to a demo board. It CANNOT yield
    a shippable part — shared die, and the IHP shuttle's terms ban commercial use outright —
    but it proves a block on real silicon for the price of a datasheet binder.
    Shuttles at banking time: SKY26c closes **2026-09-07**, IHP26b **2026-09-21**.
  - **Rung 2 — wafer.space GF180MCU (the product path):** 180 nm mixed-signal (MIM caps,
    poly + hi-res resistors), **quarter slot = 4.9 mm², $2,000 early / $3,000, 1,000 dies,
    48 I/O + 8 power pads** (~1.94 × 2.54 mm; full slot 20.12 mm² / $7,000 is NOT needed —
    see below). Run 3: early-bird **2026-09-30**, purchase **2026-12-09**, submission
    **2026-12-16**, dies **Q2 2027**. You receive **BARE DIE** — packaging (COB or bond-out)
    and test are the unpriced half of the project. Tiny Tapeout's padframe is deliberately
    wafer.space-compatible, which is what makes rung 1 → rung 2 a straight lift.
  - **What the chip absorbs** (the green set from the absorb-map figure, 2026-08-10):
    U1's application logic, the whole STO sense chain's sequencing (R15/R16/C24 divider in
    hi-res poly + U10's gate + the deferred-read cadence in gates), Q2+R18, RN1, RN2, U6.
    Stretch: U9 (25 nA analog LDO — first-silicon risk). NEVER: U3 (MEMS), U5 (RF+EEPROM),
    U7 (FRAM process), U8+L2 (the harvester and its inductor), supercaps, cells, LEDs.
  - **Quarter over full, decided:** ~25 signals against 48 pads, and the digital core is now
    MEASURED, not estimated: 3,261 NAND-mapped cells / 251 DFFs = 0.13–0.25 mm², **3–5 % of
    the slot** (yosys, regenerate via `make gates` in `asic/`) — the analog is what sizes the chip — and $4k buys TWO quarter-slot attempts across two runs (a respin
    cycle) where $7k buys one full-slot shot with ~80 % of the die empty. First silicon is
    usually wrong somewhere; optionality beats area.
  - **The open question the experiment could not close:** whether the quarter-slot padframe
    exposes enough ANALOG-capable pads (STO sense input, four 16 mA LED sinks) — ask
    wafer.space directly before buying a slot.
  - **Wake this item only after the v4 first article ships.** The card's critical path is
    the energy budget and the read-range sweep; this ladder starts at €70 whenever there is
    slack, and the deadlines above roll over to the next run if missed.
- [ ] **[V-NEXT, PARKED] E-ink display variant — concept banked, not adopted**
  _(Piped 2026-08-02; `docs/eink-display-variant-notes.md` is the full record: panel survey,
  geometry both directions to scale, 1-bit artwork + QR mockups.)_ A different output modality
  on the same harvest/supercap/NFC/accel platform. Deliberately NOT a v4 item; revisit only
  after the v4 first article proves the platform. The doc is the decision ledger if it wakes.

## Firmware — `firmware/`, `firmware/README.md`

- [ ] **[FIRMWARE/BENCH] Turn the FRAM event log ON once the harvest budget is measured** —
  _built 2026-08-03, deliberately still `USE_FRAM_LOG 0`._
  The black box at FRAM `0x0000` now counts **taps, double-taps, NFC field reads and motion
  trips** alongside the cold-boot count it already kept. Record v2 (`DRHc`, 24 B); a v1 `DRHb`
  record is **migrated**, not overwritten, so a card already in the field keeps its boot count.
  Design note, because it is the part that matters: events cost a **saturating byte increment
  in RAM**, and at most one FRAM cycle per ~1 s poll folds them into the lifetime totals. A
  burst of taps is one wake/read/write/park, not one per tap — an I2C transaction has no
  business in the tap path, which this firmware costs at a byte-compare even when muted. The
  trade is a loss window of up to one poll if the tank dies mid-interval; these are curios, not
  telemetry, and protecting a tap count with unmeasured energy is the wrong way round.
  **Cost, measured:** shipped build byte-identical (4930 text / 21 bss — `check_fw_size` still
  matches the README); with the log on, **+238 B flash and +4 B RAM** over the same build with
  only the old boot counter. **The gate stays 0** until README's "the open question" — harvest
  vs. draw under real indoor light — has a bench number. Flipping it is then a one-line change.

- [ ] **[FIRMWARE] HOTP authenticator — PARKED behind the VOUT respin item**
  _(2026-08-03, same source.)_ Flash is not the obstacle: ~2.4 KB used of 64 KB, and HMAC-SHA1
  is another 1–2 KB. Three things are.
  (a) **Secret provisioning** — there is no secure path to get a key onto the card, and the FRAM
  is an unencrypted I2C part anyone with a clip can read. (This also sinks the "secure offline
  vault" idea from the same document: "completely isolated and offline" overstates a part you
  can read with a $3 clip.)
  (b) **It needs the card alive.** SRAM pass-through requires `NFC_EN` asserted, so the token is
  unavailable exactly when the tank is flat — the state it would be most wanted in. Routing
  `VOUT` (see the PCB item) removes this.
  (c) **Reach** — WebNFC is Android/Chrome only; iOS will not do raw tag I/O from a browser.
  Revisit when (b) is fixed; (a) still needs an answer.

_(Also from that document, dispositioned 2026-08-03: **light-aware contextual glow** — already
built, `VSENSE` on AIN2 and `STO_SNS` on AIN1, so it was a nod not a proposal. **Gesture-based
NDEF profile switching** — declined; the pieces exist (`nfc_write_ndef()`, hardware single/double
tap) but each switch is a powered NFC session plus a tag-EEPROM write, and it solves a problem
nobody reported. The document's headline **"zero-battery vampire wake, no hardware changes"** is
wrong on this board — see the PCB item; `U5` pin 7 is unconnected.)_

- [ ] **[FIRMWARE] The screened feature ledger's live remainder — imported 2026-08-02**
  _(`firmware/feature-roadmap.md` is the Gemini-brainstorm decision ledger, dispositioned
  2026-07-12: seven features shipped as `board.h` knobs, the rest triaged. It was an ORPHAN —
  nothing here pointed at it. This item is now the single live pointer; the ledger carries the
  detail and stays.)_ The still-open remainder, by gate:
  **(a) Actionable now, energy-safe: one BUILT, one DECLINED, 2026-08-02.** The VSENSE-dark
  co-condition landed as `USE_DARK_DORMANT` (30 min dark → tap/motion/ack glows suppressed in
  any orientation; **double-tap is the deliberate dark-room escape**, answering the won't-do
  note's nightstand objection; light exits in ~1 poll). **Shipping/coma mode is declined** —
  built and removed the same day: the card is hand-delivered, so the dark-shipping-box premise
  never occurs, and what it bought (~1.5–1.7× on box standby, since only ~1 µA of the ~2.7 µA
  dark sum is firmware's to trim) did not justify a mode that changes the poll period, disables
  the watchdog and re-powers the card's only input. Decision record in `feature-roadmap.md`;
  working implementation in git history if a mailed-batch variant ever becomes real.
  **(b) Gated on the energy-budget bench** (the #1 gate — these spend LED energy or need measured
  constants): zero-CPU reflex glow (EVSYS→TCA0), CCL heartbeat, ambient auto-brightness,
  shadow-abort / AC0 brownout-reflex, "find the sun" bar-graph, circadian duty-cycling, PoV
  air-message, free-fall catch, FIFO gestures.
  **(c) Revival hooks only if a companion app ever exists:** SRAM-mailbox telemetry /
  orientation-keyed NFC (declined for v4 — they endanger the offline-first vCard).

- [ ] **[BENCH/DESIGN] SWEEP_SUN_VIN_MV measures the wrong thing — retune or retire it**
  _(2026-07-26 PCB audit; board.h comment already corrected in full, constant deliberately left
  at 3600 pending this decision.)_ The AEM10300 does not let SRC float to a light-dependent
  voltage: while charging it **regulates SRC to 0.80 × Voc** (R_MPP[2:0] = H,L,L → 80%, Table 9,
  read off the board straps). Reaching 3600 mV would need Voc ≥ 4500 mV, above the SM141K06TF's
  4.15 V — so the SUN flag is unreachable while charging in ANY light. It sets only when the tank
  is full (DCDC off, SRC high-Z → Voc, which also saturates the 2.048 V ref) or during the 70.8 ms
  MPP-evaluation window every 4.5 s (T_MPP = H,L, Table 10) — a 1.6% duty artifact.
  Consequences: (a) the sweep's two co-gates are really one condition, so the sweep still behaves
  correctly but for the wrong stated reason; (b) **the sun diary does not bank sun-hours** — it
  banks caps-full time plus that 1.6% artifact, which is a second independent error on top of the
  poll-counting one already filed. Decide at the bench: set the threshold below 0.8 × Voc
  (~3000–3200 mV) so it genuinely discriminates bright from dim while charging, or drop the
  co-gate and re-scope the diary to what it actually measures.

- [ ] **[BENCH/CALIBRATION] VS_GLOW_FLOOR_MV vs the STO-channel accuracy stack-up**
  _(2026-07-26 pass 4; the highest-value open firmware item.)_ Pass 3 removed the *systematic*
  error (the 2.500 V reference sagged below its 3.0 V spec floor and inverted the guard). What
  remains is ordinary tolerance: reference ±2% (−40..+85 °C, ±5% to 125 °C) + ADC offset/gain/INL
  + divider, which at the extended-temperature corner still lets `VS_GLOW_FLOOR_MV = 2750` permit
  a glow at a true STO **below the 2.60 V BOD**. Restoring the intended 150 mV of sag margin at
  the worst corner implies a floor near **2900 mV**, at the cost of usable range. **Measure it**:
  read `sense_vdd_mv()` against a meter across 2.6–4.65 V and over temperature, then set the floor
  from data. Do not fold in a datasheet corner blind — it trades real runtime for paper margin.
  Same stack-up applies to `EE_WRITE_FLOOR_MV` (2850 vs erratum 2.2.1's 2.7 V) and
  `SWEEP_CAPS_FULL_MV` (4400 vs VOVCH 4.65 V, whose datasheet row has no min/max).
  **Pair this with the LED I-V sweep above** (2026-08-20): that item reaches the same constant
  from the LED side — whether a max-Vf part can conduct at all at 2750 mV — and also lands near
  2900. Independent arguments, same direction; measure both before moving the floor once.

- [ ] **[BENCH] Confirm the reordered NFC provisioning end to end** _(2026-07-26 pass 4.)_
  Provisioning now writes the NDEF first and the CC **last**, so a partial write leaves a tag
  readers ignore rather than one advertising garbage. Verify on a real tag: (a) the phone offers
  the vCard after a clean run; (b) `nfc_present()` still ACKs at 0x55 after the block-0 write
  (datasheet sec 8.3.8 warns the address byte and static lock bytes live in that block); (c) an
  interrupted run leaves the tag inert rather than half-published.

- [ ] **[FIRMWARE] Residual efficiency items, each already quantified** _(2026-07-26 pass 4;
  none applied — they need the energy budget measured first to know if they are worth it.)_
  `adxl367_clear_activity()` fires unconditionally in the tap and NFC-ack branches (~367 µs of
  ACTIVE I2C each) even when INT2 never asserted; `adxl367_read_z()` runs every poll though
  dormancy integrates over 180 s; the TCB ticks at 1 ms while the animation only updates duty
  every 12 ms (11 of 12 wakes do nothing); `gamma2()` floors inputs ≤ 15 to zero so ~7.8% of every
  breath is a black hold; TWI waits and the fram_sleep retry busy-spin in ACTIVE where they could
  IDLE-sleep.

- [ ] **[BENCH] ADC reference moved 2.500 V -> 2.048 V — re-verify every gate on silicon**
  _(2026-07-26 deep audit; fix LANDED.)_ The 2.500 V reference is spec'd only for VDD >= 3.0 V
  and `VVREF` max is VDD-0.4, so below ~2.9 V it sagged and every rail gate read HIGH — the
  2750 mV glow floor actually tripped at ~2582 mV, **below the 2.60 V BOD**. Now on 2.048 V
  (valid to VDD 2.55 V, ±2%). Bench: (a) confirm measured STO/VIN mV against a meter across
  2.6–4.65 V; (b) confirm the glow floor now genuinely stops the glow above the BOD;
  (c) confirm `sense_vin_mv()` saturation above VIN 4.096 V is acceptable in practice.

- [ ] **[BENCH] SWEEP_CAPS_FULL_MV 3300 -> 4400 — confirm the sweep still arms**
  _(2026-07-26 deep audit; fix LANDED.)_ 3300 was a stale v3 value (when the sensed rail was the
  clamped ~3.5 V supercap node); against STO's VOVCH 4.65 V ceiling it was only 71% of full /
  50% of energy, so the "hard safety gate" allowed spending half the tank, re-armed every poll.
  Bench: confirm a real card in strong sun actually reaches 4400 mV STO and plays the sweep —
  if the AEM's charge taper makes 4400 unreachable in practice, tune down toward ~4300, but do
  NOT return to a value that is not a fullness criterion.

- [ ] **[BENCH/DESIGN] Sun diary counts POLLS, not TIME — and is least accurate while measuring**
  _(2026-07-26 deep audit.)_ `SUN_POLLS_PER_HOUR` assumes one poll == POLL_PERIOD_S exactly, but
  (a) OSC32K total error is <1% only at 25 °C/3.0 V and **<10% over the full range** (Table 35-10),
  and (b) the in-sun sweep fires on the same condition the diary counts and stretches the loop
  period, so a banked "hour" is long by the sweep duty in exactly the state being logged. Decide:
  either re-label the diary as approximate in the docs/NDEF, or count elapsed PIT ticks
  independently of loop servicing. Do not present it as a measurement until one of those is done.

- [ ] **[BENCH] The MCU energy budget cannot be given a worst case from current sources**
  _(2026-07-26 deep audit.)_ DS40002443**A** is a *Preliminary* datasheet: its power tables state
  "not tested and are for design guidance only", every sleep-current Max column is **empty**, and
  there is no 1 MHz IDD row (lowest is 5 MHz). So the standing-current figure is a typ-only
  extrapolation. This must be **measured**, not derived, before the energy budget is called
  closed — and re-checked against a non-preliminary datasheet revision if one ships.

- [ ] **[BENCH] Tank ceiling and midpoint balance — log STO and MID across full charge cycles**
  _(2026-08-01, ThomsonLint review COMP_CAP_004 — see `docs/thomsonlint.md`.)_ The repo's own
  worst-case math assumes a full tank at 5.5 V, which is the cells' rated voltage with zero
  headroom; EDLC life derates steeply near rating. What actually bounds it is the AEM10300's
  configured storage ceiling — never measured on hardware. During the energy-budget pass, log
  STO and MID (TP3) across full charge cycles: confirm the enforced ceiling and the top-of-charge
  cell balance. If the ceiling lands at rating, consider configuring the harvester one step down
  for cell life.

  **RE-AIMED 2026-08-04, because the phenomenon this was written to catch does not exist.** The
  docs described "unequal series stages" that BAL had to hold apart; the board's stages are
  **equal by construction** — SC1 ∥ SC2 = 2.8 F above `MID`, SC3 ∥ SC4 = 2.8 F below, one SS17 and
  one WS17 in each. So there is no designed capacitance imbalance for a top-of-charge measurement
  to find, and **top-of-charge over-volt is the wrong thing to look for**.
  What BAL actually corrects is **leakage mismatch between two identical stages**, and leakage
  mismatch shows up as **MID drifting away from V/2 in the DARK, over days** — not during a charge
  cycle. Log MID against STO/2 on a charged card left unlit, and give it long enough to diverge;
  a charge-cycle log will look clean whether or not the balancer is doing anything.
  Also worth confirming in the same session: STO caps at the strapped **4.65 V**, not 5.5 V — the
  difference between **15.1 J stored** and the 21 J nameplate, and between 9.8 J and 21 J spendable.

- [ ] **[EFFICIENCY] Quantified idle-draw levers, if the bench budget comes in tight**
  _(2026-07-26 deep audit; all measured-on-paper, none applied.)_ Ranked: `POLL_PERIOD_S` 1 -> 2
  halves the ~1 Hz housekeeping cost; `FRAM_RESLEEP_EVERY_POLL` -> 0 removes the defensive re-park
  (already ~halved by dropping its trailing busy-delay); `adxl367_read_z()` runs every poll though
  dormancy only needs 180 s of evidence; the TWI/`_delay_us` waits busy-spin in ACTIVE where they
  could IDLE-sleep. Also **hardware, not firmware**: the R15/R16 STO divider is 3 MΩ across the
  tank = **1.1–1.55 µA continuously**, comparable to the whole MCU standing budget and larger
  than the accelerometer — worth revisiting if the budget is tight.

- [ ] **[BENCH] NFC Capability Container write — confirm the tag survives at 0x55**
  _(2026-07-26 firmware audit; fix LANDED in `nfc_write_cc()`.)_ The tag ships with CC = all-00h
  (datasheet 8.3.10), so provisioning now writes `E1 10 6D 00` into I2C block 0 — the block whose
  byte 0 is the I²C address. We write `NT3H_ADDR << 1` = 0xAA there, the only value correct under
  both of the datasheet's two contradictory statements (8.3.2's "MS 7 bits are the address" rule vs.
  its trailing REMARK recommending 04h). **On the first provisioned tag, verify `nfc_present()` still
  ACKs at 0x55 after the CC write.** If it does not, the tag moved to 0x02 — repoint `NT3H_ADDR`;
  RF/vCard is unaffected either way. Then confirm a phone actually offers the vCard (the whole point
  of the fix — before it, no phone would).

- [ ] **[BENCH] I²C bus-clear — exercise the recovery path** _(2026-07-26 firmware audit; fix LANDED
  in `twi_bus_clear()`, called from `twi_init()`.)_ Deliberately wedge the bus (reset the MCU mid-read
  so a target is left driving SDA low) and confirm the 9-pulse + STOP recovery frees it and the accel
  answers on the next boot. Also worth scoping once: that the recovery's 5 µs half-period is really
  ~100 kHz at the fused 1 MHz CLK_PER.

- [ ] **[BENCH] ADXL367 7.5 ms reset latency — confirm config now sticks** _(2026-07-26 firmware audit;
  `_delay_ms(2)` → `_delay_ms(10)`, datasheet Rev. B Table 37.)_ The old under-spec wait could leave the
  part at reset defaults with the tap engine off. After flashing, read back FILTER_CTL / POWER_CTL /
  INTMAP1_UPPER over I²C and confirm they hold the configured values, not 0x00 / reset defaults.

- [ ] **[BENCH] LED sub-emission idle-bias — Hi-Z park + docs LANDED, bench measurement remains**
  _(2026-07-23 fw / 2026-07-25 docs; the pads park as inputs between animations (bias → clamp-limited
  ~1 V worst case, zero below STO ≈ 3.6 V), and both the Hi-Z park and the SW2-OFF stow discipline are
  now documented in `firmware/README.md`.)_ Remaining: (a) bench-measure the real idle LED current;
  (b) only if the energy budget allows, consider a VOVCH re-strap one step down (E ∝ V², costly).

- [ ] **[BENCH] FRAM back-power fix — verify the VS-rail + Sleep-park** _(2026-07-23; sch + fw + board
  all done & verified.)_ Bench-confirm: IZZ standing current (~0.20 µA typ), VS idle current, and
  whether the FRAM's Sleep-exit wake is address-selective — if it is, set `FRAM_RESLEEP_EVERY_POLL 0`
  (the defensive per-poll re-park is then unneeded). Full analysis in the design-notes deep-dive
  addendum.

- [ ] **[BENCH] NFC FD-pin leakage — meter the real standby adder** _(2026-08-01 pressure test, the
  panel's one major: NT3H2211 Table 42 specs FD IL at **1.5 µA typ / 10 µA MAX**, flowing from VS
  through PA6's internal pull-up whenever FD idles high — the card's dominant state — independent of
  pull-up value; unbudgeted in the ~2.7 µA standby sum, which is now labeled a 2.0 V-referenced lower
  bound. board.h's FD block carries the full story.)_ Bench: meter VS with FD pulled up vs FD grounded
  (tag VCC gated off, no field) to pin the real leakage; re-check FD's VIH margin at measured IL ×
  measured pull-up R; and while there, meter the gated-VCC SDA/SCL leakage through RN2 (né R10/R11, consolidated 2026-08-08; same
  table, 10 µA max/pin spec). If the measured adder is real µA, the counter-moves are an external
  weak pull-up on FD or accepting the line item — decide with the energy-budget numbers in hand.

- [ ] **[BENCH RULES] Cross-domain bench-procedure set** _(2026-07-23 second-sift)._ (1) JP1 SCL/SDA:
  external I²C adapters only with the card powered and the adapter referenced to VS — the ADXL367 (and
  the FRAM) digital abs-max is a zero-headroom "−0.3 to VDDIO". (2) STO injection: SW2 OFF first (a lit
  injection above ~2.5 V forward-drives the LEDs into the dead MCU's clamps, ~16 mA/pin). (3) Dark
  bench-charging of STO: pre-balance the 2S midpoint or charge under light (BAL active). (4) UPDI into
  a flat card: power the card via the programmer (~0.5 mA PF7 clamp current otherwise — bounded but
  pointless).

- [ ] **[BENCH] Read + log the EA silicon revision (B1 vs B2)** _(2026-07-23)._ Errata 2.2.1–2.2.3
  (DS80001048C, in `datasheets/`) are Rev. B1-only; the firmware carries the 2.2.3 SLPCTRL NOP-guard
  either way and `EE_WRITE_FLOOR_MV` covers 2.2.1. Read `SYSCFG.REVID` over UPDI at first connect so we
  know which part we actually got. Also **re-measure the EA sleep/power figures against real
  silicon** — DS40002443A was PRELIMINARY, so its numbers are typ-only — and re-confirm the
  port-derived floors (`VS_GLOW_FLOOR_MV` 2750 / `EE_WRITE_FLOOR_MV` 2850) still hold.

- [ ] **Program fuses on hardware** (EA values, from DS40002443A — verify before burning):
  **`bodcfg 0x4A`** = 2.60 V sampled BOD (BODLEVEL2; the EA has no 2.45 V level). **NOT `0x0A`** =
  BODLEVEL0 1.75 V, chip-erase-only → ships the card BOD-off. **`osccfg 0x08`** = OSCHF base 16 MHz so
  `clocks_init`'s ÷16 lands on exactly 1 MHz (pre-fuse it runs a harmless 1.25 MHz). **`syscfg0 0xD1`**
  = factory + EESAVE (keeps the black box across a reflash). **`syscfg1`: factory default** (the EA has
  no MVSYSCFG). `make fuses` prints the commands. The BOD is also the cold-start guard and the hardware
  backstop to the software EEPROM-write floor (2.85 V).

- [ ] **Bench-verify a dead-battery cold-start.** From supercaps at 0 V under *dim* indoor light (worst
  harvest), confirm the rail climbs cleanly past the 2.60 V BOD release without stalling — the AVR's
  reset-state draw on a slow (mV/s) ramp must stay below the harvest current so it never sticks at an
  intermediate voltage. (It's a brown-out *stall*, not latch-up. Program the BOD fuse first — it's the
  guard. Q2 now also keeps AEM charging enabled while the MCU is in reset — the cold-start-deadlock
  fix.)

- [ ] **Bench validation** (bare-card starting points, re-tune enclosed): tap axis (Z), tap/activity
  thresholds, INT edge/polarity, LED `INVEN` polarity.

- [ ] **[EA upgrade, bench-era] Use the EA ADC's differential mode + PGA + burst accumulation** for the
  rail/light reads _(2026-07-23, deferred from the EA port)._ The port keeps DD-shaped single-ended
  reads so behaviour is 1:1; the EA can do better (diff vs GND kills common-mode offset on the ~500 kΩ
  dividers, PGA relaxes the source-impedance math, ×N accumulation averages divider noise — it pairs
  with the 0.1 %/25 ppm thin-film dividers already on the board). Do it after the energy measurement,
  meter attached: each knob changes conversion time and therefore poll energy.

- [ ] **Energy-budget bench measurement** — the project's **#1 gate**; sets the real achievable glow
  duty. Every firmware duty-cycle / glow constant is provisional until it lands. **Size it to the LED
  brightness FLOOR:** D2–D5 ship unbinned (`V2BB` is a min-to-max span), so output varies ~3× part-to-part
  — V2 = 900 mcd / 3030 mlm (~49 lm/W) up to BB = 2800 mcd / 7560 mlm (~123 lm/W) at 30 mA. Design against
  V2; a kind reel just looks better. (LED-audit addendum, 2026-07-25.)

## PCB — `PCB/solar-glow-drh-v4_0.kicad_pcb` / `.kicad_sch`

- [ ] **[LAYOUT — v5] Inert index posts beside the supercaps, tied to GND**
  _(2026-08-23. DRH places them manually; re-derive every coordinate below with
  `python3 scripts/index_posts.py`, which computes them from the current board — do not
  hand-edit the numbers here.)_
  Cheap chip parts soldered beside SC1–SC4 so a hand-placed cap seats against something
  sacrificial instead of against a live component. **Two on each cap's LONG datum edge, one
  on the short** — a two-point contact is what constrains **rotation**, and rotation is the
  dominant placement error (1° swings a 39 mm cap's corner 0.34 mm; the caps reach a real
  part at 2.02–6.71°). One post stops translation and does nothing about rotation. Datum
  edges are `fit_rules.CAP_DATUM`, i.e. the same two the reflow shim indexes.
  - **Net: GND.** Not floating and **not a live rail** — a part whose job is to be struck by
    a 17 × 39 mm slab should fail cosmetically, not electrically. GND over floating is for
    MECHANICS, not function: a pad bonded to the pour has more copper anchorage against
    lateral load. Costs thermal relief to solder.
  - **Not capacitors.** Contributory energy storage fails by three orders of magnitude: all
    ten placeable sites filled with the largest 6.3 V X5R each is **706 µF nominal = 0.05 %
    of the 1.40 F tank**, 4.96 mJ of its 9.84 J usable, and ~0.015 % after a realistic 30 %
    DC-bias derate. 1 % of the tank would need 14,000 µF. No ESR case either — the SCPC cells
    are 25/40 mΩ (30.8 mΩ for the bank), so the 22.46 mA LED envelope droops **0.69 mV**. No
    balancing case — the AEM10300's BAL pin already holds the midpoint, which is why U2 was
    deleted in v4. Decoupling belongs at the pin: C27 (10 µF) is already 4.84 mm from U8.
  - **Measured today, 10 of 12 sites place** (collision against body ∪ pads + 0.20 mm, dnp
    copper included). **Only SC3 gets a working rotation datum** — 2 solid posts on its long
    edge. SC1 and SC2 get 1 each; SC4 gets 0. `SC1 E@80 %` is blocked by **C11** and
    `SC4 W@20 %` by **Q2**; moving those two is what would give all four caps a datum.
  - Packages fall out of local room, not choice: 2512 → 1206 → 0805 → 0603. **0603 is
    INADEQUATE for shear** (`PCB/README.md`: "a 0402 will shear before it indexes a
    supercap"); 0805 is marginal. Two sites currently land on 0603.
  - **These are real footprints and they are not free.** Each one needs: a
    `part_heights.py` entry (`part_height()` **raises** on an unmapped refdes), a BOM line
    with MPN **and** Manufacturer (`bom_split.build()` fails on an MPN with no manufacturer),
    a CPL row (check [15] gates pick-and-place against BOM), a `part_colors.py` colour
    (check [10]) and a 3D model — and each becomes a brace blocker or pocket, so the
    footprint recomputes. Budget the gate work with the placement.
  - Suggested refdes `MP1`–`MP12` rather than an `R` prefix, so nothing reads them as circuit
    resistors. Value `0R`.
  - **What this does NOT replace:** the reflow shim (`enclosure/shim/README.md`). Posts index
    but cannot clamp, and the caps must be held while the paste is molten. The prize if all
    four caps ever get a real rotation datum is decoupling the brace from the shim — today
    the anisotropic bays mean the brace only fits a cap the shim seated.

- [ ] **[LAYOUT — lite-brace headroom] Component moves that buy back the lite brace's lost third**
  _(2026-08-07, from the enclosure-variants round. DRH does the moves manually; everything downstream
  regenerates from the board — brace, shells, drawings, renders are all functions of it, so a pushed
  board re-derives the lot with no hand step beyond `mask_art --apply` if front copper moves.)_
  The **lite** variant's cavity is **1.22** (component-limited: thin 1.00 caps + U1/L2 at 1.00 + AIR
  0.22), so `SPAN_LIMIT` falls 1.18 → **0.60** and 24 parts become blockers. The brace drops from
  1413.8 mm² / 35.2 % of the cavity floor (max) to **935.7 / 23.3 %**, giving up **344.6 mm² in four
  islands** — the N/S corridors between the supercap pad zones, each severed at its mouth by one or
  two movable parts. Ranked by measured main-piece gain (re-derive any of this from
  `fit_rules.brace_footprint()` with `CAVITY/GAP/SPAN_LIMIT` set to the lite values; the what-if is
  "exclude the ref from `blockers()` and re-measure"):
  - **U3 (accel) +75.6 mm²** — reconnects island 3 (67 mm², the N corridor between SC1/SC2). The
    freest mover on the board: I²C + INT1/INT2 only, and tap sensing works anywhere on a rigid card.
  - **C23 +103.2 mm²** — reconnects island 0 (100 mm², W corridor at SC3). Constraint: it is U9's
    rail cap — move it **as the U9 cluster**, not alone.
  - **L2 +109.3 mm²** — reconnects island 1 (96 mm², center corridor). Hardest constraint: the
    AEM10300's LX loop inductor — moves only **as a pair with U8** (U8 itself is +30.5 more).
  - U7 +40.9, U1 +29.8: widen the main band only; no island rescue.
  - **Island 2 (81 mm², E corridor) is unrecoverable** — severed by SC4's own pad zone, the max
    variant's known ~85 mm² island wearing its lite face.
  - Combined, measured: U3+C23 → 27.8 %; **U3+C23+L2 → 30.5 %**; all six → 33.0 % (max is 35.2 %).
  - **Bare pads do NOT block the brace** (their 0.20 budget is under even the 0.60 span limit) — the
    pad problem is the **lips**: J1 (optional header), JP1 (bench strip), and TP1/TP2/TP7 sit inside
    lip strips (W edge: 7 bands pinched by J1/TP2/TP7 + the west cap row; E edge: single band, JP1 +
    TP1 inside it, already coil-capped at x 49.55). Moving or deleting those bare-pad items widens
    the lip bands on every variant; moving the four supercaps' zones is the design itself, not a move.
  - Standing rules still apply to the session that does the moves: `mask_art.py --apply` after any
    front re-route (check [6]), and the teardrop-inclusive in-aperture sweep if anything approaches
    the glow window (`PCB/README.md` supercap box).
  - _2026-08-07 addendum: the CAP SCOOT landed first (all four supercaps to a uniform 1.00 mm body
    standoff from their board edge; the shell's lip ring is now part-aware — fit_rules `RING` +
    `ring_reliefs()` — after six probed ring-vs-part collisions). Post-scoot baselines: **max 1486.7
    mm² / 37.1 %**, **lite 1078.2 / 26.9 %** (dropped 277.0 in 3 islands — island 3's corridor
    mouth widened but U3 still severs it). The ranked what-ifs above (U3/C23/L2 gains) were measured
    on the PRE-scoot board — re-derive them before acting; the method line above is unchanged._
  - _2026-08-07 evening: DRH's CENTER CONSOLIDATION superseded most of this plan — eleven parts
    (the U6/C4/C6/C7/R14/TP2 west cluster, the R5/R6/Q2/R18/C5 east cluster) moved into the center
    column x≈25–27, and SC1/SC2/SC4 scooted horizontally (SC1 −1.91, SC2 +1.70, SC4 +0.36). The
    trade, measured and accepted: total brace **max 34.3 % / lite 26.4 %** (leg area given up to
    the cap scoots — legs are lip/cap/cell-backstopped by design) while the **center band y40–48.9
    holds at 91 % (max) / 73.5 % (lite)** — the band was already brace-saturated, so consolidation
    cleaned the legs rather than adding center coverage. C4 and Q2 (0.90) are now mid-board
    lite-blockers, both OUTSIDE the critical band. The U3/C23 island-recovery moves above remain
    UNEXECUTED and the numbers need re-deriving on this board before acting._

- [ ] **[PCB — DRC hygiene] `missing_courtyard` is blind, and it hid a 0.090 mm hazard**
  _(2026-08-04, raised by the SC1↔C1 sweep. The re-measure half of this item closed 2026-08-05:
  the land correction moved SC1's pads ±1.30 mm **symmetrically**, so the can registration did
  not move and SC1↔C1 stands at **0.090 mm** — with SC2 0.350, SC3 0.385, SC4 0.420. It did NOT
  resolve itself; the accepted mitigation remains the caution in `PCB/README.md`'s hand-solder
  step, and the boxed-in-C1 numbers live in that same box so nobody re-derives them.)_

  What stays open is the reason nothing caught this: `missing_courtyard` is `"ignore"` in
  `PCB/solar-glow-drh-v4_0.kicad_pro`, and **39 of 73 footprints carry no courtyard at all,
  19 of them machine-placed** (C1, C11, C12, C24, C29, C3, C5, C6, C7, C8, R1, R10, R11,
  R14, R17, R18, R2, R3, R4 — recounted 2026-08-05: 39 of 73 courtyard-less after SB1–4/R12 left). Turning the rule on without drawing those courtyards just trades
  one silence for 20 false alarms, so it is a two-part job: give the library 0402s courtyards,
  then set the rule to `warning`.

- [ ] **[PCB/BENCH — cheap, any time] Feel coupons: bare same-size boards at 0.4 and 0.2 mm**
  _(2026-08-02, born from the thickness decision.)_ Order the cheapest possible bare PCBs at the
  card's exact outline (50.8 × 88.9 mm, any copper, any colour) in **0.4 mm and 0.2 mm** — plus
  the 0.6 reference the real panel already provides — and just *handle* them. If the flex
  difference is imperceptible in hand, a future revision can bank the 0.2 mm; if it reads cheap,
  the 0.6 lock is confirmed by touch, not guesswork — and either way the enclosure work that
  follows is informed **by handling it, not just guessing**. No assembly, no schematic, no panel:
  a one-outline Edge.Cuts board at a budget fab is a few dollars a piece. Decoupled from the
  hero order; do not let it gate anything.

- [ ] **[PCB/EMC] EMC pre-compliance — paper half DONE 2026-08-01, measured half open.**
  kicad-happy's `emc` skill ran in full mode (risk score 64.0, 37 findings — every one triaged
  in `docs/kicad-happy.md` → "Deep analysis"): no new real board defect; the plane-gap errors
  are the coil and the glow window measuring as what they are, and the one genuine hygiene item
  (GND stitching vias) is the next bullet. What remains is the **measured** half once the
  first-article exists: near-field probe over the AEM10300 hot loop and the LED string under
  PWM, and a reader-coupling check that the NFC coil's Q survived assembly (Ti shell + ferrite).
  Start the probe at **L2 (26.2, 58.7)** — the tool's own test plan names it the highest-dI/dt
  point on the board; its four FCC Part 15 B radiated bands all rate "risk: none" on paper.
  For the coil check, the paper baseline to measure against (2026-08-01, `scripts/nfc_coil.py`):
  **L ≈ 1.09 µH bare copper, f0 = 15.47 MHz at the placed C9 47 pF** — the ferrite-loaded tank
  should land near 13.56; how far it lands from the bare number IS the measured ferrite factor.

- [ ] _(Low)_ **`PCB/README.md`'s parts table is a hand-maintained duplicate of the BOM master** and has
  now drifted twice (it was still listing `AVR64DD28-I/STX`, `TPS22918DBVR`, the SOIC-8 FRAM and
  pre-longevity-pass passives when caught on 2026-07-25). It was regenerated from the xlsx and marked
  as a dated derived snapshot, but the structural fix is to **generate it in CI** from the master
  (kibot already regenerates `Generated/fabdocs/…-bom.csv`) or to cut it down to a pointer plus the
  order-time hazards. Until then, re-check it whenever the BOM changes.

## Enclosure — `enclosure/…-backshell-…-cad.py`, `enclosure/brace/`

- [ ] **[SOURCING — lite/air] Pick the thin supercap MPN**
  _(2026-08-07, opened with the three-variant round.)_ `part_heights.SUPERCAP_H_THIN = 1.00`
  is **PROVISIONAL — DRH's working number, no MPN, no datasheet behind it**, unlike every
  other figure in that file. The lite cavity (1.22) happens to be component-limited so a
  small thickness change is free, but **anything over 1.00 starts moving the lite/air
  numbers** (`fit_rules.VARIANTS` re-derives them — one edit, everything follows: cavity,
  stack, screw pick, ledgers). When chosen: verify max thickness from the datasheet, land
  the number + the datasheet in `datasheets/`, and note the 2+2 capacity split question —
  the buy documents today describe the ONE committed board, which is the 1.70 build;
  thin-cap purchasing for lite/air builds is a manual substitution until then. Also the
  **air NFC re-tune** rides this: open back = no titanium behind the coil = C9's 47 pF
  needs the bench again (`enclosure/README.md` variants table carries the warning).

- [ ] **[ENCLOSURE, cosmetic] The shell STL's one tessellation pinch** _(2026-08-01, found and
  ledgered by `scripts/check_mesh.py` on its first measurement.)_ One zero-length boundary edge
  at a single rim point (24.4, −34.45, 2.7) plus 3 zero-area facets — a cadquery boolean seam
  artifact, invisible to slicers (open length 0.000 mm). Ledgered in the mesh gate so anything
  worse goes red; chase only if a cadquery bump changes the count, and fix belongs in the
  shell generator's tessellation parameters, not the mesh.

  _(Absorbed from the culled cosmetic item, 2026-07-30 purge: the same README's via-in-pad list
  is v3-era — two new via-touching-pad cases exist and zero true via-in-pad remain; correct it
  in the same pass.)_
- [ ] **Front solar-panel fence** — concept only. Panel height known (**cell 1.2 mm ± 0.3 mm**,
  SM141K06TF datasheet p.1 + p.3 drawing — caliper-check the actual cells before cutting fence height;
  the ± 0.3 mm spread is wide for a melted-in fit). Still blocked on attachment (M2 screws / adhesive /
  snap-fit) and direction A (full-perimeter, recommended) vs B (per-panel rings).

- [ ] **[ENCLOSURE/TOOLING] A heat-tolerant hand-solder jig for SC1–SC4 and PV1–PV2** — the
  parts the machine never places, held in register through the melt *and the freeze*.
  _(DRH, 2026-08-03. Not scheduled; recorded before it is needed, because one of its inputs is
  not final yet — see SEQUENCING.)_

  **The problem has a number, and the number is `CLR = 0.25`.** `enclosure/fit_rules.py:92`
  sets the brace's in-plane clearance around every part body at 0.25 mm. So a supercap
  hand-soldered more than a quarter of a millimetre off its footprint does not merely look
  crooked — it fouls its own pocket wall, and the brace stops seating. The failure is silent
  at solder time and only shows up at final assembly, on a card that by then has everything
  else on it. Same story for the cells against the eight M2 screws: they already fit "almost
  too exact" (which is why all 8 mounts moved 0.13 mm diagonally on 2026-08-03), so a cell
  soldered a few tenths proud puts lateral load on its own terminals.
  **And the supercap joints are UNDER the body** (`PCB/README.md` → hand-solder order): you
  cannot see them, so you cannot inspect-and-nudge. Alignment has to be mechanical or it is
  nothing.

  **Why a normal print will not do**, which is the whole reason this is its own item. The
  requirement is not "hold it while I solder" — it is **hold it while it cools**, so the part
  cannot shift as the joint freezes and the jig can be lifted off a solid assembly. That means
  the jig is in contact with a part at hotplate temperature for the whole cycle. PLA/PETG/ABS
  and standard SLA resin are all out by a wide margin.

  Real candidates, and they are not equivalent:
  - **FR4, ordered as a PCB from the same fab.** Strongest option and the most repo-idiomatic:
    FR4 survives a 260 °C reflow *by definition*, a milled/routed outline holds ±0.1 mm easily,
    it is nearly free, and it can ride the existing PCBWay panel (`scripts/panelize.py`) so it
    arrives dimensionally matched to the boards it registers. Low thermal conductivity, so it
    does not rob the joint.
  - **PEEK or machinable ceramic (Macor)** — ~250 °C continuous, low conductivity, machinable
    to a fit. Costs real money.
  - **High-temp platinum-cure silicone** — compliant, insulating, forgiving of the cell's
    fragile laminate; poor at holding a hard datum on its own, so it wants a rigid frame.
  - **Aluminium — the tempting wrong answer.** A metal jig sitting on a hotplate is a heat
    sink pressed against the exact joint you are trying to melt; expect cold joints and a
    profile you cannot repeat. If metal, prefer **stainless** (~1/15 the conductivity of Al)
    and minimise contact area.

  **Register off the mounting holes, not the board edge.** MH1–4 / MP1–4 are NPTH at positions
  `enclosure/fit_rules.py` already publishes as `MOUNTS`, gated against the board by
  consistency check `[16]` — so a jig derived from that table cannot drift from the drills.
  The routed outline is the looser datum.

  **The two parts are NOT one jig, because their thermal specs are not the same shape:**
  - **SC1–SC4**: SCHURTER gives `Soldering Methods: Manual` and an operating range of
    −40…+85 °C, and publishes **no peak-temperature or reflow profile at all**
    (`datasheets/SC1-SC4  SCHURTER 3-153-438  $16.69.pdf`). There is no number to design a
    hotplate profile against — establishing a safe one on scrap cells is part of this task,
    not a detail of it.
  - **PV1–PV2**: **≤ 260 °C for ≤ 2 s per joint, no reflow, moisture-sensitive laminate**
    (`docs/harvest-budget-test-board.md`, `PCB/README.md`). A hotplate that soaks the whole
    cell is precisely what this part is not rated for — so the cell jig may need to be a
    *heat-shield-plus-clamp* that keeps the plate off the laminate while a local iron does the
    four joints each, rather than a soak fixture. Decide this before cutting anything.

  **SEQUENCING — the supercap-jig gate LIFTED 2026-08-05.** This paragraph used to block the
  supercap jig on the knowingly-wrong lands (±11.00 / ±16.25 against the datasheet's
  ±12.30 / ±17.55). The land correction landed 2026-08-05 — board pads now at datasheet pitch,
  `x = 0` — so a jig cut from today's board encodes the right pitch. The **cell** jig never had
  the dependency. One residual: the jig generator must read pad positions from the *board*, per
  the "Shape of the work" below, so it inherits any future correction for free.

  **Shape of the work**: follow `enclosure/solar-glow-drh-pogo-testplate-cad.py`, which is
  already exactly this kind of thing — a fixture that is not part of the product, generated
  from the committed board, emitting STEP/STL/drawing, with its own `kibot.yml` trigger. A jig
  generator that reads part positions from `PCB/solar-glow-drh-v4_0.kicad_pcb` and mount
  positions from `fit_rules.MOUNTS` stays correct through every future re-route for free; a
  hand-drawn one starts rotting immediately.

## Locked — do NOT re-open

- **Accepted copper trade-offs (2026-07-26 audit, re-affirmed at the 2026-07-30 purge)** — each
  was pitched as trivial, re-rated as needing neighbour reroutes, and judged defensible to leave:
  no analog net class (ADC nodes at the clearance floor against active nets); F.Cu pour under L2
  and ~93 % of the switching-node copper with B.Cu hugging LIN/LOUT at 0.20 mm; LIN/LOUT/BUFSRC at
  0.15 mm width (~47 mΩ in series with the inductor); CINT 12.3 mm of 0.15 mm track from the real
  VINT pin; the STO feed necking to 0.3 mm for 15.8 mm. Re-open only with a measurement that one
  of them costs something real.

- **U6 = TPS22919, decided 2026-08-05 — do not re-research the family.** The first pass answered
  "no clean option" by searching inside TPS229xx and stopping; that was wrong, and the corrected
  survey is in git history. Note TPS22917 ships in exactly one package (SOT-23-6/DBV) and has no
  `-Q1` in any package, which is how the `TPS22918 → -Q1` temp-grade-up policy got silently
  dropped when U6 was briefly TPS22917.
- **C26/C27 low-profile: solved BY CASE SIZE, not by thinning 0805 — do not re-derive.** No vendor
  makes a 10 µF / 16 V / true-X7R 0805 under 1.40 mm max. C25–C27 are low-profile **1206** Murata
  GRM319 (0.95 mm max). The X7R→X5R trade is deliberate: no low-profile 10 µF true-X7R exists in
  ANY case size, and the supercaps cap the system at +85 °C — exactly X5R's window.
- Board electrically frozen; PCB change = brace reprint, not shell re-machine.
- **TWO LAYERS, 0.6 mm — locked 2026-08-10 after an adversarial re-examination. Cost is not the
  reason, and "a dedicated ground plane cuts noise" does not survive contact with this board.**
  The case for 4 layers is the standard one and it is sound in general. It fails here on three
  board-specific facts, two of which a general grounding principle cannot see:
  - **An inner plane sits IN THE LIGHT PATH.** `optical_window` is a copper keepout on **both**
    F.Cu and B.Cu — **144.9 mm², 3.2 % of the board** — because D2–D5 are on B.Cu and backlight
    the front monogram *through the bare FR4*. On 4 layers In1/In2 are physically between the LEDs
    and the monogram: copper there means no glow. So the plane cannot be both dedicated and
    continuous — it must carry the same **21.6 mm-wide slot across the middle of the card**, which
    forces every north–south return in that band to detour around it. That is the exact
    return-path discontinuity a ground plane exists to remove.
  - **It fights the antenna, and read range is an OPEN first-article gate.** The coil is on B.Cu
    and the board already spends ~**7 % of each face** holding copper off it (`NFC_COIL_KEEPOUT`
    317 mm², `NFC_COIL_POUR_KEEPOUT` 330 mm²). At 0.6 mm total, inner layers sit **0.1–0.2 mm**
    from the coil instead of 0.6 — worse coupling per unit area, on all four faces instead of two.
    Four layers does nothing for the energy budget and actively threatens the coil; those are the
    two gates the first article exists to close.
  - **There is no noise for it to fix — and it would UNDERMINE the isolation that is already
    there.** The fast content of this board is: an AVR at **1.25 MHz** on the internal oscillator
    (no crystal), I²C at ~**100 kHz**, LED PWM at ~16 mA, a megohm DC sense divider — and exactly
    one real source, the AEM10300's ≥10 MHz hash. That source is already handled by a LOCAL solid
    island (`GND_B_DCDC_SOLID`) plus the LDO's **moated** island with a single-point tie and a
    ferrite, whose whole purpose is to deny the hash a shared-copper path back in. A continuous
    inner plane would hand it a low-impedance path to everywhere. For a board with one fast
    circuit, local islands are the better topology, and they are built.

  **Manufacturing, secondarily:** 0.6 mm is locked, so 4 layers means ~0.1 mm dielectrics — a
  specialty tier, not a standard one, at all three fabs — and the triple-fab envelope
  (PCBWay ∩ OSH Park ∩ JLC, in `PCB/solar-glow-drh-v4_0.kicad_dru`) was derived against **2-layer**
  capability, so its drill/annular/spacing floors would need re-deriving. Selective hard gold
  narrows the vendor set again. This is re-opening the manufacturing envelope, not paying more for
  the same board. **Cost is the WEAKEST argument against it** — bare PCB is a small fraction of a
  build carrying hard gold, titanium and assembly; if 4 layers were technically right it would be
  worth buying.

  **Reopen only on a measurement, and all three are available from the first article:** an EMC
  pre-compliance failure traceable to ground (that item's measured half is still open); scope
  evidence of AEM switching hash on `VS` or `STO_SNS`; or the design acquiring a genuinely fast
  bus. A 10-card run is an INSTRUMENT — its job is to say what is actually wrong. Buying layers
  now is insurance against an unobserved failure, bought by degrading a function already known to
  be marginal.
- Enclosure STEP stays **analytic-sharp**: r1.0 internal corners are a DRAWING
  spec; do **not** enable `tool_relief` (produces a faceted STEP the fab rejects).
- East cavity lip pinched to 1.0 mm over y10–72 (NFC detune) — do not widen.
- NFC tuning at bring-up needs the brace **removable** — don't defeat it.
- Supercap footprints are a **hybrid**: SC1/SC3 = SS17 land (3-153-440, 39 mm), SC2/SC4 = WS17
  land (3-153-438, 28.5 mm); flat under-body pads, asymmetric widths = polarity key. The old REV-J diagonal-pad land is WRONG -- never reuse.
- Ti-6Al-4V (Grade 5); grounded M2 bosses tie the body to GND.
- **`U5` pin 7 (`VOUT`) stays UNCONNECTED — declined 2026-08-09 after an independent datasheet
  check, do not re-open without a bench number.** NFC energy harvesting was carried as a respin
  item; the arithmetic in it was right and the conclusion was still wrong, because the cost was
  never priced. **Harvesting current reduces read range** — NT3H2211 datasheet §8.6, verbatim:
  *"increasing the output current on Vout decreases the NFC communication range."* Read range is
  this card's scarcest resource: the coil sits behind a ferrite sheet inside a titanium shell, and
  the offline vCard read on a FLAT card (the entry above) is the one NFC function that must work.
  Trading it for a novelty flash, to unblock a feature (HOTP) that is itself parked, is backwards.
  The three engineering facts that finished the argument, all from the datasheet rather than from
  the item's summary of it:
  - **The VOUT capacitor is mandatory AND capped**: "typically 150 nF up to **220 nF maximum**
    … between VOUT and GND close to the terminals." So "give VOUT its own small reservoir" is not
    permitted as written — 220 nF at 2 V is 0.44 µJ, ~4000× short of one 1.8 mJ blink. A real
    reservoir has to sit behind isolation.
  - **A tap cannot even pay for the glow it triggers.** One glow costs **~0.4 J**
    (`firmware/sense.c:228`), so a full 15.14 J tank is only **38 glows**. A 1 s tap at the
    features-page 15 mW collects 15 mJ = **3.75 % of one glow**; at §8.6's realistic 10 mW it is
    2.5 %. That is **~27 taps to fund a single glow** (40 at the honest figure) — and the tap IS
    the actuator, so every harvest event triggers the spend that dwarfs it. Harvesting here is net
    negative by roughly thirtyfold. (The older "1000 taps to fill the tank" framing was true and
    too kind: it compared against the reservoir instead of against what the card actually does.)
  - **The harvested rail is at or below the LED's forward voltage.** VOUT is typically **2.0 V at
    5 mA** with a phone (§8.6; the "up to 15 mW" figure is the front-page feature bullet, and the
    electrical table's 3.3 V is at **1 mA** into a Class 5 antenna at 14 A/m). `LA P47F` VF is
    min 1.95 / typ 2.05 / max 2.55 V, and the LED path wants 16 mA. So "~8 blinks" needs a BOOST,
    not a reservoir — there is no headroom for a ballast resistor, and VOUT sources a third of the
    current. Buffering 1.8 mJ across those rails is ~1 mF behind a diode, on a frozen board.
  - **It is not one route.** U5's VCC is on `VNFC`, switched from VS by U6 under `NFC_EN`, and the
    datasheet requires VCC tied to VOUT if the tag is also to power the I²C bus — i.e. the flat-card
    case ties VOUT to a node a load switch also drives. That needs ORing/isolation, not a wire.

  Leaving the pin open is sanctioned by omission: the datasheet states no requirement for an unused
  VOUT (searched for "unused" / "left open" / "floating" — nothing), the 150–220 nF is a precaution
  for *operating in harvesting mode*, and ERC/DRC are clean on the unconnected net. **Reopen only
  on a measured read-range figure showing margin to spare** — never on the 15 mW headline.

- **NFC contact is offline-first.** The full vCard is **embedded** in the tag (`text/vcard`
  NDEF, `nfc.c`), read RF-powered by the phone with the card's supercap flat and **no
  reception** (the dead-signal courtroom case). A URL / App Clip is only ever an OPTIONAL
  rich-content extra -- **never** a dependency for the contact import. Do not swap the embedded
  vCard for a URL-only record.
- **Physical button — deliberately NOT fitted** (the accelerometer tap is the only actuator). This is
  a design decision, not a loose end. To add a hardware button in a future revision: route **pin 3
  (PA5)** to a momentary switch to **GND**; firmware reads it **active-low** (LOW = pressed) — `gpio_init`
  already enables PA5's internal pull-up. The schematic keeps a `BTN` label on PA5 as the on-board
  record of that pin; its lone-label ERC note is intentional. No power/analog net is affected.
- **Intentional / do-not-fix (so a future BOM/DRC pass doesn't re-flag them):** the R5/R6
  "VSENSE div" (and similar) value fields are deliberate house-style labels, not errors; the
  origin `NPTH_mech` footprint carries real non-plated mounting holes by design.

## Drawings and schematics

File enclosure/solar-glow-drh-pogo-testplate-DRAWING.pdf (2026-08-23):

## POGO TEST PLATE — top view, board coordinates (green: panel / card; red: probe bosses) Z stack / build notes

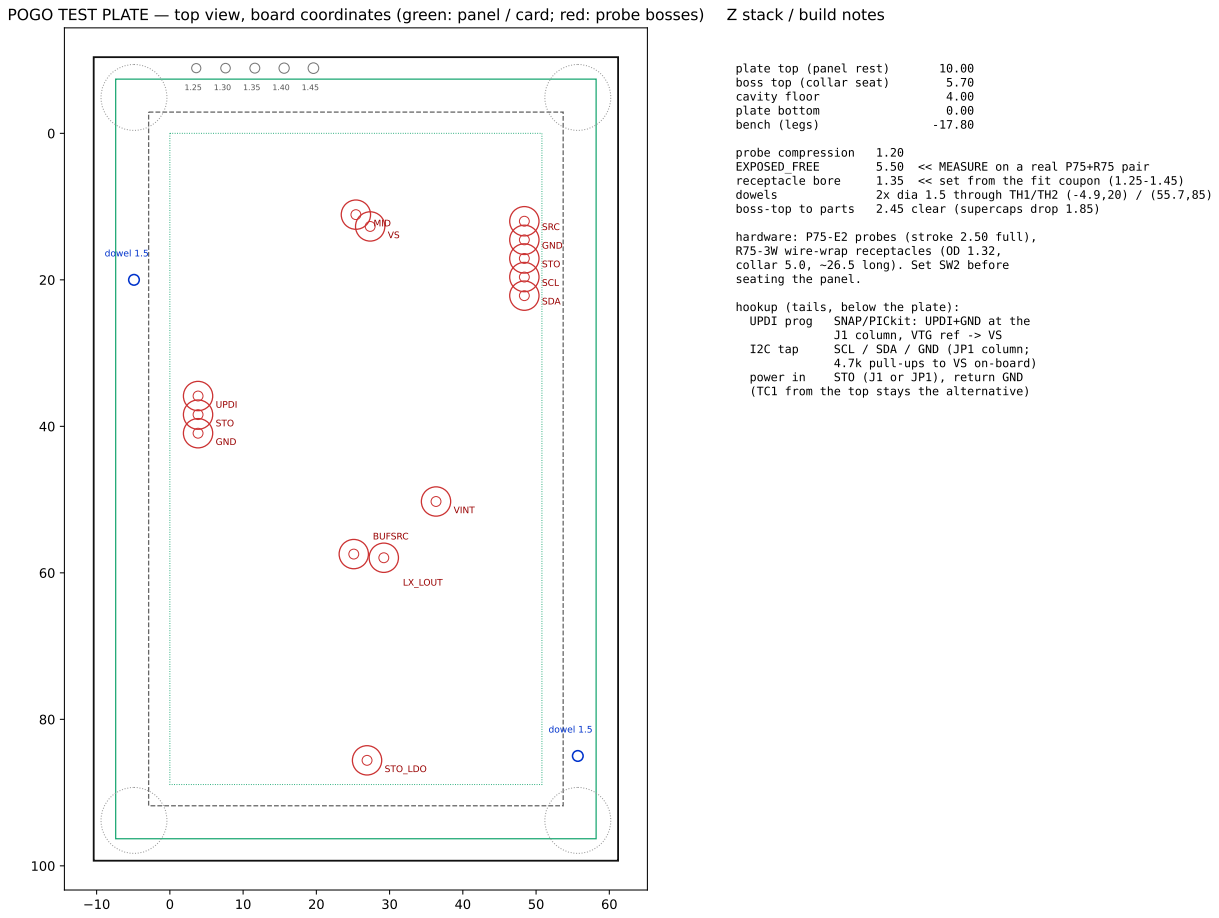
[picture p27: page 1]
VINT; UPDI; STO; GND; MID; LX_LOUT; SRC; BUFSRC; SCL; SDA; STO_LDO; dowel 1.5; plate top (panel rest); boss top (collar seat); cavity floor; plate bottom; bench (legs); probe compression; EXPOSED_FREE; << MEASURE on a real P75+R75 pair; receptacle bore; << set from the fit coupon (1.25-1.45); dowels; 2x dia 1.5 through TH1/TH2 (-4.9,20) / (55.7,85); boss-top to parts; 2.45 clear (supercaps drop 1.85); UPDI prog; SNAP/PICkit: UPDI+GND at the; I2C tap; SCL / SDA / GND (JP1 column;; power in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

hardware: P75-E2 probes (stroke 2.50 full),
R75-3W wire-wrap receptacles (OD 1.32,
collar 5.0, ~26.5 long). Set SW2 before
seating the panel.

hookup (tails, below the plate):

J1 column, VTG ref -> VS

4.7k pull-ups to VS on-board)

(TC1 from the top stays the alternative)

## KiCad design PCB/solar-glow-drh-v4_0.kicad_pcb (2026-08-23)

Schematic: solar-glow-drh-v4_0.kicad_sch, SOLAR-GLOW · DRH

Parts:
C1, C29: 100nF; C1; MPN GRT155R71H104KE01D
C3: 100nF; C3; MPN GRT155R71H104KE01D
C4, C13: 10uF; C_0603_1608Metric; MPN GRT188R61C106KE13D
C5: 100nF; C5; MPN GRT155R71H104KE01D
C6: 100nF; C6; MPN GRT155R71H104KE01D
C8: 100nF; C8; MPN GRT155R71H104KE01D
C9: 47pF; C_0603_1608Metric; MPN QSCP251Q470G1GV001T
C11: 220nF; C11; MPN GRT155R71C224KE01D
C12: 100nF; C12; MPN GRT155R71H104KE01D
C22: 1uF; C_0603_1608Metric; MPN GRT188R71E105KE13D
C23: 2.2uF; C_0603_1608Metric; MPN GRM188Z71E225ME43D
C24: 10nF; C1; MPN GRT155R71H103KE01D
C25: 22uF; C_1206_3216Metric_HS_LP085; MPN GRM319R61C226KE15D
C26, C27: 10uF; C_1206_3216Metric_HS_LP085; MPN GRM319R61E106KA12D
C28: 100nF; C_0402_1005Metric; MPN GRT155R71H104KE01D
C30: DNP-trim; C_0402_1005Metric; not fitted
D2: LA P47F; D2; MPN LA P47F-V2BB-24-3B5A-30-R18-Z
D3: LA P47F; D3; MPN LA P47F-V2BB-24-3B5A-30-R18-Z
D4: LA P47F; D4; MPN LA P47F-V2BB-24-3B5A-30-R18-Z
D5: LA P47F; D5; MPN LA P47F-V2BB-24-3B5A-30-R18-Z
FB1: ferrite; L_0603_1608Metric; MPN BLM18PG221SN1D
J1: UPDI hdr; J1; MPN (unpopulated header); not fitted
JP1: GND STO SCL SDA; JP1; MPN (bare pads - no part); not fitted
L2: 10uH; L_1008_2520Metric; MPN DFE252010F-100M=P2
MH1: M2; MH1; MPN (drill - no part)
MH2: M2; MH2; MPN (drill - no part)
MH3: M2; MH3; MPN (drill - no part)
MH4: M2; MH4; MPN (drill - no part)
PV1: SM141K06TF; PV1; MPN SM141K06TF
PV2: SM141K06TF; PV2; MPN SM141K06TF
Q2: DMG1012T; SOT-523; MPN DMG1012T-7
R5, R6, R15: 2M; R_0603_1608Metric; MPN MCT0603MD2004BP500
R14: 1M; R14; MPN AC0402FR-071ML
R16: 1M; R_0603_1608Metric; MPN MCT0603MD1004BP500
R17, R18: 1M; C1; MPN AC0402FR-071ML
RN1: 150R; R_Array_Convex_4x0402; MPN EXB-28V151JX
RN2: 4.7k; R_Array_Convex_2x0402; MPN EXB-24V472JX
SC1, SC3: SS17 1.8F 2.75V; SCHURTER_SCPC_SS17; MPN 3-153-440
SC2, SC4: WS17 1F 2.75V; SCHURTER_SCPC_WS17; MPN 3-153-438
SW2: LED master; SW2; MPN (PCB bridge - no part); not fitted
TC1, TC1/b1: Tag-Connect; TC1; MPN (no part - pogo footprint); not fitted
TP1: VIN; TP1; MPN (bare pad - no part); not fitted
TP2: VS; TPB; MPN (bare pad - no part); not fitted
TP3: MID; TPB; MPN (bare pad - no part); not fitted
TP4: LX_LOUT; TPB; MPN (bare pad - no part); not fitted
TP5: VINT; TPB; MPN (bare pad - no part); not fitted
TP6: BUFSRC; TPB; MPN (bare pad - no part); not fitted
TP7: STO_LDO; TPB; MPN (bare pad - no part); not fitted
U1: AVR64EA28 (VQFN28); U1; MPN AVR64EA28-E/STX
U3: ADXL367; ADXL367 CC-12-4_ADI; MPN ADXL367BCCZ-RL7
U5: NT3H2211; U5; MPN NT3H2211W0FHKH
U6, U10: TPS22916C; TPS22916_YFP0004; MPN TPS22916CYFPR
U7: MB85RC512TY; U7_DFN8; MPN MB85RC512TYPN-GS-AWEWE1
U8: AEM10300; U8_QFN28; MPN 10AEM10300C0000
U9: TPS7A0233PDQNR; Texas_X2SON-4_1x1mm_P0.65mm; MPN TPS7A0233PDQNR

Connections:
ANODE: C13.1, D2.A, D3.A, D4.A, D5.A, SW2.2
BTN: TC1.4, TC1/b1.4, U1.3 (PA5)
BUFSRC: C25.1, TP6.1 (1_1), U8.4 (BUFSRC)
CHG_DIS_G: Q2.1 (G), R18.1, U1.2 (PA4)
EN_STO_CH: Q2.3 (D), R17.2, U8.12 (EN_STO_CH)
FD: U1.4 (PA6), U5.4 (FD)
GND: C1.2, C3.2, C4.2, C5.2, C6.2, C8.2, C11.2, C12.2, C13.2, C22.2, C23.2, C24.2, C25.2, C26.2, C27.2, C28.2, C29.2, J1.3, JP1.1, MH1.1 (1_1), MH2.1 (1_1), MH3.1 (1_1), MH4.1 (1_1), PV1.N, PV1.Nt, PV2.N, PV2.Nt, Q2.2 (S), R6.2, R14.2, R16.2, R18.2, SC3.N, SC4.N, TC1.3, TC1/b1.3, U1.19 (GND), U1.25 (GND), U1.EP, U3.1 (SCLK), U3.3 (MISO/ASEL), U3.7 (GND), U3.8 (ADC_IN), U3.11 (GND), U5.2 (VSS), U6.B1 (GND), U7.1 (A0), U7.2 (A1), U7.3 (A2), U7.4 (VSS), U7.7 (WP), U8.3 (GND), U8.7 (GND), U8.8 (R_MPP2), U8.11 (R_MPP0), U8.18 (STO_CFG3), U8.19 (EN_HP), U8.21 (EN_STO_FT), U8.22 (T_MPP1), U8.25 (STO_CFG2), U8.27 (GND), U8.EP, U9.2 (GND), U9.5 (GND), U10.B1 (GND); also elsewhere on the board
INT1: U1.20 (PF0), U3.5 (INT1)
INT2: U1.21 (PF1), U3.6 (INT2)
K2: D2.K, RN1.2
K3: D3.K, RN1.1
K4: D4.K, RN1.3
K5: D5.K, RN1.4
LA: C9.1, C30.1, U5.1 (LA)
LB: C9.2, C30.2, U5.8 (LB)
LDRV1: RN1.7, U1.1 (PA3)
LDRV2: RN1.8, U1.28 (PA2)
LDRV3: RN1.6, U1.27 (PA1)
LDRV4: RN1.5, U1.26 (PA0)
LX_LIN: L2.1, U8.5 (LIN)
LX_LOUT: L2.2, TP4.1 (1_1), U8.6 (LOUT)
MID: SC1.N, SC2.N, SC3.P, SC4.P, TP3.1 (1_1), U8.13 (BAL)
NFC_EN: R14.1, U1.5 (PA7), U6.B2 (ON)
PC1: U1.7 (PC1)
SCL: JP1.3, RN2.3, TC1.5, TC1/b1.5, U1.9 (PC3), U3.4 (CS/SCL), U5.3 (SCL), U7.6 (SCL)
SDA: JP1.4, RN2.4, TC1.6, TC1/b1.6, U1.8 (PC2), U3.2 (MOSI/SDA), U5.5 (SDA), U7.5 (SDA)
SNS_EN: U1.6 (PC0), U10.B2 (ON)
SRC: PV1.P, PV1.Pt, PV2.P, PV2.Pt, R5.1, TP1.1 (1_1), U8.2 (SRC), U8.28 (CS_IN)
STO: C27.1, FB1.1, J1.2, JP1.2, SC1.P, SC2.P, SW2.1, TC1.2, TC1/b1.2, U8.14 (STO), U10.A2 (VIN)
STO_LDO: C22.1, FB1.2, TP7.1 (1_1), U9.3 (EN), U9.4 (IN)
STO_SNS: C24.1, R15.2, R16.1, U1.11 (PD1)
STO_SNS_PWR: R15.1, U10.A1 (VOUT)
UPDI: J1.1, TC1.1, TC1/b1.1, U1.23 (PF7/UPDI)
VDDIO2: C3.1, U1.10 (PD0)
VINT: C26.1, R17.1, TP5.1 (1_1), U8.9 (R_MPP1), U8.10 (VINT), U8.20 (T_MPP0), U8.23 (STO_CFG0), U8.24 (STO_CFG1)
VNFC: C8.1, U5.6 (VCC), U6.A1 (VOUT)
VREG: C11.1, U3.9 (VREG_OUT1)
VS: C1.1, C4.1, C6.1, C12.1, C23.1, C28.1, C29.1, RN2.1, RN2.2, TP2.1 (1_1), U1.18 (VDD), U1.24 (VDD), U3.10 (VS), U3.12 (VDDIO), U6.A2 (VIN), U7.8 (VDD), U9.1 (OUT)
VSENSE: C5.1, R5.2, R6.1, U1.12 (PD2)

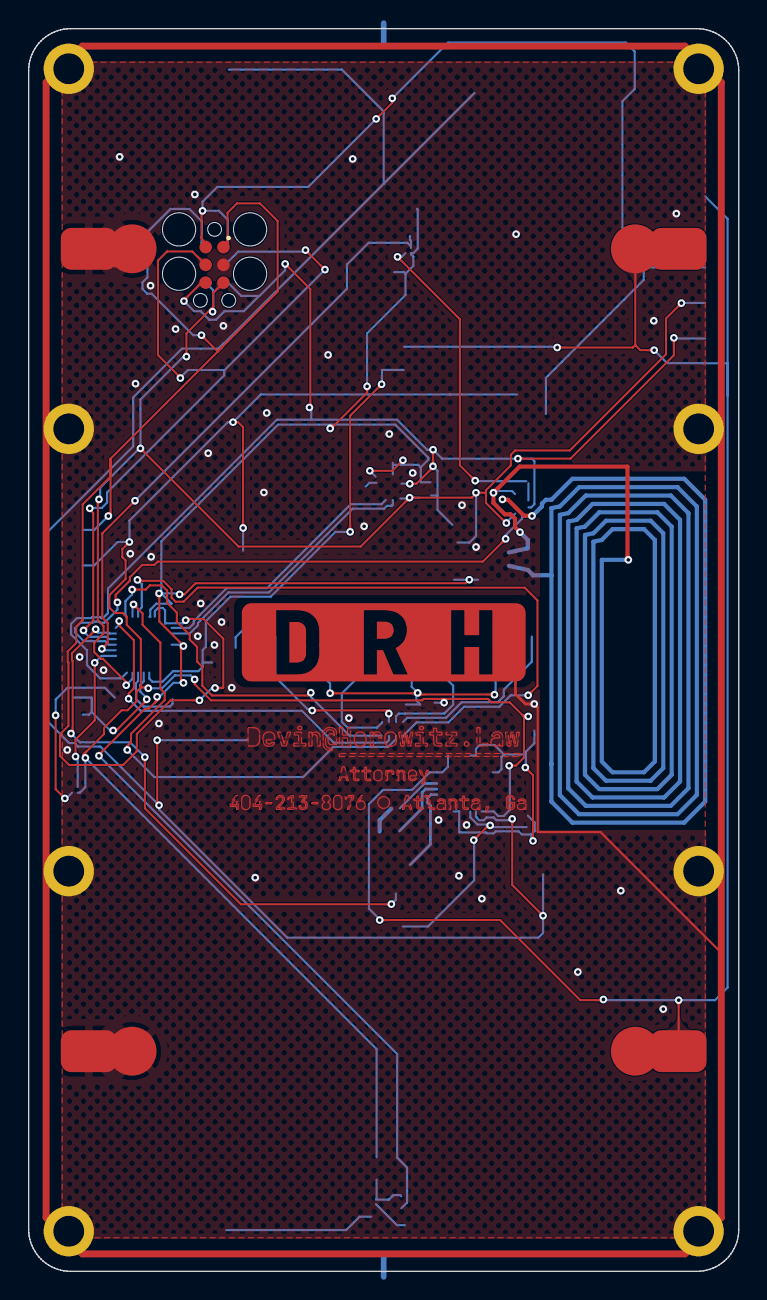
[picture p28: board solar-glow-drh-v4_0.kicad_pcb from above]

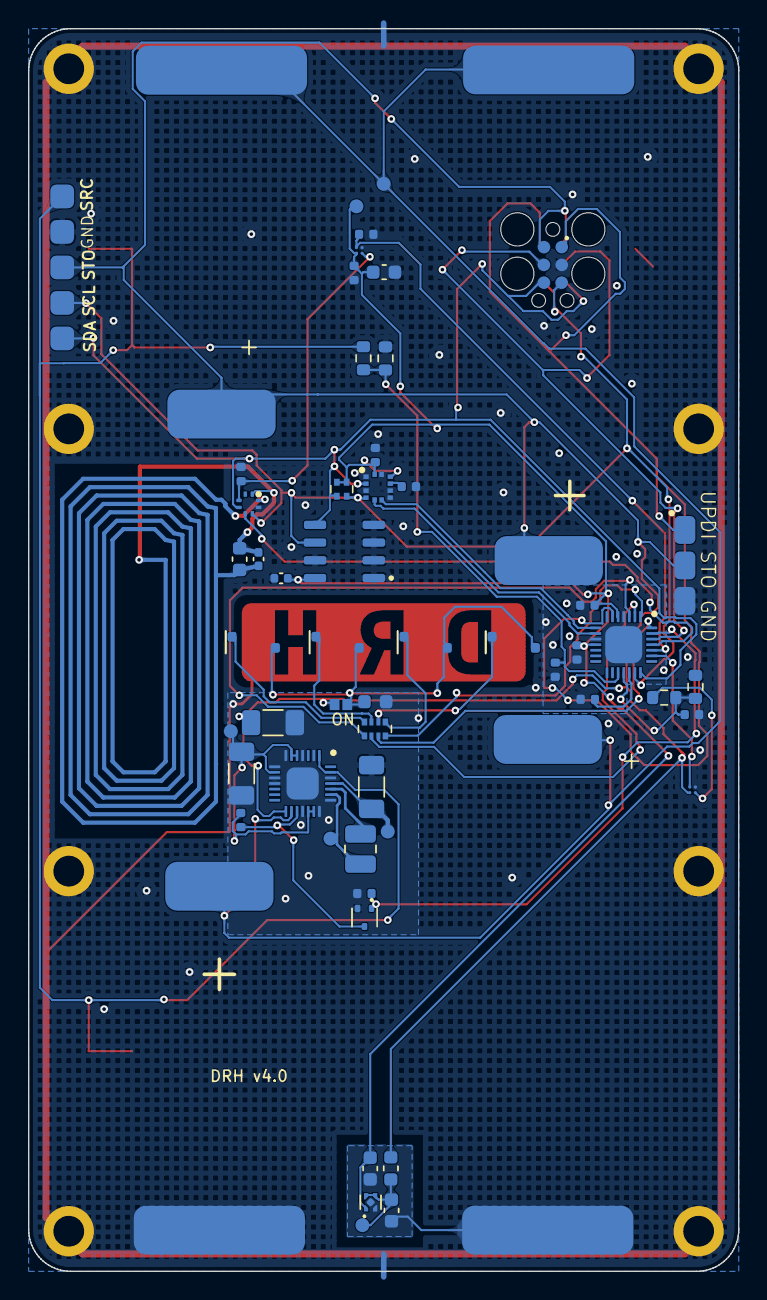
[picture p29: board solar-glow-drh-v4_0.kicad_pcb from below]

Board: 2 copper layers, 50.8 x 88.9 mm, 69 parts (58 on the bottom side), 38 nets.

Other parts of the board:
MP1, MP2, MP3, MP4: (no value)

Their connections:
GND: MP1.1 (1_1), MP2.1 (1_1), MP3.1 (1_1), MP4.1 (1_1); also elsewhere on the board

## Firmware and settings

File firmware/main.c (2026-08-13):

/*
 * main.c  --  SOLAR-GLOW DRH v4.0 firmware top level.
 *
 * Behaviour
 * ---------
 * The card sleeps in POWER-DOWN almost all the time. Four things wake it:
 *   - TAP      (ADXL367 tap -> INT1 -> PF0, rising)      -> full breathing glow
 *   - MOTION   (ADXL367 activity -> INT2 -> PF1, rising) -> one soft breath
 *   - NFC      (NT3H2211 field detect -> FD -> PA6, both edges) -> while the reader's
 *                field is present the LEDs are held dark (a clean 13.56 MHz band for the
 *                tag's reply) and the core stays quiet; the acknowledge glow fires when
 *                the field leaves (FD rising), rate-limited by USE_NFC_ACK_COOLDOWN so a
 *                parked, re-polling phone can't bleed the reserve breath by breath
 *   - PIT tick (RTC, ~1 s, runs in power-down)          -> sample light, and
 *                if we just crossed dark->light, do a glow
 * All of these pin interrupts sense fully asynchronously, so they wake the core
 * even with CLK_PER stopped (datasheet 18.3.3.1).
 *
 * The NFC tag (NT3H2211) is power-gated by NFC_EN (PA7) and OFF by default to kill
 * its ~195 uA idle draw; VCC is only switched on around an I2C access (provisioning).
 * FD-wake still works while VCC is gated off: the FD pin is operated from the
 * phone's own field power (datasheet 8.4), so a tap pulls PA6 low with the chip's
 * VCC off, and field-present is the chip's POR/config default (no I2C setup needed).
 * A phone also reads the static vCard via RF with VCC off.
 *
 * Every glow is gated by the rail-voltage floor: if the supercap is below
 * VS_GLOW_FLOOR_MV we stay dark and let it charge, so an animation can never
 * brown the part out mid-breath.
 *
 * Two hardware gates are invisible to this code and documented in the README:
 *   - SW2 (master anode switch): OFF -> no LED current, no matter what TCA does.
 *   - the accel itself is the only "button"; there is no GPIO button in v4.0.
 *
 * Bring-up order below follows hardware doc section 7 exactly.
 */
#include <avr/io.h>
#include <avr/interrupt.h>
#include <avr/sleep.h>
#include <avr/cpufunc.h>
#include <avr/wdt.h>      /* wdt_reset() == WDR; enable is via WDT.CTRLA below */

#include "board.h"
#include "twi.h"
#include "adxl367.h"
#include "led.h"
#include "sense.h"
#include "nfc.h"
#include "fram.h"

static volatile uint8_t f_tap;     /* PF0 click   */
static volatile uint8_t f_motion;  /* PF1 activity */
static volatile uint8_t f_tick;    /* RTC PIT     */
static volatile uint8_t f_nfc;     /* PA6 NFC field-detect (FD, field-powered) */
static volatile uint8_t f_fd_arrived;  /* FD fell since the last poll tick -- the held-field
                                        * backstop's arrival record (2026-08-01 pressure-test
                                        * fix): without it, a tick landing mid-read re-enabled
                                        * the DCDC the FD ISR had just quieted, because the
                                        * backstop tested only the instantaneous level while
                                        * its own comment promised "a full poll later". */

#if USE_FACEDOWN_DORMANT
/* face-down dormant state (main-context only, not shared with any ISR -> no volatile).
 * dormant = every glow suppressed until turned face-up; facedown_polls = consecutive
 * face-down polls counted toward FACEDOWN_DORMANT_POLLS. */
static uint8_t  dormant;
static uint16_t facedown_polls;
#endif

#if USE_DARK_DORMANT
/* dark dormant (the in-a-bag/pocket co-condition; board.h has the design). Orientation-
 * independent companion to face-down dormancy: continuously dark for DARK_DORMANT_POLLS
 * -> suppress the MOTION and NFC-ack glows outright, and rate-limit the TAP glow (a tap
 * always glows and ends dormancy, which must then be re-earned). Exits on any lit poll.
 * Main-context only. */
static uint8_t  dark_dormant;
static uint16_t dark_polls;          /* consecutive dark polls toward DARK_DORMANT_POLLS */
#endif

/* (A shipping/"coma" mode lived here for part of 2026-08-02 -- 48 h of dark dropping the
 * accel to standby, disabling the WDT and slowing the PIT to 32 s ticks. Removed: this card
 * is hand-delivered, so the dark-shipping-box premise never occurs, and a mode that changes
 * the poll rate, the watchdog and the accel's power state is a lot of failure surface to
 * carry for a scenario that does not happen. Dark dormancy above is the stowage answer that
 * does. See feature-roadmap.md for the full decision record.) */

/* ---------------- init ---------------- */

static void clocks_init(void)
{
    /* F_CPU = 1 MHz for low per-burst active draw (the core only runs in brief
     * bursts and sleeps through the glow). AVR-EA: OSCHF has NO runtime FRQSEL
     * (unlike the DD) -- the base frequency comes from the OSCCFG fuse
     * (OSCHFFRQ: 20 MHz default, 16 MHz fused) and CLK_PER is set by the main
     * prescaler. The fuse plan sets OSCHFFRQ = 16 MHz (see Makefile `fuses`),
     * so 16 MHz / 16 = exactly 1 MHz here. UNTIL that fuse is burned the base
     * is 20 MHz -> CLK_PER = 1.25 MHz: nothing breaks (TWI runs ~125 kHz, still
     * in every device's spec; delays run ~20% short), but burn the fuse before
     * trusting any timing-derived bench number. */
    _PROTECTED_WRITE(CLKCTRL.MCLKCTRLB, CLKCTRL_PDIV_DIV16_gc | CLKCTRL_PEN_bm);
    /* Timebase: CLK_PER cycles amounting to >= 1 us, used by the ADC's internal
     * start-up/settle sequencing (DS40002443 12.3.6). 2 covers both the fused
     * 1 MHz (2 us) and the pre-fuse 1.25 MHz (1.6 us); a too-large value only
     * lengthens the ADC start-up by microseconds. */
    _PROTECTED_WRITE(CLKCTRL.MCLKTIMEBASE, 2);
    /* (DD-era SLPCTRL.VREGCTRL PMODE tuning removed: the EA has no VREGCTRL --
     * its regulator manages sleep modes automatically.) */
}

static void gpio_init(void)
{
    /* accel interrupt inputs on PF0/PF1: input (default), rising-edge sense.
     * INT pads are push-pull active-high, so no pull resistor. */
    PORTF.PIN0CTRL = PORT_ISC_RISING_gc;   /* INT1 / tap      */
    PORTF.PIN1CTRL = PORT_ISC_RISING_gc;   /* INT2 / activity */
    /* NFC power-gate enable on PA7 (NFC_EN, active-HIGH): drive LOW = NFC VCC off.
     * Set OUT low first, then DIR out, so the pin never glitches HIGH. VCC is only
     * powered transiently around an I2C access (nfc_power_on/off). */
    NFC_EN_PORT.OUTCLR = NFC_EN_PIN_bm;
    NFC_EN_PORT.DIRSET = NFC_EN_PIN_bm;
    /* NFC field-detect on PA6: input, BOTH-edges sense. FD is field-powered
     * (datasheet 8.4), so it wakes us even with NFC VCC gated off; the chip's
     * POR/config default already pulls FD low on field-present, so no I2C setup is
     * needed. Both edges because we act on each: FALLING (field arrives) -> the LED
     * layer blanks and the core goes quiet for the read; RISING (field leaves) ->
     * fire the acknowledge glow. FD is open-drain; PA6's internal pull-up is the SOLE
     * hold (no external FD pull-up in the design) so the pin can't float, at the cost
     * of a little extra sink only while FD is held low. */
    FD_PORT.PIN6CTRL = PORT_ISC_BOTHEDGES_gc | PORT_PULLUPEN_bm;
    /* PD2 (VSENSE) is analog only: disable its digital input buffer so the
     * Schmitt trigger doesn't toggle (and burn current) on a slow mid-rail
     * analog level. ADC/AC read the analog path regardless of this bit. */
    PORTD.PIN2CTRL = PORT_ISC_INPUT_DISABLE_gc;
    /* LED pins + TCA routing are owned by led_init(); I2C pins by PORTMUX below. */
    PORTMUX.TWIROUTEA = PORTMUX_TWI0_ALT2_gc;   /* SDA=PC2, SCL=PC3 */

    /* Tie down every unused pin. A floating CMOS input draws shoot-through current
     * in its buffer whenever it drifts near mid-rail; a pull-up holds it high at ~0
     * current (and for PA5, the no-fit button pin whose future switch ties to GND, and the unrouted PC0/PC1 spares, that
     * is also the useful resting state). The pins configured above (PA6/PA7/PD2/PF0/
     * PF1) and the LED pins (PA0-3, in led_init) are left alone; a pull-up bit on a
     * driven output is ignored anyway. On the AVR-EA, PD0 IS bonded (pin 10 -- the
     * pad that was VDDIO2 on the DD28). The DD-era SJ1 strap is gone outright
     * (deleted from schematic and board 2026-07-30; was DNP before that), but the
     * pad is NOT bare: C3 (100 nF to GND, the DD-era VDDIO2 decoupler) still hangs
     * on its net. A capacitor defines no DC level, so the pull-up below is still
     * the required hold -- it just also charges C3 once at boot (~3.5 ms through
     * the ~26k pull). ("Floats / no external connection" here until the 2026-08-01
     * pressure test; C3 is a cull candidate for the next passives pass.)
     * PD3..PD7 exist on the 28-pin EA and are unused. */
    /* EN_STO_CH gate (PA4): push-pull drive of Q2, the low-side charge-disable buffer
     * (cold-start-deadlock fix -- board.h has the full story). Gate LOW at init = Q2 off =
     * AEM charging ENABLED (also the R18-pulled dead-MCU state, so init changes nothing
     * observable). The FD ISR raises it to quiet the DCDC during an NFC read. */
    ENSTOCH_PORT.OUTCLR = ENSTOCH_PIN_bm;    /* gate low = charging enabled */
    ENSTOCH_PORT.DIRSET = ENSTOCH_PIN_bm;    /* push-pull from here on */
    PORTA.PIN5CTRL = PORT_PULLUPEN_bm;   /* PA5/BTN no-fit button pin: pull-up is the active-low hold for a future PA5->GND switch */
    /* PC0 = SNS_EN, the STO sense-divider gate (U10). Output, driven LOW = divider
     * disconnected. No pull-up: it is a driven output now, and U10's own smart pulldown
     * covers the window where this pin tristates during reset/UPDI. */
    SNS_EN_PORT.OUTCLR = SNS_EN_PIN_bm;
    SNS_EN_PORT.DIRSET = SNS_EN_PIN_bm;
    PORTC.PIN1CTRL = PORT_PULLUPEN_bm;   /* PC1 spare, unrouted */
    PORTD.PIN0CTRL = PORT_PULLUPEN_bm;   /* PD0/3-7 unused      */
    PORTD.PIN1CTRL = PORT_ISC_INPUT_DISABLE_gc;   /* PD1 = AIN1 STO_SNS analog in (R15/R16 divider) */
    PORTD.PIN3CTRL = PORT_PULLUPEN_bm;
    PORTD.PIN4CTRL = PORT_PULLUPEN_bm;
    PORTD.PIN5CTRL = PORT_PULLUPEN_bm;
    PORTD.PIN6CTRL = PORT_PULLUPEN_bm;
    PORTD.PIN7CTRL = PORT_PULLUPEN_bm;
    PORTF.PIN6CTRL = PORT_PULLUPEN_bm;   /* PF6/RST: input-only GPIO (RSTPINCFG=0), no external net -- hold it */
}

/* PIT period selectors, named once so rtc_pit_init() and the face-down deep-sleep
 * transition cannot drift apart. The PIT runs off the 1.024 kHz ULP oscillator, so
 * the cycle count IS the period in units of ~0.977 ms; CYC1024 ~ 1 s. */
#if   POLL_PERIOD_S == 1
#  define NORMAL_PIT_gc  RTC_PERIOD_CYC1024_gc      /* 1024 / 1.024 kHz = 1.0 s */
#elif POLL_PERIOD_S == 2
#  define NORMAL_PIT_gc  RTC_PERIOD_CYC2048_gc      /* 2048 / 1.024 kHz = 2.0 s */
#else
#  error "POLL_PERIOD_S must be 1 or 2 (RTC PIT poll period, seconds)."
#endif

#if USE_FACEDOWN_DEEPSLEEP
#  if   FACEDOWN_POLL_S == 2
#    define FACEDOWN_PIT_gc  RTC_PERIOD_CYC2048_gc
#  elif FACEDOWN_POLL_S == 4
#    define FACEDOWN_PIT_gc  RTC_PERIOD_CYC4096_gc
#  elif FACEDOWN_POLL_S == 8
#    define FACEDOWN_PIT_gc  RTC_PERIOD_CYC8192_gc
#  else
#    error "FACEDOWN_POLL_S must be 2, 4 or 8 -- and <= the ~8 s watchdog period, which stays armed."
#  endif
#  if FACEDOWN_POLL_S < POLL_PERIOD_S
#    error "FACEDOWN_POLL_S below POLL_PERIOD_S would make the OFF state poll FASTER than normal."
#  endif
#endif

static void rtc_pit_init(void)
{
    /* 1.024 kHz internal ULP clock (runs in power-down). Period from the
     * POLL_PERIOD_S knob so the config actually takes effect. */
    RTC.CLKSEL = RTC_CLKSEL_OSC1K_gc;
    while (RTC.PITSTATUS & RTC_CTRLBUSY_bm) { }
    RTC.PITINTCTRL = RTC_PI_bm;
    RTC.PITCTRLA = NORMAL_PIT_gc | RTC_PITEN_bm;
}

#if USE_FACEDOWN_DEEPSLEEP
/* Enter/leave the face-down low-power profile -- the card's off switch. board.h's
 * USE_FACEDOWN_DEEPSLEEP block has the reasoning and the numbers; these are the two
 * transitions, and they must stay exact mirrors of each other or the card comes back
 * from face-down in a half-configured state. */
static void facedown_deepsleep(uint8_t on)
{
    if (on) {
        /* CHARGING FIRST, and this ordering is load-bearing. The FD ISR is what
         * re-enables the AEM after a read (gate LOW = charging on), and we are about
         * to stop servicing FD edges entirely. If a reader's field happened to be
         * present as dormancy began, the gate would be HIGH and nothing would ever
         * lower it -- a card that has quietly stopped harvesting for as long as it
         * lies face-down, which is the exact opposite of what this mode is for.
         * Force it on before the pin goes deaf. */
        ENSTOCH_PORT.OUTCLR = ENSTOCH_PIN_bm;
        FD_PORT.PIN6CTRL = PORT_ISC_INPUT_DISABLE_gc;   /* pull-up + buffer off: kills the FD leak */
        FD_PORT.INTFLAGS = FD_PIN_bm;                   /* drop any edge latched on the way down */
        f_nfc = f_fd_arrived = 0;
        adxl367_lowpower(1);                            /* 12.5 Hz, tap engine off */
        while (RTC.PITSTATUS & RTC_CTRLBUSY_bm) { }
        RTC.PITCTRLA = FACEDOWN_PIT_gc | RTC_PITEN_bm;
    } else {
        while (RTC.PITSTATUS & RTC_CTRLBUSY_bm) { }
        RTC.PITCTRLA = NORMAL_PIT_gc | RTC_PITEN_bm;
        adxl367_lowpower(0);                            /* back to 100 Hz + tap */
        FD_PORT.PIN6CTRL = PORT_ISC_BOTHEDGES_gc | PORT_PULLUPEN_bm;
        FD_PORT.INTFLAGS = FD_PIN_bm;                   /* re-enabling the pull-up lifts the pin;
                                                         * that edge is our own doing, not a field */
        f_nfc = f_fd_arrived = 0;
    }
}
#endif

/* ---------------- sleep ---------------- */

static void go_to_sleep(void)
{
    /* NFC_EN MUST be LOW before any sleep: cut the tag's VCC so it cannot draw its
     * ~195 uA across the sleep. (After provisioning it is already off; this is the
     * hard guarantee of the invariant.) */
    nfc_power_off();
    /* Power-Down is the baseline: lowest current. It still wakes on the accel pin
     * interrupts and the RTC PIT -- and on FD (PA6), which the phone's field drives
     * even though we just cut the tag's VCC (FD is field-powered, datasheet 8.4). */
    slp_set_mode(SLEEP_MODE_PWR_DOWN);
    cli();
    if (!f_tap && !f_motion && !f_tick && !f_nfc) {
        slp_enable();
        sei();              /* SEI + SLEEP is atomic: a pending IRQ runs after SLEEP, no missed wake */
        sleep_cpu();
        slp_disable();
    } else {
        sei();
    }
}

/* ---------------- FRAM archival hook (default OFF; see USE_FRAM_LOG) ---------------- */

#if USE_FRAM_LOG
/* Cold-boot counter in the FRAM "black box" (U7, 64 KB on always-on VS -- this
 * line said VNFC, the pre-2026-07-23 rail, until the 2026-08-01 pressure test;
 * the same paragraph already had it right below). FeRAM has ~1e13
 * write endurance and commits with no settle delay, so -- unlike the 512 B internal-
 * EEPROM loggers -- a plain read-modify-write needs no wear or corruption-window
 * guard. Record layout at addr 0: [0..3] magic 'DRHb', [4..7] big-endian boot count;
 * an absent magic (virgin / garbage FRAM) re-seeds the record at 1. Gated behind
 * USE_FRAM_LOG because archival policy still waits on the unmeasured harvest
 * budget (README "the open question") -- though the cost is now just a wake
 * (~450 us) + bus time, the part riding always-on VS since the back-power fix.
 * This is the integration scaffold: richer per-event archival hangs off the same
 * wake/read/write/sleep cycle once the budget is bench-measured. */
/* Record layout at addr 0. v1 was magic 'DRHb' + a boot count and nothing else; v2 is
 * 'DRHc' and appends four lifetime event counters. A v1 record is MIGRATED rather than
 * overwritten -- any card already carrying boot counts keeps them, and the new fields
 * start at zero. That matters because this is the black box: its whole value is that it
 * has been counting since the board's first power-up.
 *
 *   [ 0.. 3] magic 'DRHc'
 *   [ 4.. 7] cold boots        u32 BE     (v1 field, preserved across the migration)
 *   [ 8..11] taps              u32 BE
 *   [12..15] double taps       u32 BE
 *   [16..19] NFC field reads   u32 BE
 *   [20..23] motion trips      u32 BE
 */
#define REC_LEN     24
#define EV_TAP       0
#define EV_DBL       1
#define EV_NFC       2
#define EV_MOTION    3
#define EV_N         4
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
int main(void)
{
    uint8_t prev_light = 0;
#if USE_NFC_ACK_COOLDOWN
    uint8_t nfc_cooldown = 0;   /* polls remaining before another NFC-ack glow may fire (0 = ready) */
#endif

    clocks_init();        /* 1. clocks / power            */
    gpio_init();          /* 2. GPIO / PORTMUX            */
    led_init();
    sense_adc_init();
#if USE_HEALTH_LOG
    sense_boot_log();     /* black box: +1 the power-cycle count if this was a cold power-on (POR) */
#endif

    twi_init();           /* 3. I2C up, talk to the accel */
    /* Retry-once on a failed accel bring-up (2026-08-12; the ASIC experiment's init_seq
     * had to define this terminal state explicitly, which exposed that the firmware
     * computes the same failure -- rc across the DEVID check and all fourteen config
     * writes -- and then threw it away with a (void) cast. This failure class has
     * already bitten once: the pre-2026-08-02 reset-latency bug produced exactly "a
     * boot that reported success" with the tap engine dead (see adxl367_init_tap's
     * 7.5 ms comment). The latency root cause is fixed; this is the missing layer that
     * would have CAUGHT it. One retry covers the transient causes (a marginal rail
     * during the first I2C burst, a glitched ack); a part that fails twice is absent
     * or broken, and the card boots anyway -- NFC still serves the vCard and the
     * stuck-INT backstop keeps polling -- it just cannot be tapped awake, same as
     * before this check existed. Deliberately NO EEPROM record here: a boot-path
     * EEPROM write from a possibly-collapsing rail is the corruption window the
     * health log exists to avoid (it defers commits off a low rail for this reason). */
    if (adxl367_init_tap())
        (void)adxl367_init_tap();

#if USE_FRAM_LOG
    fram_boot_record();   /* archival black box: bump the cold-boot counter (wakes + re-parks U7) */
#else
    fram_sleep();         /* POWER-CRITICAL even headless: U7 rides always-on VS and cold-boots
                           * into STANDBY (10 uA typ / 150 uA MAX) -- park it in SLEEP (0.20 uA
                           * typ) or it silently out-draws the whole standby budget. */
#endif

    /* 4. NFC tag (shares the bus) is power-gated OFF by default; we do not touch it
     * at boot. FD-wake needs no setup -- it runs on field power and the chip's POR
     * default already pulls FD low on field-present. Provisioning, when enabled,
     * powers VCC on for the write and back off after (nfc_provision_default). */
#if NFC_PROVISION
    (void)nfc_provision_default();   /* one-shot NDEF write; self-powers the tag */
#endif

    rtc_pit_init();       /* 5/6. baseline poll + housekeeping clock */

    /* the accel INT lines were indeterminate until configured just above; drop
     * any edge they may have latched into PORTF before we arm interrupts. Same for
     * any FD edge on PORTA (PA6). */
    PORTF.INTFLAGS = ACC_INT1_bm | ACC_INT2_bm;
    FD_PORT.INTFLAGS = FD_PIN_bm;
    /* ... and only THEN re-clear the accel's own event latches. Order matters:
     * adxl367_init_tap()'s trailing clears ran BEFORE the flag clear above, so a
     * real tap in between would sit latched (the ADXL367 holds INTn HIGH until
     * STATUS is read) with its one PF0 rising edge just discarded -- no new edge
     * would ever come and tap wake would be dead until the next reset. This
     * second STATUS/STATUS_2 read releases any such latch; a tap from here on
     * lands a fresh edge in the already-cleared INTFLAGS and is served normally
     * once sei() arms the ISRs. (Cost: two I2C byte reads, boot-only.) */
    adxl367_clear_tap();
    adxl367_clear_activity();
    f_tap = f_motion = f_tick = f_nfc = 0;

#if USE_WDT
    /* arm the watchdog last, once the slow bring-up (I2C config) is done so it
     * cannot trip during init. CTRLA is CCP-protected. ~8 s >> poll and glow. */
    _PROTECTED_WRITE(WDT.CTRLA, WDT_PERIOD_8KCLK_gc);
    wdt_reset();
#endif

    sei();

    /* power-on wink so a freshly programmed card shows life. Gated on a margin
     * above the glow floor (WINK_FLOOR_MV), not the floor itself, so a marginal
     * just-charged card cannot wink itself back below the floor.
     * The PEAK goes through sense_glow_peak() like every other animation, so the
     * ballast guard covers this one too. It did not until 2026-08-02: the wink
     * passed a raw GLOW_PEAK, which made "every glow's peak passes through that
     * chokepoint" false for the one glow that fires with the tank at its fullest
     * -- straight off a programmer or a bench supply, exactly the over-voltage
     * case USE_BALLAST_GUARD exists for. Costs one extra STO read at boot;
     * WINK_FLOOR_MV (3000) still gates whether the wink fires at all, since it is
     * a stricter floor than sense_glow_peak's own VS_GLOW_FLOOR_MV (2750). */
    if (sense_vdd_mv() >= WINK_FLOOR_MV) {
        uint8_t wink = sense_glow_peak(GLOW_PEAK);
        if (wink)
            led_breathe(1, GLOW_BREATH_MS, wink);
    }

    /* seed the dark->light detector with the actual boot light level, so a card
     * powered on already in light does not fire a phantom dark->light glow on the
     * first PIT tick (the wink above is the only intended power-on glow). */
    prev_light = sense_light();
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

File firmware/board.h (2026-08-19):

/*
 * board.h  --  SOLAR-GLOW DRH v4.0  as-built pin/route map.
 *
 * Single source of truth = the committed solar-glow-drh-v4_0.kicad_pcb
 * (pad -> pinfunction -> net read directly from the board) cross-checked
 * against solar-glow-drh-v2-hardware.md and the AVR64EA28 datasheet
 * (DS40002443). Every PORTMUX/peripheral value below is the value the
 * physical routing requires, not a default.
 *
 * MCU: AVR64EA28, 28-pin VQFN, on the BACK of the board. (v4 family swap from
 * the AVR64DD28: 27/28 pads identical; TWI ALT2, TCA0-on-PORTA, and the
 * PD1/PD2 analog inputs all carry over -- see design-notes 5 addendum.)
 *
 *   pad pinfunc  net      role
 *    26 PA0      LDRV4    LED D5 low-side drive    TCA0 WO0
 *    27 PA1      LDRV3    LED D4                   TCA0 WO1
 *    28 PA2      LDRV2    LED D3                   TCA0 WO2
 *     1 PA3      LDRV1    LED D2                   TCA0 WO3
 *     2 PA4      CHG_DIS_G  Q2 gate: low-side charge-disable buffer (push-pull, HIGH = disable; R18 holds charge ON when MCU dead)
 *     3 PA5      BTN      button pin -- deliberately NO-FIT; a future button = PA5->switch->GND (active-low)
 *     4 PA6      FD       NFC field-detect in (NT3H2211)  FD-wake, both edges; field-powered (works VCC-off)
 *     5 PA7      NFC_EN   NFC VCC load-switch enable (active-HIGH)  output, LOW = NFC off
 *     6 PC0      SNS_EN   STO sense-divider gate (U10 ON, active-HIGH)  output, LOW = divider off
 *     7 PC1      PC1      spare GPIO  -- deliberately unrouted, no breakout
 *     8 PC2      SDA      TWI0 host SDA  (TWIROUTEA=ALT2)  ext 4.7k to VS
 *     9 PC3      SCL      TWI0 host SCL  (TWIROUTEA=ALT2)  ext 4.7k to VS
 *    10 PD0      VDDIO2   EA GPIO on the old VDDIO2 pad; SJ1 deleted 2026-07-30 (DNP before that), but C3 (100 nF -> GND, the DD-era decoupler) still hangs on the net -- no DC hold, so the internal pull-up (gpio_init) is still required; it just also charges C3 at boot
 *    11 PD1      STO_SNS    supercap-state sense  AIN1 (STO via R15/R16 divide-by-3)
 *    12 PD2      VSENSE   light sense (now SRC) + rail  AIN2 (ADC) + AINP0 (AC0+)
 *    18 VDD      VS       regulated 3.3 V LDO output (U9 TPS7A0233, STO->VS)
 *    19 GND      GND
 *    20 PF0      INT1     accel INT1 in  (PORTF pin interrupt)
 *    21 PF1      INT2     accel INT2 in  (PORTF pin interrupt)
 *    23 UPDI     UPDI     program (TC2030 pad TC1 / header J1)
 *    24 VDD      VS
 *    25 GND      GND
 *    EP          GND
 *
 * LED channel map (D1/D9/D10/D11 Schottkys removed in v4; only D2..D5 remain):
 *   D2->LDRV1->PA3/WO3 ; D3->LDRV2->PA2/WO2 ; D4->LDRV3->PA1/WO1 ; D5->LDRV4->PA0/WO0
 *   each LED: anode->ANODE common->SW2->STO (ON; bridge open = OFF) ; cathode->Kn->RN1 element->LDRV net->pin (see map above).
 *   RN1 is the 4x150R array that replaced discrete R1-R4 (2026-08-07): elements pair pins 1-8/2-7/3-6/4-5,
 *   wired so every K meets its documented LDRV -- the channel map above is unchanged.
 */
#ifndef BOARD_H
#define BOARD_H

#include <avr/io.h>

/* ---- main clock: internal OSCHF at 1 MHz, no crystal fitted ---- */
#ifndef F_CPU             /* the Makefile passes -DF_CPU; guarded so that knob actually
                           * works (unguarded, overriding it warned in every TU -- a hard
                           * FAIL under CI's -Werror -- and split delay calibration across
                           * files by include order; 2026-08-01 pressure test) */
#define F_CPU 1000000UL   /* OSCHF run frequency; see clocks_init in main.c */
#endif

/* ---- LEDs (low-side sink) on PORTA PA0..PA3 = TCA0 WO0..WO3 ----
 * TCA0 split: WO0..WO2 driven by LCMP0..2 (low timer), WO3 by HCMP0 (high timer).
 * PORTMUX.TCAROUTEA = PORTMUX_TCA0_PORTA_gc (0x00): WO0..WO3 land on PA0..PA3. */
#define LED_PORT        PORTA
#define LED_PA0_bm      PIN0_bm   /* LDRV4 / WO0 / LCMP0 */
#define LED_PA1_bm      PIN1_bm   /* LDRV3 / WO1 / LCMP1 */
#define LED_PA2_bm      PIN2_bm   /* LDRV2 / WO2 / LCMP2 */
#define LED_PA3_bm      PIN3_bm   /* LDRV1 / WO3 / HCMP0 */
#define LED_ALL_bm      (LED_PA0_bm | LED_PA1_bm | LED_PA2_bm | LED_PA3_bm)

/* ---- accel interrupt inputs on PORTF (no crystal -> PF0/PF1 are GPIO) ---- */
#define ACC_PORT        PORTF
#define ACC_INT1_bm     PIN0_bm   /* PF0 <- ADXL367 INT1 (tap, single+double) */
#define ACC_INT2_bm     PIN1_bm   /* PF1 <- ADXL367 INT2 (activity/motion)    */

/* ---- light/rail sense on PD2 ----
 * VSENSE = VIN/2 (R5/R6 = 1M each, C5 = 100nF). ADC sees ~VIN/2; x2 = VIN.
 * PD2 = AIN2 (ADC MUXPOS 0x02) and AINP0 (AC0 MUXPOS 0x00). */
#define VSENSE_AIN          ADC_MUXPOS_AIN2_gc        /* 0x02 */
#define VSENSE_DIVIDER      2                          /* VIN = VSENSE * 2   */
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

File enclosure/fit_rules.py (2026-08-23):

#!/usr/bin/env python3
"""The fit rules for the enclosure: ONE home for the geometry both generators obey.

WHY THIS IS A MODULE AND NOT TWO COPIES

The brace and the shell each decide where they may put material, and both decisions are a
function of the same thing: where the parts actually are. When those rules lived inside the
two generators as literal rectangles and four scalar lip widths, they went stale against the
board independently and neither knew:

  * the brace's middle band was sized for supercap bays ending at y31.15/57.75 -- the 28.5 mm
    WS17 length -- while SC1/SC3 are 39 mm SS17 cells, so the brace put 593 mm3 of solid
    resin inside three 1.70 mm cans in a 1.80 mm cavity and could not be installed;
  * the shell's lip landed on nine B-side parts including 4.17 mm2 of LIVE pad under
    grounded titanium, shorting the storage rail on assembly;
  * five of eight M2 bosses fouled a part, two on live nets;
  * and the shell's own comment asserted "R14 y0 31.44" about a part that sits at y4.92.

So the rules live here, the generators import them, and check_consistency [8] asserts the
invariants against these same functions rather than a third copy. A part that moves now
changes the enclosure instead of silently colliding with it.

WHAT THE RULES ARE

  BRACE   A part can be COVERED (pocketed) only if the resin left above it still prints:
          web = GAP - (h + AIR) >= SLA_WEB, i.e. h <= SPAN_LIMIT. Anything taller is a
          BLOCKER and is subtracted from the footprint instead of pocketed. Interference is
          therefore structurally impossible: what would collide is what gets removed.

  LIP     Per band, per edge, backed off LIP_CLR from the nearest part body-or-pad, and
          never overhanging the NFC coil. Wide wherever nothing is in the way, because it
          supports a 0.60 mm board.

  BOSS    The r2.60 disc with any fouling part cut out of it, which costs almost no thread:
          the worst case keeps 92.4% of the r0.80..r2.60 annulus.
"""
from __future__ import annotations

import os
import sys

from shapely.geometry import box, Point, Polygon
from shapely.ops import unary_union

HERE = os.path.dirname(os.path.abspath(__file__))
sys.path.insert(0, HERE)
from board_parts import parts as board_parts   # noqa: E402

# ---- board / cavity -------------------------------------------------------------------
W, H = 50.80, 88.90
BOARD_TH = 0.60
TOOL_R = 1.0               # dia 2.0 finisher -> R1.0 internal corners
CAP_AIR = 0.10             # air over the CAVITY-SETTING parts (the caps in max; the shell
                           # CAD's cav_margin was this same number restated -- collapsed
                           # here 2026-08-07, the CAVITY-two-homes fix)

# CAVITY is DERIVED, never hand-written. Until 2026-08-07 this line read `CAVITY = 1.80`
# -- a literal copy of part_heights.SUPERCAP_H + 0.10 that agreed with the shell CAD's own
# independent derivation only numerically. The duplicate-constant class that produced the
# 0.1838 mm mount-pattern failure, one file over. The import is the fix.
from part_heights import SUPERCAP_H as _SUPERCAP_H, SUPERCAP_H_THIN as _SUPERCAP_H_THIN  # noqa: E402
CAVITY = round(_SUPERCAP_H + CAP_AIR, 2)      # 1.80 -- the MAX variant, cap-limited

# ---- brace ----------------------------------------------------------------------------
GAP = CAVITY               # the brace fills the cavity

# ---- the ferrite behind the NFC coil (Wurth WE-FSFS 364006, FER1) ----------------------
# Moved here 2026-08-03 so it has ONE home, the same rule the rest of this file exists for.
# It was declared in the brace CAD and copied verbatim into the brace DRAWING-gen; the
# assembly render now needs it too, and a third copy is how the first two stop agreeing.
# The brace CAD is not importable (no __main__ guard -- it builds and exports at import),
# so "import it from where it already lives" was not available; this is where it belongs.
#
# The pocket is on the BOARD-FACING face of the brace, so the sheet is sandwiched between
# the brace and the PCB's B-side, directly under the coil.
FER = (36.9, 31.5, 48.9, 57.5)   # x0,y0,x1,y1 -- 12 WIDE (x, CRITICAL, edge-limited) x 26 LONG
FER_T = 0.38                     # OVERALL stack per DK 732-5049-ND (ferrite + PET + PSA)
FER_POCKET_DEPTH = FER_T - 0.05  # 0.33 -- sheet sits ~0.05 proud and seats flush when clamped
FER_CLR = 0.20                   # channel wall clearance on the critical 12 mm width
AIR = 0.22                 # air over a covered part. 0.12 until 2026-08-02 -- that cleared the
                           # TYPICAL assembly stack but not the corner: body-height tol (+-0.10
                           # worst class) + solder standoff (~0.075; part_heights measures the
                           # 3D models, which seat at zero standoff) + resin pocket depth
                           # (+-0.10) RSS to ~0.16. 0.22 covers the RSS stack with margin;
                           # scripts/interference_drc.py carries the same stack as WC_STACK and
                           # reports the worst-case column. If first-article glow suffers from
                           # the diffuser sitting 0.1 farther off D2-D5, the rollback lever is a
                           # per-part AIR exception for the LEDs, not a global revert.
# Per-part AIR exceptions (2026-08-02). D2-D5 will be OPTICALLY GEL-COUPLED to the
# diffuser: an index-matched fill eliminates the air interface, so gap THICKNESS stops
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

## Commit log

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2026-07-06 docs: reconcile all docs against the committed v3.0 board
    Cross-referenced the full doc set against the KiCad board/schematic/BOM and ironed out drift accumulated across revisions:
    - Board thickness 0.8 -> 0.6 mm everywhere stated as current (committed stackup is 0.6 mm; the enclosure was rebuilt around it).
    - Rail clamp TLV431 -> TLV3011, trip 3.47 -> 3.60 V worst-case / ~3.50 typ (matches the as-built R7=6.81M / R8=3.74M divider).
    - PCB BOM: U3 LIS2DH12 -> ADXL367; R7 1.8M -> 6.81M; R8 split out to 3.74M (the old 1.8M/1.0M would have mis-set the clamp).
    - Enclosure 0.75 floor / 1.85 cavity -> 1.00 / 1.80 (0.95 under U2), ribs -> resin diffuser brace, per the committed dumb-box shell.
    - Del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
    [board.h]
2026-07-06 ci: consistency check scans every doc for .kicad_* references
    Previously only README/firmware-README/board.h were scanned; this audit found stale file pointers in design-notes and the v2-* docs that the check missed. Now globs all *.md so any deleted-file reference fails loudly.
    [check_consistency.py]
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2026-07-06 sch: enrich component fields (datasheet, MPN, description) from the BOM
    All 63 components: Datasheet -> renamed file, new MPN field, filled Description. ERC 0 errors and the pin-map consistency check still passes -- metadata only, connectivity untouched.
    [solar-glow-drh-v3_0.kicad_sch]
2026-07-06 bom, sch: correct 4 items from PCBWay assembly review (T-H70W567099A)
    R7 Manufacturer had a stray old part number (RC0402FR-071M82L) instead of Yageo. D2-D5 package corrected to SMD 3.4x1.9 mm. C11 MPN -> GRM155R71C224KA12D (0.22uF 16V X7R 0402). C13 MPN -> GRM155R61A475MEAAD (4.7uF 10V X5R 0402). Both cap MPNs DigiKey-verified in stock. Applied to both BOM .xlsx and the schematic; ERC 0, consistency passes.
    [solar-glow-drh-v3_0-BOM-assembly.xlsx, solar-glow-drh-v3_0-BOM.xlsx, solar-glow-drh-v3_0.kicad_sch]
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2026-07-10 firmware: STOP on byte-read bus faults; fix stale version + ballast figure
    Full-package review pass. No correctness bugs found in the verifiable logic
    (TWI NACK/address-phase handling, race-free SEI+SLEEP sleep entry, WDT petting
    across glows, ADC power-gating, and the hand-assembled NDEF all check out).
    Two classes of tidy-up applied:
    Robustness / consistency (exercised paths):
    - twi_reg_read (twi.h) and nfc_read_block (nfc.c) returned on a mid-read bus
    fault (BUSERR/ARBLOST) WITHOUT issuing a STOP, leaving the target free to
    clock-stretch -- the exact failure the nfc.c header warns about ("a partial
    read leaves the tag stretching the clock forever"), and inconsistent with
    every ot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
    [main.c, nfc.c, twi.h]
2026-07-10 firmware: fold ADC threshold math to compile time; drop redundant boot probe
    Behavior-neutral efficiency pass (no feature or timing change). Each item was
    proven bit-identical to the code it replaces, not just argued:
    1. Light poll (hot path, ~1/s forever). sense_light() compares the raw VSENSE
    ADC count against a threshold folded to counts at COMPILE time, replacing the
    per-poll 32-bit mV conversion (res*2500>>12, then *2) that fed
    `sense_vin_mv() >= LIGHT_VIN_MV`. Same boolean, zero runtime arithmetic.
    2. Rail-floor check (every glow decision: tap/motion/NFC-ack/light-edge).
    sense_rail_ok() now compares the raw VDD/10 count against a compile-time
    floor, dropping the mV conv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
    [main.c, sense.c]
2026-07-10 firmware: documentary clarity pass -- mark every intentional-but-surprising bit
    Comment/text only; no code lines change (verified: the diff contains no
    non-comment lines). Goal: a future team can't mistake a deliberate choice for a
    bug. Highlights:
    - led.h: CORRECT a dangerous note. It previously said to "drop INVEN" if
    brightness runs backwards -- which would park every LED pad LOW at compare 0
    and light the whole monogram at idle. INVEN is load-bearing for the dark-off
    state; the fix for a backwards bench result is `255 - duty`, not dropping
    INVEN. Now matches the CLAUDE.md gotcha. led_init() gets the same warning at
    its write site.
    - Mark the intentionally-uncalled functions s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
    [board.h, led.c, nfc.c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]
2026-07-10 PCB: fix C13 footprint id (solarglow:C7 -> C13) and C11 value (200nF -> 220nF)
    Two board-file corrections from the PCB audit. Identifier/value strings only,
    no copper/pad/geometry change. Verified by exact single-token git diff, real-C7
    untouched (pcb 7364, sch 3147), and unchanged paren balance in both files.
    C13 footprint id: the footprint carried the stale base-footprint string
    "solarglow:C7" in both the .kicad_pcb block (uuid 355e5d4a) and the .kicad_sch
    Footprint property, a leftover from when C13 was split off C7. Caps are named
    per refdes (solarglow:C1..C12); there was no solarglow:C13 and a duplicated
    solarglow:C7. Renamed C13's footprint id to solarglow:C13 in both files. Also
    clea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
    [solar-glow-drh-v3_0.kicad_pcb, solar-glow-drh-v3_0.kicad_sch]
2026-07-10 PCB: complete C11 value fix on the board side (footprint Value 200nF -> 220nF)
    Follow-up to 5f7a1ed. That commit set C11 = 220nF in the schematic only, but the
    CI BOM sources its Value column from the PCB footprint, which still read "200nF"
    (the C13 footprint-id fix landed in the BOM because it was a pcb-side change; the
    C11 value change was sch-only, so it did not). The regenerated BOM therefore
    still showed 200nF. Corrected the PCB C11 footprint Value to 220nF so schematic
    and board agree, matching the 0.22 uF / 220 nF MPN (GRM155R71C224KA12D).
    Line-anchored single-token edit (pcb line 8026); only 200nF in the file; paren
    balance unchanged; no geometry change.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
    [solar-glow-drh-v3_0.kicad_pcb]
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2026-07-11 docs: harmonize firmware/PCB/root docs with source after cross-pillar audit
    Doc/comment corrections surfaced by a cross-pillar harmony audit (firmware /
    PCB / enclosure + the doc web) and adversarially verified. Source files (code,
    schematic, BOM) are unchanged -- only stale narrative is corrected to match
    them. No firmware CODE changed (comments only), so the build is identical.
    Firmware:
    - board.h: the FD (PA6) block said the NFC acknowledge glow fires on the
    FALLING edge and "runs the tap glow"; the code fires it on the RISING edge
    (field leaves) and senses BOTH edges -- board.h's own later text and the
    README already said so. Pin-map one-liner "FD-wake, falling" -> "both edges".
    -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
    [board.h, check_consistency.py]
2026-07-11 fix(nfc): bound the NDEF write guard to the sector-0 top, protecting the 0x3A config block
    nfc_write_ndef's only overflow guard was `blk > NFC_BLK_EEPROM_TOP` with
    NFC_BLK_EEPROM_TOP = 0x7A. But this driver writes the NDEF linearly from block
    0x01 with no sector-select, and the configuration-register block sits at 0x3A --
    BELOW 0x7A. So a long-enough NDEF (>= ~912 B, i.e. reaching block 0x3A) would be
    written straight through the config registers instead of being rejected; the
    guard could never fire in time because 0x7A is above the block it needed to
    protect. The constant was also internally inconsistent with the driver's own
    memory model (CC-declared 872 B sector-0 area, config at 0x3A).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
    [nfc.c]
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2026-07-11 PCB: nudge the 4 panel-corner mounting holes to a clean symmetric grid
    The 4 GND mounting holes at the solar-panel inner corners were placed
    roughly -- the two holes of each panel disagreed in y by ~0.9 mm. Snap
    them to the corner-mount columns (x 3.0 / 47.8) at the panel inner edges
    (y 28.5 / 60.4), giving a symmetric two-column, 8-hole pattern:
    W-PV1 (2.88, 28.81) -> (3.0, 28.5)
    E-PV1 (47.79, 29.76) -> (47.8, 28.5)
    W-PV2 (2.92, 59.63) -> (3.0, 60.4)
    E-PV2 (47.67, 60.52) -> (47.8, 60.4)
    Holes are 3.6 mm copper / 2.2 mm drill, already on GND. At the new spots
    the copper clears the board edge by 1.2 mm, the NFC coil keepout by
    1.2-1.3 mm (the two east holes sit just N/S of it),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
    [solar-glow-drh-v3_0.kicad_pcb]
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2026-07-11 PCB: consolidate passives -- merge 3 values, DNP 2 parts (coordinated)
    Reduces the passive BOM by 2 placed parts and 3 distinct values (15 -> 12),
    applied coherently across board, schematic, README BOM table, and both
    .xlsx masters so nothing drifts.
    Value merges (un-locked, re-set):
    - C4 1 uF -> 4.7 uF (joins C13; identical 0402 land)
    - C5 10 nF -> 100 nF (joins the 100 nF group; firmware never depends on
    its RC filter -- VSENSE is polled ~1x/s)
    - R14 100 k -> 1 M (joins the R5/R6 reel; NFC_EN pulldown, non-critical)
    DNP (drop from the placed/ordered BOM):
    - R13 (FD pull-up) -- redundant; the MCU's internal PA6 pull-up holds FD
    - C10 (VCMP decoupling)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
    [solar-glow-drh-v3_0-BOM-assembly.xlsx, solar-glow-drh-v3_0-BOM.xlsx, solar-glow-drh-v3_0.kicad_pcb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]
2026-07-11 accel INT1/INT2 swap: sync schematic + firmware + docs to the rerouted board
    The board was rerouted (INT1->PF0, INT2->PF1) and uploaded; this brings the
    rest of the sources in line so board <-> schematic <-> board.h all agree.
    - schematic: swap the two MCU-side INT global labels -> U1 PF0 on net INT1,
    PF1 on net INT2 (matches the board's pad nets).
    - firmware: board.h ACC_INT1_bm/ACC_INT2_bm (PIN1<->PIN0) + the pin-table net
    column (parsed by check_consistency.py); main.c / adxl367.h comment sweep.
    No logic change.
    - docs: firmware/README pin table + wake list (PF0 = tap/INT1, PF1 = motion/INT2).
    Verified board (U1 pad20/PF0->INT1, pad21/PF1->INT2) == schematic == board.h.
    Supersedes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
    [solar-glow-drh-v3_0.kicad_sch]
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2026-07-12 enclosure: regenerate STEP/STL/drawings from the synced generators
    Actually produce the binary artifacts PR #21 deferred. Ran the four generators
    against the committed board and refreshed all 11 output files.
    Backshell generator bug fix (required for it to run at all):
    - _lip_inner_pts / _lip_break_cut hard-coded a two-band east-lip polygon via
    EAST_WIDE_Y[0] and [1]. The 2026-07-11 edit that removed the north wide band
    left EAST_WIDE_Y with a single band, so EAST_WIDE_Y[1] raised IndexError and
    the generator could not run. Rebuilt the notched east edge from EAST_WIDE_Y
    generically (_lip_void_P), correct for 1 or 2 bands. Consequence: the committed
    STEP had been frozen at the old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
    [solar-glow-drh-diffuser-brace.step, solar-glow-drh-diffuser-brace.stl, solar-glow-drh-v3_0-backshell-0p6b-brace-Ti-max-progwindow.step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]
2026-07-12 enclosure: fix backshell recess-mouth "semi-moon" crescents at the panel-corner mounts
    _recess_mouth_ease() stamped a corner-relief circle (r = R + corner_clr = 3.15) at EVERY entry in
    `mounts`. That is right for the 4 board-corner mounts (where build() actually cuts the corner_clr
    relief), but the 4 panel-corner mounts sit mid-edge -- so each circle bulged a semicircle into the
    recess-mouth outline and cut a ~0.20 mm crescent into the top lip at y28.5 / y60.4 on both side walls.
    Restrict the relief circles to the 4 true corners [(R,R),(W-R,R),(R,H-R),(W-R,H-R)] -- the same set
    build() relieves. Verified old-vs-new by point classification: the recess-mouth wall edge at the two
    panel-mount r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
    [solar-glow-drh-v3_0-backshell-0p6b-brace-Ti-max-progwindow.step, solar-glow-drh-v3_0-backshell-0p6b-brace-Ti-max-progwindow.stl, solar-glow-drh-v3_0-backshell-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]
2026-07-12 enclosure: regenerate brace -- SW leg reconnected via the U6 board nudge
    The west-rail south leg was a fully separate solid (U6's through-pocket + the
    (3,28.5) panel-corner boss relief spanned the full rail at y29.9-30.3). You
    moved U6 east to (9.64, 32.03) -- fully clear of the west rail (x<=6.75) -- so
    only the boss relief now touches the rail. Regenerated against the committed
    board and verified:
    - brace is 1 connected component (was 2)
    - west-rail leg web ~0.70 mm at the narrowest (boss center), widening to 0.80 mm
    toward the band -- well above the 0.40 mm SLA minimum
    - U6 min part clearance 0.94 mm (to SC1); 49 pockets, 18 bridges, U6/U2 through,
    volume 2.58 cm^3 -- otherwise uncha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
    [solar-glow-drh-diffuser-brace.step, solar-glow-drh-diffuser-brace.stl]
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2026-07-12 firmware: add sun-diary logging and brownout-stretch glow (free roadmap wins)
    Two firmware-roadmap items that reuse reads the ~1 s poll already does, so both
    are effectively free and need no hardware change:
    - Sun diary (USE_SUN_DIARY): bank lifetime whole-hours of strong sun to EEPROM
    whenever the SENSE_SUN_bm tell is set. The in-progress hour is counted in RAM
    and flushed once per banked hour, so EEPROM sees ~one write per sun-hour
    (endurance-safe) rather than one per poll; a full supercap drain forgets at
    most the current sub-hour. New 2-byte cell at EEPROM offset 4, clear of the
    4-byte tap counter at 0. Readable over UPDI, or for the NDEF later.
    - Brownout-stretch glow (USE_B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
    [board.h, main.c, sense.c]
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2026-07-12 firmware: micro-power black box (lowest-rail + power-cycle count) + roadmap disposition
    Completes the field "black box" the sun-diary/temp-log started -- the starvation
    half to go with the heat half:
    - Lowest rail (VS) ever, USE_HEALTH_LOG: sense_vmin_tick() samples VS every
    VMIN_SAMPLE_POLLS (the supercap sags over minutes) and writes the 2-byte EEPROM
    min (offset 7) only on a new low. Erased 0xFFFF is a natural ceiling.
    - Power-cycle (full-drain) count: sense_boot_log() reads+clears RSTCTRL.RSTFR at
    boot and +1's a 2-byte count (offset 9) only on a power-on reset (PORF), so
    watchdog / UPDI / brownout-recovery resets don't inflate it. One write per drain.
    - Both run before the dorm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
    [board.h, main.c, sense.c]
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2026-07-12 firmware: dark-motion mute -- close the pocket-carry drain (Gemini fusion, distilled)
    The motion branch fires a ~1.6 s soft breath on every activity interrupt and
    re-arms, so a charged card jostling in a dark pocket on a walk fires a breath
    every ~2 s and empties the ~15 J tank in minutes -- a real carry-drain that
    face-down dormancy misses unless the card happens to be face-down.
    Fix (USE_DARK_MOTION_MUTE, default on): mute the MOTION soft-breath when the last
    poll saw no light (VSENSE < LIGHT_THRESH = card stowed dark). The deliberate TAP is
    untouched (its branch never checks light), so the monogram still lights when tapped
    in a dark room -- the marquee moment stays; only the incidental m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
    [board.h, main.c]
2026-07-12 firmware: NFC-ack cooldown + Gemini edge-case pass (verified against source)
    Ran Gemini's five "sub-microamp intersection" edge cases against the actual
    firmware .c / netlist / BOM (not the prose docs). One real free fix shipped,
    two captured as doc / v4 items, two were already handled:
    1. WDT reset in the stowed-motion loop -- NOT a bug. The watchdog is petted at
    the main-loop top (above the dark-motion mute) and the RTC PIT wakes the loop
    every 1 s in power-down, so the 8 s dog is fed at least once a second no matter
    what; animations also pet every ~1 ms. The premise doesn't match the loop.
    2. NFC FD interrupt-storm bleed -- REAL, low-severity; FIXED. A phone parked
    in-field k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
    [board.h, main.c]
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2026-07-12 firmware: fix BOD level (0x0A was BOD-off) + guard EEPROM writes vs brownout
    A second-team firmware review found two datasheet-grounded issues in the
    brown-out / EEPROM story; both verified against the committed DS40002315C and
    both catchable before fuses are burned.
    1. BODCFG=0x0A shipped the card with the BOD OFF, not a 1.9 V guard. LVL=0x0 =
    BODLEVEL0 is enabled ONLY during chip erase; in normal operation it "is the
    same as disabling the BOD" (DS40002315C p.207). The lowest real normal-op
    level is LVL=0x1 = 2.45 V. Corrected the fuse to BODCFG=0x2A (2.45 V sampled,
    128 Hz), which sits below the 2.6 V glow floor (never trips a glow-load sag)
    and above the 1.8 V core min, an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
    [board.h, main.c, sense.c]
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2026-07-13 sch: sync C2 to VCMP (comparator decoupling) to match the board
    Reconciles the schematic to the board edit where C2 was moved from the VS
    rail to VCMP to decouple the U4 comparator's diode-OR'd supply (D10/D11).
    The board had C2.1 on VCMP while the schematic still declared it VS, which
    KiCad flagged as a net_conflict and would have silently reverted on the next
    "Update PCB from Schematic".
    Fix: retarget C2's supply-pin global label VS -> VCMP (same one-label pattern
    used for the earlier INT1/INT2 sync). VCMP now carries U4.6 + C2 on both the
    board and the schematic; VS drops one 0402 (still has C1/C4/C6/C7/C12).
    C10 (the reserved DNP VCMP cap) and R13 (reserved DNP FD pull-up) are left in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
    [solar-glow-drh-v3_0.kicad_sch]
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2026-07-15 build: scaffold v4_0 revision (managed-solar); freeze v3_0 as final unmanaged
    Advances the active revision to v4.0 -- the managed-solar redesign (AEM10300
    active harvest). v3.0 (passive diode feed + shunt clamp) is frozen as the final
    unmanaged-solar revision; its files are untouched.
    - Copy the PCB source set + BOM v3_0 -> v4_0 (byte-preserving; pcb stays CRLF;
    KiCad internal project/sheet refs updated to v4_0). v4_0 starts as an exact
    copy of v3_0 and gets reworked from there per the design-notes v4 addendum +
    v4-aem10300-prewiring.md.
    - Point active tooling at v4_0: kibot.yml board/schema, consistency-script
    schematic path. The consistency BOM path stays on the identical v3_0 CSV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
    [solar-glow-drh-v4_0-BOM-assembly.xlsx, solar-glow-drh-v4_0-BOM.xlsx, solar-glow-drh-v4_0.kicad_pcb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]
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2026-07-19 PCB: give the AEM bulk caps valid refdes (CSRC/CINT/CSTO -> C25/C26/C27)
    KiCad's schematic loader rejects letters-only reference designators (they
    have no prefix/number split), so the descriptive CSRC/CINT/CSTO names the
    board carried made the synced schematic fail to load in KiCad 10:
    "Malformed component reference `CSRC`". The PCB editor had tolerated them,
    so this only surfaced once the parts entered the schematic.
    Rename to the next free C-numbers in BOTH the board and the schematic so
    they stay matched: CSRC->C25 (BUFSRC bulk), CINT->C26 (VINT), CSTO->C27
    (STO bulk). Values still describe the role. PCB change is the refdes text
    only, no geometry or routing. Netlist re-reconciled clean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
    [solar-glow-drh-v4_0.kicad_pcb, solar-glow-drh-v4_0.kicad_sch]
2026-07-19 PCB: add pin-to-label stub wires for the v4 schematic parts
    The sync placed the new parts' symbols and global labels correctly but
    missed how this schematic actually wires connectivity: each pin joins its
    global label through a short 5.08 mm stub wire (pin at the symbol origin,
    label 5.08 mm to its left), not by the label sitting on the pin. Without
    the stubs KiCad ERC saw every new pin and label as unconnected (102
    errors), which only surfaced in CI's real KiCad run.
    This finishes the connectivity to match the board:
    - add the 51 missing stub wires (all 13 new parts' connected pins + the
    STO_SNS pin on U1)
    - put the U8/U9 no-connect flags on the pins (they were 5.08 mm off)
    - delete the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
    [solar-glow-drh-v4_0.kicad_sch]
2026-07-19 docs+sch: v4 cleanup after the schematic sync
    Follow-up tidy now that the schematic is synced to the board and CI's
    KiCad ERC/DRC pass:
    - U9 (TPS7A0233) pin names were labeled IN/OUT backwards; corrected to
    1 IN, 2 GND, 3 EN, 4 NC, 5 OUT (net assignments were already right, so
    the board netlist is unchanged, re-reconciled clean).
    - README file tree: the v4_0 board/schematic are the managed-solar rework
    now, not v3.0 copies; the schematic is synced to the board.
    - prewiring + sync-checklist docs: reflect the CSRC/CINT/CSTO to
    C25/C26/C27 refdes rename, and mark the checklist done with a note on
    the pin-stub-wire wiring convention.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
    [solar-glow-drh-v4_0.kicad_sch]
2026-07-19 ci: point the BOM parity check at the v4_0 BOM
    The consistency guard compared the netlist against the frozen v3_0 BOM,
    which was correct only while v4_0 was a byte copy of v3_0. The schematic
    sync diverged the v4_0 netlist (clamp/blocking parts removed, AEM island
    added), so the v3_0 BOM now lists 12 parts the netlist no longer has.
    Do the lockstep bump the file comment already called for: read the
    CI-regenerated v4_0 BOM. Verified its 42 refs are all real components in
    the synced schematic (no phantom lines).
    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
    [check_consistency.py]
2026-07-19 PCB: snap v4 schematic parts onto the 1.27mm connection grid
    The 13 AEM island parts were placed at an off-grid origin (460, 372),
    which tripped ~60 KiCad endpoint_off_grid ERC warnings (every new pin,
    stub-wire end, and label). Nudge them by (-0.26, +0.11) mm so every new
    pin and wire-end lands on the 1.27mm connection grid the rest of the
    sheet uses. Also snapped JP1 and TP1, which were off-grid in Y since v3
    (pre-existing). Netlist is unchanged (labels stay on their pins), so no
    PCB re-sync is needed; re-reconciled clean against the board.
    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
    [solar-glow-drh-v4_0.kicad_sch]
2026-07-19 PCB: point SC1-4 footprint field at the real SCHURTER lands
    The supercap symbols still carried the placeholder footprint field
    (solarglow:SCx), which the board never used, causing the four
    "cannot add SC" errors in Update-PCB and the footprint_symbol_mismatch /
    missing-MPN / BOM-attr DRC warnings. Set each to the land the board
    actually uses: SC1/SC3 -> Downloads:SCHURTER_SCPC_SS17 (1.8 F SS17),
    SC2/SC4 -> Downloads:SCHURTER_SCPC_WS17-mod2 (1.0 F WS17). After a re-run
    of Update PCB from Schematic the supercaps link cleanly and their fields
    sync, clearing those DRC warnings. (The Downloads library is Devin's
    local nickname; a later cleanup can move these lands into solarglow: for
    portability.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
    [solar-glow-drh-v4_0.kicad_sch]
2026-07-19 PCB: mark the 5 board-only footprints, refdes the panel anchor pads
    Clears the 9 DRC footprint errors (4 duplicate_footprints + 5
    extra_footprint) on the mechanical features that have no schematic
    symbol:
    - the 4 plated GND thru-hole anchor pads at the PV1/PV2 corners get real
    refdes MP1..MP4 (they shared an empty designator, which read as
    duplicates) plus the board_only attribute
    - the NPTH_mech mounting pattern at the origin gets the board_only
    attribute
    board_only ("not in schematic") tells DRC these are intentional
    board-only features, so extra_footprint stops firing; the unique MP
    refdes stop duplicate_footprints. Also flagged exclude_from_pos_files /
    exclude_from_bom since they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
    [solar-glow-drh-v4_0.kicad_pcb]
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2026-07-19 PCB: fix U8 AEM10300 EP land to datasheet; relabel stay-0402 parts
    U8 (AEM10300, QFN-28 4x4): the reused AVR land carried a 2.65 mm exposed
    pad; e-peas Fig 18 recommends a 2.30 mm thermal land. Shrink U8's EP to
    2.30 mm (scoped to U8 only; U1 keeps its 2.65 mm EP). Pad centres are
    unchanged so routing is intact, and the smaller EP increases pad-to-EP
    clearance. Perimeter pads stay 0.20 mm wide (0.25 mm would drop the
    pitch gap to 0.15 mm, below a safe margin over the 0.126 mm floor).
    Relabel the three parts that stay 0402 (the package markers were
    aspirational TODOs): C26 10uF, C27 10uF (100uF is not an 0402 part and
    the 1F supercaps already meet the AEM STO >=100uF minimum), FB1 ferrite.
    V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
    [solar-glow-drh-v4_0.kicad_pcb, solar-glow-drh-v4_0.kicad_sch]
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

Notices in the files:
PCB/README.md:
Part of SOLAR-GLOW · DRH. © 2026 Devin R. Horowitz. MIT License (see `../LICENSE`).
